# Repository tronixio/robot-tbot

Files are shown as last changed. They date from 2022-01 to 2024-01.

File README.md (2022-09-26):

# ROBOT - TBOT 2 Wheels.

## TBOT Features.

- 2 Wheels.
- Continuous RC Servos Motors.
- Power 2xCells 18650 Lithium Ion Rechargeable Batteries, with embedded charger.
- [PARALLAX Small Robot Chassis.](https://www.parallax.com/product/700-00022)
- [PARALLAX Feedback 360 High Speed Servo.](https://www.parallax.com/product/900-00360)
- [PARALLAX Small Robot Whell and Tire.](https://www.parallax.com/product/28114)
- [PARALLAX 1" Tail Whell Ball.](https://www.parallax.com/product/700-00009)

## TBOT All Schematics.

- [DRAFT - MCU Board PIC-8BIT.](https://github.com/tronixio/robot-tbot/)
- [Charger 2x18650.](https://github.com/tronixio/robot-tbot/blob/main/Kicad/charger/extras/schematic.pdf)
- [DRAFT - IR Wheel.](https://github.com/tronixio/robot-tbot/)
- [Sensor GP2Y.](https://github.com/tronixio/robot-tbot/blob/main/Kicad/gp2y/extras/schematic.pdf)
- [DRAFT - Sensor HC-SR04.](https://github.com/tronixio/robot-tbot/)
- [DRAFT - IR Line Folllow.](https://github.com/tronixio/robot-tbot/)

## TBOT Code.

- [PIC16F1778 - MCU & GPIO Configuration.](https://github.com/tronixio/robot-tbot/blob/main/Code/configuration/)
- [PIC16F1778 - EUSART TX - Display Strings.](https://github.com/tronixio/robot-tbot/blob/main/Code/eusart-tx/)
- [PIC16F1778 - EUSART TX/RX - Echo RX Character.](https://github.com/tronixio/robot-tbot/blob/main/Code/eusart-txrx/)
- [PIC16F1778 - ADC/TIMER0 - Read, Display & Check Battery Value.](https://github.com/tronixio/robot-tbot/blob/main/Code/adc/)
- [PIC16F1778 - PWM 16-Bit - RC Servo Forward & Backward.](https://github.com/tronixio/robot-tbot/blob/main/Code/pwm/)
- [PIC16F1778 - INT0 - Emergency Switch & LED.](https://github.com/tronixio/robot-tbot/blob/main/Code/int0/)
- [PIC16F1778 - IOC - Sharp GP2Y0D21YK.](https://github.com/tronixio/robot-tbot/blob/main/Code/gp2y0d21yk/)

## TBOT Firmware.

- [DRAFT - PIC16F1778 - PIC-AS - Firmware SHARP GP2Y0D21YK.](https://github.com/tronixio/robot-tbot/blob/main/MplabX/PICAS-P16F1778-GP2Y0D21YK.X/)

<!--
* [PIC16F1778 - XC8 - Firmware DEBUG.](https://github.com/tronixio/robot-tbot/tree/main/MplabX/XC8-P16F1778-DEBUG.X/)
* [TBOT Firmware - Sharp GP2Y0D21YK.](https://github.com/tronixio/robot-tbot/tree/main/MplabX/PICAS-P16F1778-GP2Y0D21YK.X)
* [TBOT Firmware - Sharp GP2Y0A21YK.](https://github.com/tronixio/robot-tbot/tree/main/MplabX/PICAS-P16F1778-GP2Y0A21YK.X)
* [TBOT Firmware - HC SR04.](https://github.com/tronixio/robot-tbot/tree/main/MplabX/PICAS-P16F1778-HCSR04.X)
-->

## DRAFT - TBOT MCU PIC 8Bit Top.

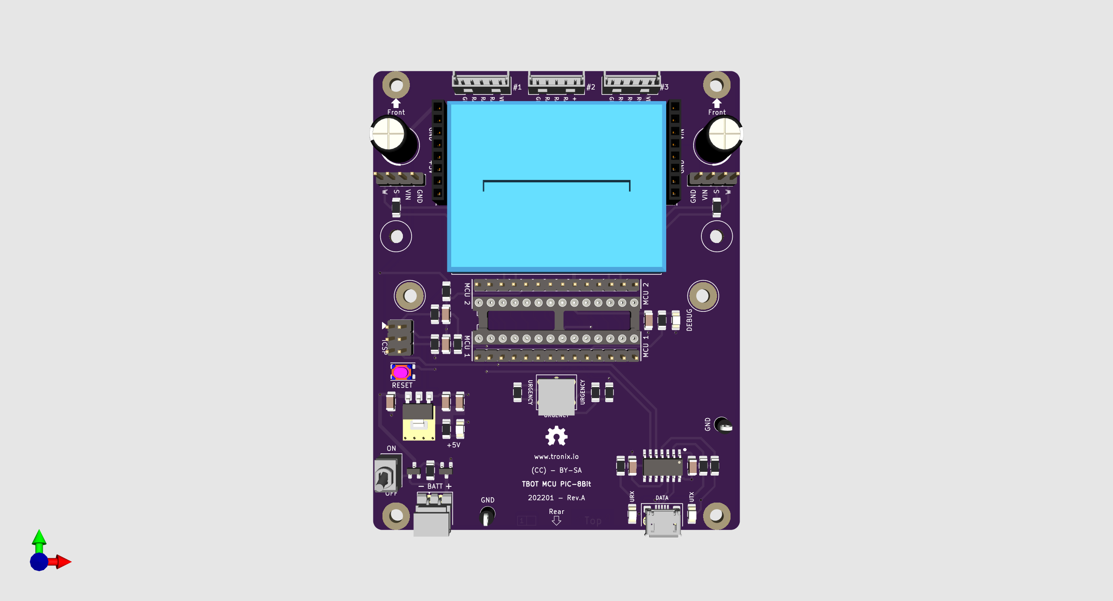
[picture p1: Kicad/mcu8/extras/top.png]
TBOT MCU PIC 8Bit Top.


## DRAFT - TBOT MCU PIC 8Bit Bottom.

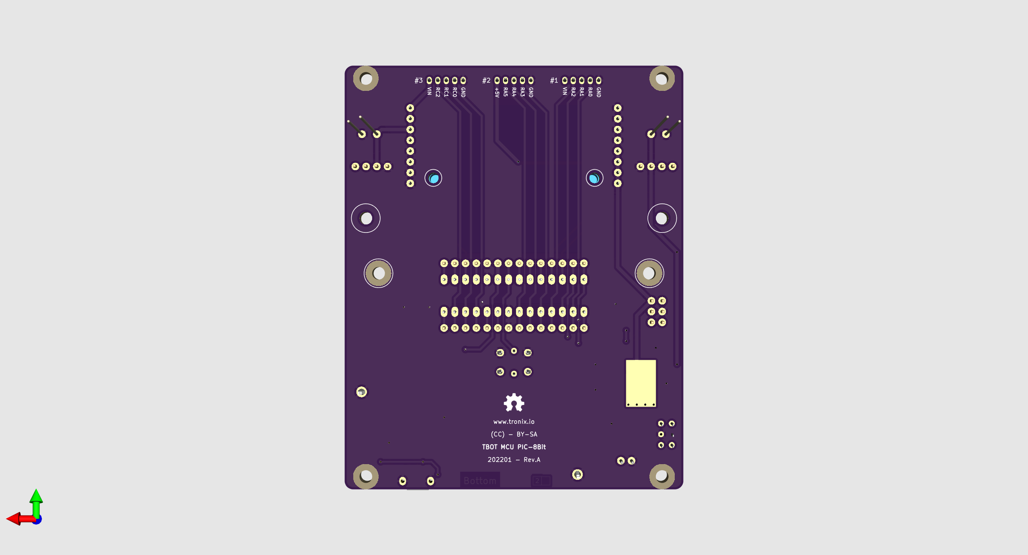
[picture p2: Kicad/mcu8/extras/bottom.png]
TBOT MCU PIC 8Bit Bottom.


## TBOT Charger Top.

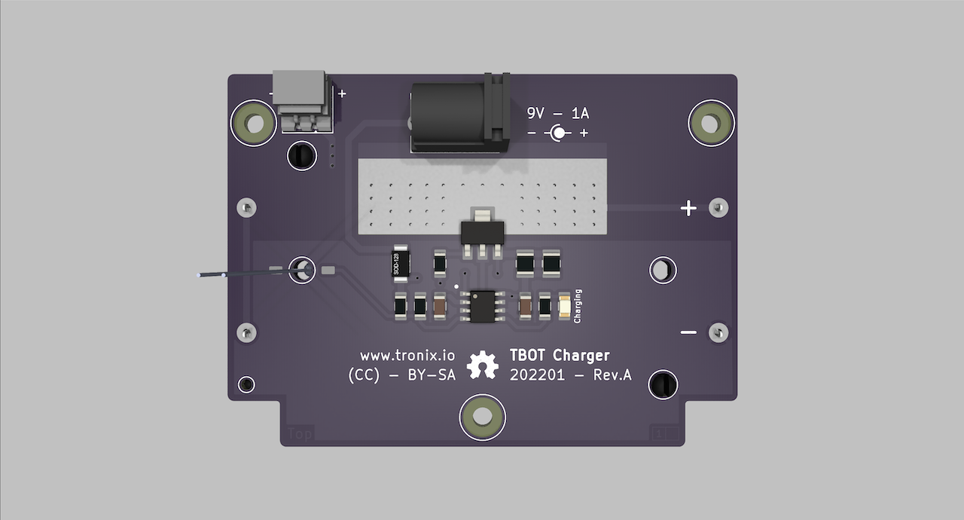
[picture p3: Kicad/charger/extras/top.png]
TBOT Charger Top.


## TBOT Charger Bottom.

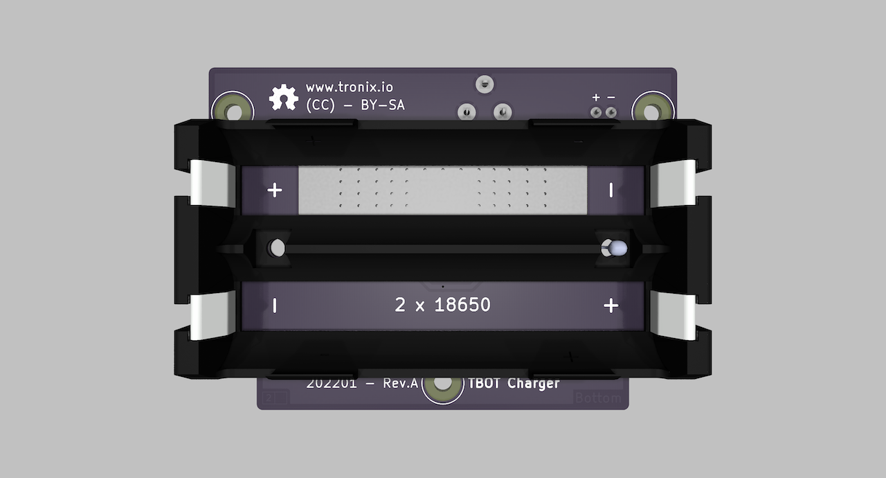
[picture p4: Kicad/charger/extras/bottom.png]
TBOT Charger Bottom.


## DRAFT - TBOT IR Wheel Top.

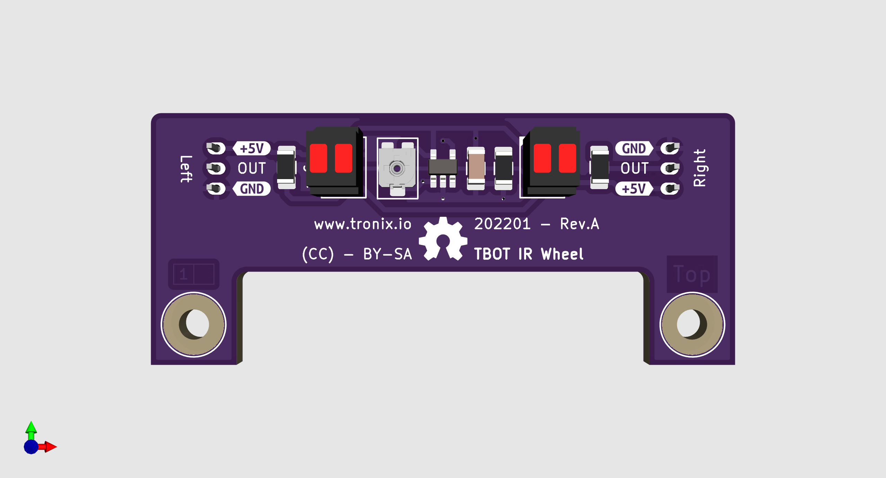
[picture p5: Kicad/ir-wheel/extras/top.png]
TBOT IR Wheel Top.


## DRAFT - TBOT IR Wheel Bottom.

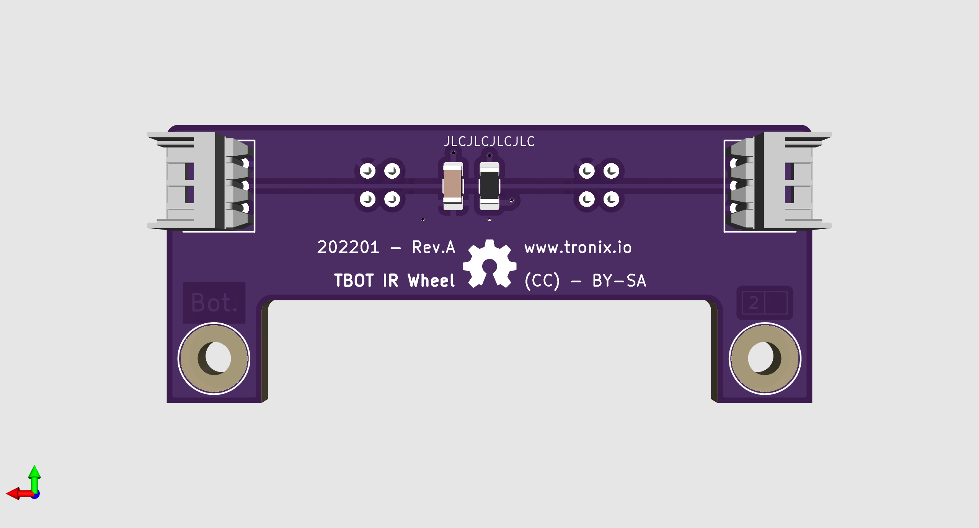
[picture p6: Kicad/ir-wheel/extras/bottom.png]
TBOT IR Wheel Bottom.


## TBOT GP2Y Top.

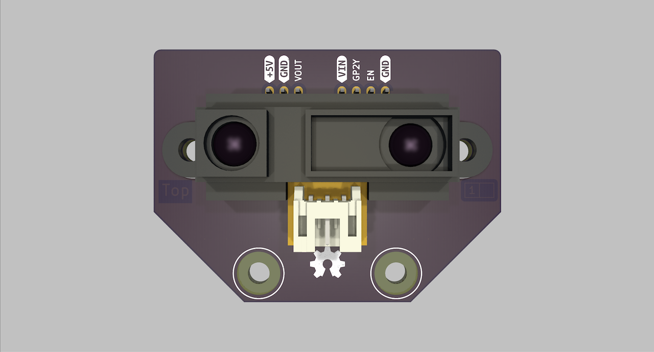
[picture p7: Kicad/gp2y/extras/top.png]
TBOT GP2Y Top.


## TBOT GP2Y Bottom.

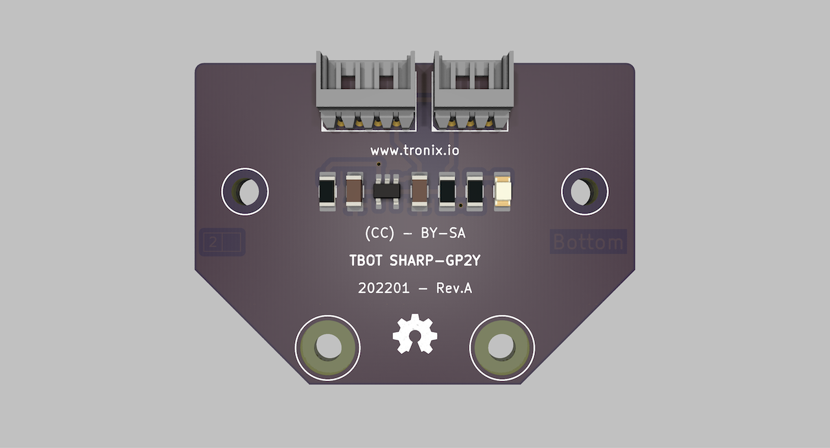
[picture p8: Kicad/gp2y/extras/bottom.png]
TBOT GP2Y Bottom.


## DRAFT - TBOT HC-SR04 Top.

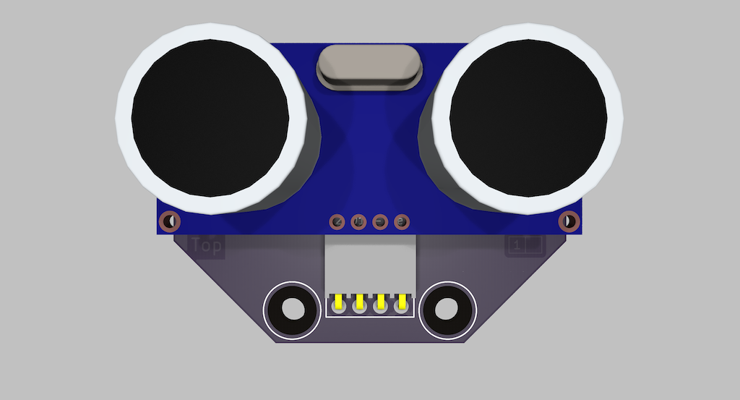
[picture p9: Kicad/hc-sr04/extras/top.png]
TBOT HC-SR04 Top.


## DRAFT - TBOT HC-SR04 Bottom.

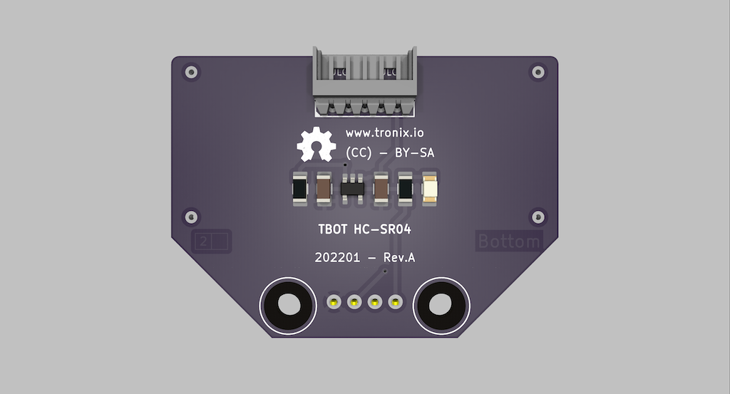
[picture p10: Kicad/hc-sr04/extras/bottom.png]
TBOT HC-SR04 Bottom.


## DRAFT - TBOT IR Line Follow Top.

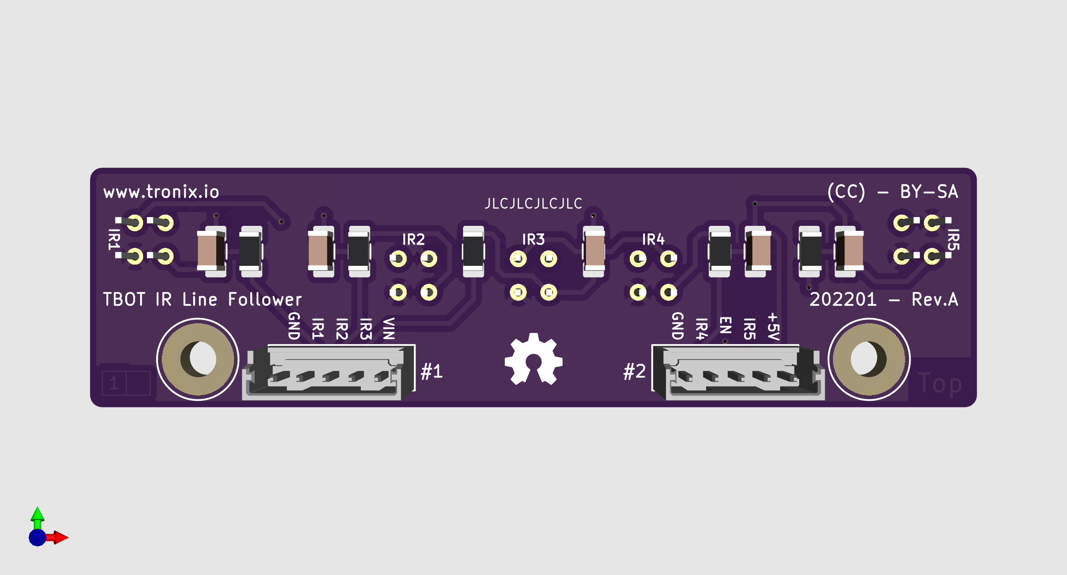
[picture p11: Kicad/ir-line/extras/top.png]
TBOT IR Line Follow Top.


## DRAFT - TBOT IR Line Follow Bottom.

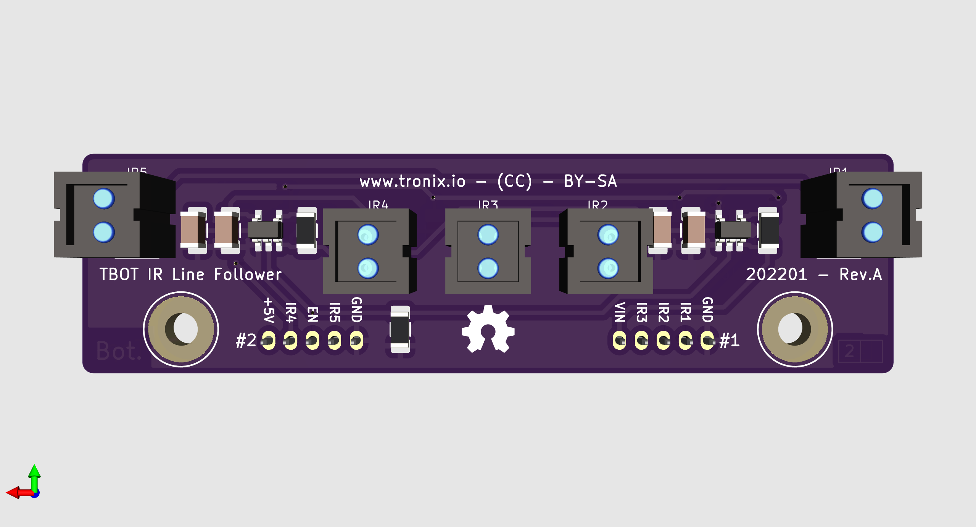
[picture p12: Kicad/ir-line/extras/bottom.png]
TBOT IR Line Follow Bottom.


!!! note

    - DRAFT : Prototype OK, last check schematic, PCB & code can be modify.
    - TODO : Work in progress, prototype was not good, hardware, PCB and code can be rework.

!!! example "DISCLAIMER"

    THIS CODE IS PROVIDED WITHOUT ANY WARRANTY OR GUARANTEES.
    USERS MAY USE THIS CODE FOR DEVELOPMENT AND EXAMPLE PURPOSES ONLY.
    AUTHORS ARE NOT RESPONSIBLE FOR ANY ERRORS, OMISSIONS, OR DAMAGES THAT COULD
    RESULT FROM USING THIS FIRMWARE IN WHOLE OR IN PART.

---

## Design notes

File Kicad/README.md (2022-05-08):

# ROBOT - TBOT 2 Wheels.

- [ROBOT - TBOT 2 Wheels.](https://github.com/tronixio/robot-tbot)

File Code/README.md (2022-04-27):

# ROBOT - TBOT 2 Wheels.

- [TBOT Code.](https://github.com/tronixio/robot-tbot#tbot-code)

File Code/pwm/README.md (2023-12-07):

# PWM - 16-BIT Pulse-Width Modulation Module.

## Code.

- PWM 16-BIT - RC Servo Forward & Backward.

```as
; Configuration Registers.
CONFIG FOSC=INTOSC
CONFIG WDTE=OFF
CONFIG PWRTE=OFF
CONFIG MCLRE=ON
CONFIG CP=OFF
CONFIG BOREN=OFF
CONFIG CLKOUTEN=OFF
CONFIG IESO=OFF
CONFIG FCMEN=OFF
CONFIG WRT=OFF
CONFIG PPS1WAY=ON
CONFIG ZCD=OFF
CONFIG PLLEN=OFF
CONFIG STVREN=ON
CONFIG BORV=LO
CONFIG LPBOR=OFF
CONFIG LVP=ON

#include <xc.inc>
; PIC16F1778 - Compile with PIC-AS(v2.45).
; PIC16F1778 - @8MHz Internal Oscillator.
; -preset_vec=0000h, -pcinit=0005h.
; Instruction ~500ns @8MHz.

; TBOT - PWM.
; RC Servo - Forward 1 second, Stop, Backward 1 second, Stop.

; GPR BANK0.
PSECT cstackBANK0,class=BANK0,space=1,delta=1
u8BANK0:    DS  1

; Common RAM.
PSECT cstackCOMM,class=COMMON,space=1,delta=1
u16DELAY:   DS	2

; MCU Definitions.
; BANKS.
#define	BANK0   0x0
#define	BANK1   0x1
#define	BANK2   0x2
#define	BANK3   0x3
#define	BANK4   0x4
#define	BANK5   0x5
#define	BANK6   0x6
#define	BANK7   0x7
#define	BANK8   0x8
#define	BANK9   0x9
#define	BANK10  0xA
#define	BANK11  0xB
#define	BANK12  0xC
#define	BANK13  0xD
#define	BANK14  0xE
#define	BANK15  0xF
#define	BANK16  0x10
#define	BANK17  0x11
#define	BANK18  0x12
#define	BANK19  0x13
#define	BANK20  0x14
#define	BANK21  0x15
#define	BANK22  0x16
#define	BANK23  0x17
#define	BANK24  0x18
#define	BANK25  0x19
#define	BANK26  0x1A
#define	BANK27  0x1B
#define	BANK28  0x1C
#define	BANK29  0x1D
#define	BANK30  0x1E
#define	BANK31  0x1F
; SFR STATUS Bits.
#define	C	0x0
#define	Z	0x2

; User Definition.
; LED Debug.
#define	LED_DEBUG   0x6
; RC Servo.
; Frequency 50Hz - @8MHz.
#define SERVO_PERIOD_H	78
#define SERVO_PERIOD_L	30
; Duty Cycle.
; H6/L165 - 1.7ms - @8MHz.
; H5/L220 - 1.5ms - @8MHz.
; H5/L20  - 1.3ms - @8MHz.
#define SERVO_STOP_H	5
#define SERVO_STOP_L	220

; Reset Vector.
PSECT reset_vec,class=CODE,space=0,delta=2
resetVector:
    GOTO    main

; Main.
PSECT cinit,class=CODE,space=0,delta=2
main:
    ; MCU Initialization.
    ; Internal Oscillator Settings.
    MOVLB   BANK1
    MOVLW   0b00000000
    MOVWF   OSCTUNE
    MOVLW   0x70
    MOVWF   OSCCON
    BTFSS   HFIOFR
    BRA	    $-1
    ; Ports Settings.
    ; PORT Data Register.
    MOVLB   BANK0
    MOVLW   0b00000000
    MOVWF   PORTA
    MOVLW   0b00000000
    MOVWF   PORTB
    MOVLW   0b00000000
    MOVWF   PORTC
    MOVLW   0b00000000
    MOVWF   PORTE
    ; TRIS Data Direction.
    MOVLB   BANK1
    MOVLW   0b00000000
    MOVWF   TRISA
    MOVLW   0b10011001
    MOVWF   TRISB
    MOVLW   0b01000000
    MOVWF   TRISC
    MOVLW   0b00000000
    MOVWF   TRISE
    ; LATCH Outputs.
    MOVLB   BANK2
    MOVLW   0b00000000
    MOVWF   LATA
    MOVLW   0b00000000
    MOVWF   LATB
    MOVLW   0b00000000
    MOVWF   LATC
    ; ANSEL Analog.
    MOVLB   BANK3
    MOVLW   0b00000000
    MOVWF   ANSELA
    MOVLW   0b00001000
    MOVWF   ANSELB
    MOVLW   0b00000000
    MOVWF   ANSELC
    ; WPU Weak Pull-up.
    MOVLB   BANK4
    MOVLW   0b00000000
    MOVWF   WPUA
    MOVLW   0b00000000
    MOVWF   WPUB
    MOVLW   0b00000000
    MOVWF   WPUC
    MOVLW   0b00000000
    MOVWF   WPUE
    ; ODCON Open-drain.
    MOVLB   BANK5
    MOVLW   0b00000000
    MOVWF   ODCONA
    MOVLW   0b00000000
    MOVWF   ODCONB
    MOVLW   0b00000000
    MOVWF   ODCONC
    ; SRLCON Slew Rate.
    MOVLB   BANK6
    MOVLW   0b11111111
    MOVWF   SLRCONA
    MOVLW   0b11011111
    MOVWF   SLRCONB
    MOVLW   0b11011111
    MOVWF   SLRCONC
    ; INLVL Input Level.
    MOVLB   BANK7
    MOVLW   0b00000000
    MOVWF   INLVLA
    MOVLW   0b00000000
    MOVWF   INLVLB
    MOVLW   0b00000000
    MOVWF   INLVLC
    ; HIDRVB High Drive.
    MOVLB   BANK8
    MOVLW   0b00000000
    MOVWF   HIDRVB
    ; PPS Settings.
    ; PPS Write Enable.
    MOVLB   BANK28
    MOVLW   0x55
    MOVWF   PPSLOCK
    MOVLW   0xAA
    MOVWF   PPSLOCK
    BCF	    PPSLOCK, 0x0
    ; PPS Outputs.
    MOVLB   BANK29
    ; RB5 - PWM11.
    MOVLW   0x1F
    MOVWF   RB5PPS
    ; RC5 - PWM6.
    MOVLW   0x1E
    MOVWF   RC5PPS
    ; PPS Write Disable.
    MOVLB   BANK28
    MOVLW   0x55
    MOVWF   PPSLOCK
    MOVLW   0xAA
    MOVWF   PPSLOCK
    BSF	    PPSLOCK, 0x0

    ; PWM6 Settings.
    MOVLB   BANK27
    CLRF    PWM6PHL
    CLRF    PWM6PHH
    MOVLW   SERVO_STOP_L
    MOVWF   PWM6DCL
    MOVLW   SERVO_STOP_H
    MOVWF   PWM6DCH
    MOVLW   SERVO_PERIOD_L
    MOVWF   PWM6PRL
    MOVLW   SERVO_PERIOD_H
    MOVWF   PWM6PRH
    CLRF    PWM6OFL
    CLRF    PWM6OFH
    CLRF    PWM6TMRL
    CLRF    PWM6TMRH
    MOVLW   0x0C
    MOVWF   PWM6CON
    MOVLW   0x00
    MOVWF   PWM6INTE
    MOVLW   0x00
    MOVWF   PWM6INTF
    MOVLW   0x20
    MOVWF   PWM6CLKCON
    MOVLW   0x00
    MOVWF   PWM6LDCON
    MOVLW   0x00
    MOVWF   PWM6OFCON
    ; PWM6 Load & Enable.
    BSF	    PWM6LD
    BSF	    PWM6EN

    ; PWM11 Settings.
    MOVLB   BANK27
    CLRF    PWM11PHL
    CLRF    PWM11PHH
    MOVLW   SERVO_STOP_L
    MOVWF   PWM11DCL
    MOVLW   SERVO_STOP_H
    MOVWF   PWM11DCH
    MOVLW   SERVO_PERIOD_L
    MOVWF   PWM11PRL
    MOVLW   SERVO_PERIOD_H
    MOVWF   PWM11PRH
    CLRF    PWM11OFL
    CLRF    PWM11OFH
    CLRF    PWM11TMRL
    CLRF    PWM11TMRH
    MOVLW   0x0C
    MOVWF   PWM11CON
    MOVLW   0x00
    MOVWF   PWM11INTE
    MOVLW   0x00
    MOVWF   PWM11INTF
    MOVLW   0x20
    MOVWF   PWM11CLKCON
    MOVLW   0x00
    MOVWF   PWM11LDCON
    MOVLW   0x00
    MOVWF   PWM11OFCON
    ; PWM11 Load & Enable.
    BSF	    PWM11LD
    BSF	    PWM11EN

loop:
    ; RC Servos Forward.
    MOVLB   BANK27
    MOVLW   20
    MOVWF   PWM6DCL
    MOVLW   5
    MOVWF   PWM6DCH
    MOVLW   165
    MOVWF   PWM11DCL
    MOVLW   6
    MOVWF   PWM11DCH
    MOVLW   0x6
    MOVWF   PWMLD
    MOVLW   10
    CALL    _u16Delay

    ; RC Servos Stop.
    MOVLB   BANK27
    MOVLW   SERVO_STOP_L
    MOVWF   PWM6DCL
    MOVLW   SERVO_STOP_H
    MOVWF   PWM6DCH
    MOVLW   SERVO_STOP_L
    MOVWF   PWM11DCL
    MOVLW   SERVO_STOP_H
    MOVWF   PWM11DCH
    MOVLW   0x6
    MOVWF   PWMLD
    MOVLW   10
    CALL    _u16Delay

    ; RC Servos Backward.
    MOVLB   BANK27
    MOVLW   165
    MOVWF   PWM6DCL
    MOVLW   6
    MOVWF   PWM6DCH
    MOVLW   20
    MOVWF   PWM11DCL
    MOVLW   5
    MOVWF   PWM11DCH
    MOVLW   0x6
    MOVWF   PWMLD
    MOVLW   10
    CALL    _u16Delay

    ; RC Servos Stop.
    MOVLB   BANK27
    MOVLW   SERVO_STOP_L
    MOVWF   PWM6DCL
    MOVLW   SERVO_STOP_H
    MOVWF   PWM6DCH
    MOVLW   SERVO_STOP_L
    MOVWF   PWM11DCL
    MOVLW   SERVO_STOP_H
    MOVWF   PWM11DCH
    MOVLW   0x6
    MOVWF   PWMLD
    MOVLW   10
    CALL    _u16Delay

    BRA	    $

; Functions.
_u16Delay:
    MOVWF   u16DELAY
    MOVLW   255
    MOVWF   u16DELAY + 1
    MOVLW   255
    DECFSZ  WREG, F
    BRA	    $-1
    DECFSZ  u16DELAY + 1, F
    BRA	    $-3
    DECFSZ  u16DELAY, F
    BRA	    $-5
    RETURN

    END resetVector
```

## Oscilloscope.

### Stop.

- MCU.RC5.PWM.6  -> Oscilloscope Probe A
- MCU.RB5.PWM.11 -> Oscilloscope Probe B

<p align="center">
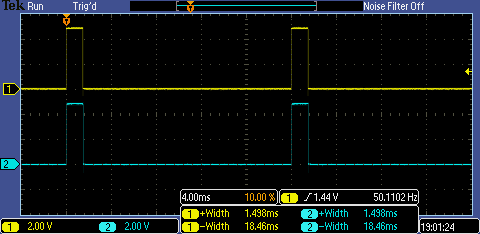
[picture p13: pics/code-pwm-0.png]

</p>

### Forward.

- MCU.RC5.PWM.6  -> Oscilloscope Probe A
- MCU.RB5.PWM.11 -> Oscilloscope Probe B

<p align="center">
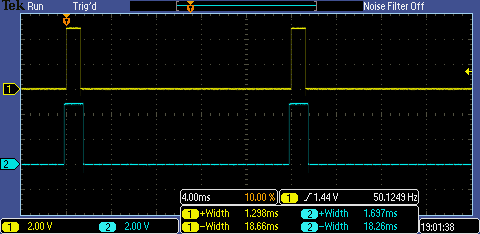
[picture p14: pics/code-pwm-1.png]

</p>

### Backward.

- MCU.RC5.PWM.6  -> Oscilloscope Probe A
- MCU.RB5.PWM.11 -> Oscilloscope Probe B

<p align="center">
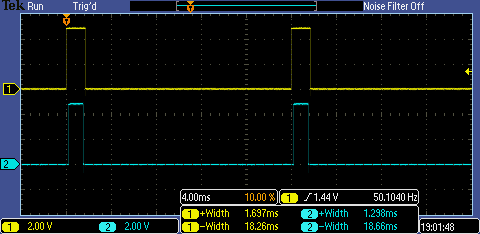
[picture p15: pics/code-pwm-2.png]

</p>

## MPLABX Linker Configuration.

- PIC-AS Linker > Custom linker options: `-preset_vec=0000h, -pcinit=0005h`

## Notes.

- TODO : Work in progress, prototype was not good, hardware, PCB and code can be rework.
- DRAFT : Prototype OK, last check schematic, PCB & code can be modify.

## DISCLAIMER.

THIS CODE IS PROVIDED WITHOUT ANY WARRANTY OR GUARANTEES.
USERS MAY USE THIS CODE FOR DEVELOPMENT AND EXAMPLE PURPOSES ONLY.
AUTHORS ARE NOT RESPONSIBLE FOR ANY ERRORS, OMISSIONS, OR DAMAGES THAT COULD
RESULT FROM USING THIS FIRMWARE IN WHOLE OR IN PART.

---

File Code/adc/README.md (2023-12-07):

# ADC - 10-Bit Analog-to-Digital Converter.

## Code.

- ADC/TIMER0 - Read, Display & Check Battery Value.

```as
; Configuration Registers.
CONFIG FOSC=INTOSC
CONFIG WDTE=OFF
CONFIG PWRTE=OFF
CONFIG MCLRE=ON
CONFIG CP=OFF
CONFIG BOREN=OFF
CONFIG CLKOUTEN=OFF
CONFIG IESO=OFF
CONFIG FCMEN=OFF
CONFIG WRT=OFF
CONFIG PPS1WAY=ON
CONFIG ZCD=OFF
CONFIG PLLEN=OFF
CONFIG STVREN=ON
CONFIG BORV=LO
CONFIG LPBOR=OFF
CONFIG LVP=ON

#include <xc.inc>
; PIC16F1778 - Compile with PIC-AS(v2.45).
; PIC16F1778 - @8MHz Internal Oscillator.
; -preset_vec=0000h, -pstringtext=3FB0h.
; Instruction ~500ns @8MHz.

; TBOT - ADC/TIMER0.

; ADC - Read Battery Voltage.
; TIMER0 - ADC Auto-convertion Trigger Source.
; EUSART TX - Display Battery value.

; Battery Voltage: 8V4 -> 0xF7.
; Battery Voltage: 6V2 -> 0xB7.

; GPR BANK0.
PSECT cstackBANK0,class=BANK0,space=1,delta=1
u32Ascii:   DS  4

; Common RAM.
PSECT cstackCOMM,class=COMMON,space=1,delta=1
u16DELAY:   DS	2

; MCU Definitions.
; BANKS.
#define	BANK0   0x0
#define	BANK1   0x1
#define	BANK2   0x2
#define	BANK3   0x3
#define	BANK4   0x4
#define	BANK5   0x5
#define	BANK6   0x6
#define	BANK7   0x7
#define	BANK8   0x8
#define	BANK9   0x9
#define	BANK10  0xA
#define	BANK11  0xB
#define	BANK12  0xC
#define	BANK13  0xD
#define	BANK14  0xE
#define	BANK15  0xF
#define	BANK16  0x10
#define	BANK17  0x11
#define	BANK18  0x12
#define	BANK19  0x13
#define	BANK20  0x14
#define	BANK21  0x15
#define	BANK22  0x16
#define	BANK23  0x17
#define	BANK24  0x18
#define	BANK25  0x19
#define	BANK26  0x1A
#define	BANK27  0x1B
#define	BANK28  0x1C
#define	BANK29  0x1D
#define	BANK30  0x1E
#define	BANK31  0x1F
; SFR STATUS Bits.
#define	C	0x0
#define	Z	0x2

; User Definition.
; LED Debug.
#define	LED_DEBUG	0x6
; Battery Definitions.
#define	BATTERY_LOW	0xB7

; Reset Vector.
PSECT reset_vec,class=CODE,space=0,delta=2
resetVector:
    GOTO    main

; Main.
PSECT cinit,class=CODE,space=0,delta=2
main:
    ; MCU Initialization.
    ; Internal Oscillator Settings.
    MOVLB   BANK1
    MOVLW   0b00000000
    MOVWF   OSCTUNE
    MOVLW   0x70
    MOVWF   OSCCON
    BTFSS   HFIOFR
    BRA	    $-1
    ; Ports Settings.
    ; PORT Data Register.
    MOVLB   BANK0
    MOVLW   0b00000000
    MOVWF   PORTA
    MOVLW   0b00000000
    MOVWF   PORTB
    MOVLW   0b00000000
    MOVWF   PORTC
    MOVLW   0b00000000
    MOVWF   PORTE
    ; TRIS Data Direction.
    MOVLB   BANK1
    MOVLW   0b00000000
    MOVWF   TRISA
    MOVLW   0b10001000
    MOVWF   TRISB
    MOVLW   0b00000000
    MOVWF   TRISC
    MOVLW   0b00000000
    MOVWF   TRISE
    ; LATCH Outputs.
    MOVLB   BANK2
    MOVLW   0b00000000
    MOVWF   LATA
    MOVLW   0b00000000
    MOVWF   LATB
    MOVLW   0b00000000
    MOVWF   LATC
    ; ANSEL Analog.
    MOVLB   BANK3
    MOVLW   0b00000000
    MOVWF   ANSELA
    MOVLW   0b00001000
    MOVWF   ANSELB
    MOVLW   0b00000000
    MOVWF   ANSELC
    ; WPU Weak Pull-up.
    MOVLB   BANK4
    MOVLW   0b00000000
    MOVWF   WPUA
    MOVLW   0b00000000
    MOVWF   WPUB
    MOVLW   0b00000000
    MOVWF   WPUC
    MOVLW   0b00000000
    MOVWF   WPUE
    ; ODCON Open-drain.
    MOVLB   BANK5
    MOVLW   0b00000000
    MOVWF   ODCONA
    MOVLW   0b00000000
    MOVWF   ODCONB
    MOVLW   0b00000000
    MOVWF   ODCONC
    ; SRLCON Slew Rate.
    MOVLB   BANK6
    MOVLW   0b11111111
    MOVWF   SLRCONA
    MOVLW   0b11111111
    MOVWF   SLRCONB
    MOVLW   0b11111111
    MOVWF   SLRCONC
    ; INLVL Input Level.
    MOVLB   BANK7
    MOVLW   0b00000000
    MOVWF   INLVLA
    MOVLW   0b00000000
    MOVWF   INLVLB
    MOVLW   0b00000000
    MOVWF   INLVLC
    ; HIDRVB High Drive.
    MOVLB   BANK8
    MOVLW   0b00000000
    MOVWF   HIDRVB
    ; PPS Settings.
    ; PPS Write Enable.
    MOVLB   BANK28
    MOVLW   0x55
    MOVWF   PPSLOCK
    MOVLW   0xAA
    MOVWF   PPSLOCK
    BCF	    PPSLOCK, 0x0
    ; PPS Outputs.
    MOVLB   BANK29
    ; RB6 - EUSART.UTX.
    MOVLW   0x24
    MOVWF   RB6PPS
    ; PPS Write Disable.
    MOVLB   BANK28
    MOVLW   0x55
    MOVWF   PPSLOCK
    MOVLW   0xAA
    MOVWF   PPSLOCK
    BSF	    PPSLOCK, 0x0

    ; ADC Settings.
    ; TIMER0 Overflow Trigger.
    ; Left Justified, FOSC/16.
    MOVLB   BANK9
    CLRF    ADRESL
    CLRF    ADRESH
    MOVLW   0x24
    MOVWF   ADCON0
    MOVLW   0x50
    MOVWF   ADCON1
    MOVLW   0x02
    MOVWF   ADCON2
    ; ADC Enable.
    BSF	    ADON

    ; EUSART Settings.
    ; 9600,8,N,1.
    MOVLB   BANK3
    CLRF    RC1REG
    CLRF    TX1REG
    MOVLW   12
    MOVWF   SP1BRGL
    CLRF    SP1BRGH
    MOVLW   0x10
    MOVWF   RC1STA
    MOVLW   0x20
    MOVWF   TX1STA
    MOVLW   0x00
    MOVWF   BAUD1CON
    ; EUSART Enable.
    BSF	    SPEN

    ; OPTION REG Settings.
    ; WPU Enabled.
    ; TIMER0 ~15Hz.
    MOVLB   BANK1
    MOVLW   0b01010111
    MOVWF   OPTION_REG

    ; EUSART Display Strings.
    CALL    _writeStringTRONIX
    CALL    _writeStringURL
    CALL    _writeStringTBOT
    CALL    _writeStringREADY

loop:
    ; Check Battery Voltage Low.
    MOVLW   BATTERY_LOW
    MOVLB   BANK9
    SUBWF   ADRESH, W
    BTFSC   STATUS, C
    BRA	    $+6
    CALL    _writeStringREADY
    CALL    _writeStringBATTERYLOW
    MOVLW   10
    CALL    _u16Delay
    BRA	    loop

    ; Display Battery Value.
    CALL    _writeStringREADY
    MOVLW   '0'
    CALL    _eusartTX
    MOVLW   'x'
    CALL    _eusartTX
    MOVLB   BANK9
    MOVF    ADRESH, W
    CALL    _hex2ascii
    CALL    _writeStringASCII
    MOVLW   10
    CALL    _u16Delay

    BRA	    loop

; Functions.
_u16Delay:
    MOVWF   u16DELAY
    MOVLW   255
    MOVWF   u16DELAY + 1
    MOVLW   255
    DECFSZ  WREG, F
    BRA	    $-1
    DECFSZ  u16DELAY + 1, F
    BRA	    $-3
    DECFSZ  u16DELAY, F
    BRA	    $-5
    RETURN

_eusartTX:
    MOVLB   BANK3
    MOVWF   TX1REG
    MOVLB   BANK0
    BTFSS   TXIF
    BRA	    $-1
    RETURN

_eusartTXString:
    MOVIW   FSR0++
    ANDLW   0xFF
    BTFSC   STATUS, Z
    RETURN
    CALL    _eusartTX
    BRA	    $-5

_hex2ascii:
    MOVLB   BANK0
    MOVWF   u32Ascii
    ANDLW   0x0F
    CALL    $+9
    MOVWF   u32Ascii + 2
    SWAPF   u32Ascii, F
    MOVF    u32Ascii, W
    ANDLW   0x0F
    CALL    $+4
    MOVWF   u32Ascii + 1
    CLRF    u32Ascii + 3
    RETURN
    ; Decimal or Alpha ?
    SUBLW   0x09
    BTFSS   STATUS, C
    BRA	    $+5
    ; Decimal (0...9) add 0x30.
    MOVF    u32Ascii, W
    ANDLW   0x0F
    ADDLW   0x30
    RETURN
    ; Alpha (A...F) add 0x37.
    MOVF    u32Ascii, W
    ANDLW   0x0F
    ADDLW   'A' - 0x0A
    RETURN

_writeStringASCII:
    MOVLB   BANK0
    MOVLW   u32Ascii + 1
    MOVWF   FSR0L
    CLRF    FSR0H
    CALL    _eusartTXString
    RETURN

_writeStringBATTERYLOW:
    MOVLW   LOW stringBATTERYLOW
    MOVWF   FSR0L
    MOVLW   HIGH stringBATTERYLOW + 0x80
    MOVWF   FSR0H
    CALL    _eusartTXString
    RETURN

_writeStringREADY:
    MOVLW   LOW stringREADY
    MOVWF   FSR0L
    MOVLW   HIGH stringREADY + 0x80
    MOVWF   FSR0H
    CALL    _eusartTXString
    RETURN

_writeStringTBOT:
    MOVLW   LOW stringTBOT
    MOVWF   FSR0L
    MOVLW   HIGH stringTBOT + 0x80
    MOVWF   FSR0H
    CALL    _eusartTXString
    RETURN

_writeStringTRONIX:
    MOVLW   LOW stringTRONIX
    MOVWF   FSR0L
    MOVLW   HIGH stringTRONIX + 0x80
    MOVWF   FSR0H
    CALL    _eusartTXString
    RETURN

_writeStringURL:
    MOVLW   LOW stringURL
    MOVWF   FSR0L
    MOVLW   HIGH stringURL + 0x80
    MOVWF   FSR0H
    CALL    _eusartTXString
    RETURN

; FPM Strings.
PSECT stringtext,class=STRCODE,space=0,delta=2

stringBATTERYLOW:
    DB  'B','a','t','t','e','r','y', ' ', 'L', 'o', 'w', '!', 0x0

stringREADY:
    DB  0xD, 0xA, 'R','e','a','d','y','>',' ', 0x0

stringTBOT:
    DB  0xD, 0xA, 'T','B','O','T', 0xD, 0xA, 0x0

stringTRONIX:
    DB  0xD, 0xA, 0xD, 0xA, 'T','r','o','n','i','x',' ','I','/','O','.', 0x0

stringURL:
    DB  0xD, 0xA, 'w','w','w','.','t','r','o','n','i','x','.','c','o','m', 0x0

    END	resetVector
```

## Terminal.

- EUSART TX - Display Strings.
  - Mac OS: `screen /dev/cu.usbmodemXXXXXX`
  
<p align="center">
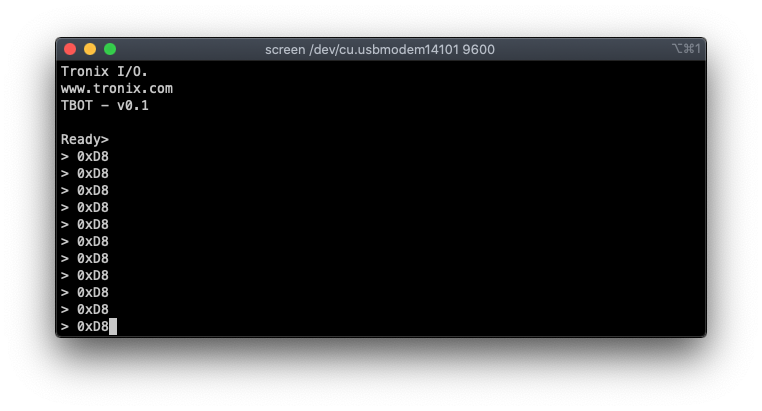
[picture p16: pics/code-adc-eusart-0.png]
MCU.RB6.EUSART.TX

</p>

## MPLABX Linker Configuration.

- PIC-AS Linker > Custom linker options : `-preset_vec=0000h, -pstringtext=3FC0h`

## Notes.

- TODO : Work in progress, prototype was not good, hardware, PCB and code can be rework.
- DRAFT : Prototype OK, last check schematic, PCB & code can be modify.

## DISCLAIMER.

THIS CODE IS PROVIDED WITHOUT ANY WARRANTY OR GUARANTEES.
USERS MAY USE THIS CODE FOR DEVELOPMENT AND EXAMPLE PURPOSES ONLY.
AUTHORS ARE NOT RESPONSIBLE FOR ANY ERRORS, OMISSIONS, OR DAMAGES THAT COULD
RESULT FROM USING THIS FIRMWARE IN WHOLE OR IN PART.

---

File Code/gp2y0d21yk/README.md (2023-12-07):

# IOC - Interrupt-On-Change.

## Code.

- IOC - Sharp GP2Y0D21YK.

```as
; Configuration Registers.
CONFIG FOSC=INTOSC
CONFIG WDTE=OFF
CONFIG PWRTE=OFF
CONFIG MCLRE=ON
CONFIG CP=OFF
CONFIG BOREN=OFF
CONFIG CLKOUTEN=OFF
CONFIG IESO=OFF
CONFIG FCMEN=OFF
CONFIG WRT=OFF
CONFIG PPS1WAY=ON
CONFIG ZCD=OFF
CONFIG PLLEN=OFF
CONFIG STVREN=ON
CONFIG BORV=LO
CONFIG LPBOR=OFF
CONFIG LVP=ON

#include <xc.inc>
; PIC16F1778 - Compile with PIC-AS(v2.45).
; PIC16F1778 - @8MHz Internal Oscillator.
; -preset_vec=0000h, -pintentry=0004h, -pcinit=0005h.
; Instruction ~500ns @8MHz.

; TBOT - IOC - Interrupt On Change.

; Sensor Sharp GP2Y0D21YK - Rising & Falling Edge Detection.

; GPR BANK0.
PSECT cstackBANK0,class=BANK0,space=1,delta=1
u8BANK0:    DS  1

; Common RAM.
PSECT cstackCOMM,class=COMMON,space=1,delta=1
u8DELAY:    DS	1

; MCU Definitions.
; BANKS.
#define	BANK0   0x0
#define	BANK1   0x1
#define	BANK2   0x2
#define	BANK3   0x3
#define	BANK4   0x4
#define	BANK5   0x5
#define	BANK6   0x6
#define	BANK7   0x7
#define	BANK8   0x8
#define	BANK9   0x9
#define	BANK10  0xA
#define	BANK11  0xB
#define	BANK12  0xC
#define	BANK13  0xD
#define	BANK14  0xE
#define	BANK15  0xF
#define	BANK16  0x10
#define	BANK17  0x11
#define	BANK18  0x12
#define	BANK19  0x13
#define	BANK20  0x14
#define	BANK21  0x15
#define	BANK22  0x16
#define	BANK23  0x17
#define	BANK24  0x18
#define	BANK25  0x19
#define	BANK26  0x1A
#define	BANK27  0x1B
#define	BANK28  0x1C
#define	BANK29  0x1D
#define	BANK30  0x1E
#define	BANK31  0x1F
; SFR STATUS Bits.
#define	C	0x0
#define	Z	0x2

; User Definition.
; LED Debug.
#define	LED_DEBUG       0x6
; Sharp GP2Y0D21YK.
#define GP2Y0D21_60MS   160
#define GP2Y0D21_ENABLE 0x0
#define GP2Y0D21_OUT    0x2

; Reset Vector.
PSECT reset_vec,class=CODE,space=0,delta=2
resetVector:
    GOTO    main

; ISR Vector.
PSECT intentry,class=CODE,space=0,delta=2
interruptVector:
    GOTO    isr

; Main.
PSECT cinit,class=CODE,space=0,delta=2
main:
    ; MCU Initialization.
    ; Internal Oscillator Settings.
    MOVLB   BANK1
    MOVLW   0b00000000
    MOVWF   OSCTUNE
    MOVLW   0x70
    MOVWF   OSCCON
    BTFSS   HFIOFR
    BRA	    $-1
    ; Ports Settings.
    ; PORT Data Register.
    MOVLB   BANK0
    MOVLW   0b00000000
    MOVWF   PORTA
    MOVLW   0b00000000
    MOVWF   PORTB
    MOVLW   0b00000000
    MOVWF   PORTC
    MOVLW   0b00000000
    MOVWF   PORTE
    ; TRIS Data Direction.
    MOVLB   BANK1
    MOVLW   0b00000000
    MOVWF   TRISA
    MOVLW   0b00000000
    MOVWF   TRISB
    MOVLW   0b00000100
    MOVWF   TRISC
    MOVLW   0b00000000
    MOVWF   TRISE
    ; LATCH Outputs.
    MOVLB   BANK2
    MOVLW   0b00000000
    MOVWF   LATA
    MOVLW   0b00000000
    MOVWF   LATB
    MOVLW   0b00000000
    MOVWF   LATC
    ; ANSEL Analog.
    MOVLB   BANK3
    MOVLW   0b00000000
    MOVWF   ANSELA
    MOVLW   0b00000000
    MOVWF   ANSELB
    MOVLW   0b00000000
    MOVWF   ANSELC
    ; WPU Weak Pull-up.
    MOVLB   BANK4
    MOVLW   0b00000000
    MOVWF   WPUA
    MOVLW   0b00000000
    MOVWF   WPUB
    MOVLW   0b00000100
    MOVWF   WPUC
    MOVLW   0b00000000
    MOVWF   WPUE
    ; ODCON Open-drain.
    MOVLB   BANK5
    MOVLW   0b00000000
    MOVWF   ODCONA
    MOVLW   0b00000000
    MOVWF   ODCONB
    MOVLW   0b00000000
    MOVWF   ODCONC
    ; SRLCON Slew Rate.
    MOVLB   BANK6
    MOVLW   0b11111111
    MOVWF   SLRCONA
    MOVLW   0b11111111
    MOVWF   SLRCONB
    MOVLW   0b11111111
    MOVWF   SLRCONC
    ; INLVL Input Level.
    MOVLB   BANK7
    MOVLW   0b00000000
    MOVWF   INLVLA
    MOVLW   0b00000000
    MOVWF   INLVLB
    MOVLW   0b00000000
    MOVWF   INLVLC
    ; HIDRVB High Drive.
    MOVLB   BANK8
    MOVLW   0b00000000
    MOVWF   HIDRVB

    ; OPTION REG Settings.
    ; WPU Enabled.
    MOVLB   BANK1
    MOVLW   0b01111111
    MOVWF   OPTION_REG

    ; GP2Y0D21 Enable.
    MOVLB   BANK2
    BSF	    LATC, GP2Y0D21_ENABLE
    ; Wait ~60ms.
    MOVLW   GP2Y0D21_60MS
    CALL    _u8Delay
    ; IOC Settings.
    MOVLB   BANK7
    BSF	    IOCCP, GP2Y0D21_OUT
    BSF	    IOCCN, GP2Y0D21_OUT
    CLRF    IOCCF

    ; INTERRUPTS Settings.
    BSF	    IOCIE
    BCF	    IOCIF
    ; INTERRUPTS Enabled.
    BSF	    GIE

loop:
    BRA	    $

;  Interrupt Service Routine.
isr:
    ; Interrupt On Change ?
    BTFSS   IOCIF
    RETFIE
    MOVLB   BANK7
    BTFSS   IOCCF, GP2Y0D21_OUT
    RETFIE
    MOVLB   BANK0
    BTFSC   PORTC, GP2Y0D21_OUT
    BRA	    $+4
    MOVLB   BANK2
    BCF	    LATA, LED_DEBUG
    BRA	    $+3
    MOVLB   BANK2
    BSF	    LATA, LED_DEBUG
    MOVLB   BANK7
    BCF	    IOCCF, GP2Y0D21_OUT
    BCF	    IOCIF
    RETFIE

; Functions.
_u8Delay:
    MOVWF   u8DELAY
    MOVLW   255
    DECFSZ  WREG, F
    BRA	    $-1
    DECFSZ  u8DELAY, F
    BRA	    $-3
    RETURN

    END resetVector
```

## MPLABX Linker Configuration.

- PIC-AS Linker > Custom linker options: `-preset_vec=0000h, -pintentry=0004h, -pcinit=0005h`

## Notes.

- TODO : Work in progress, prototype was not good, hardware, PCB and code can be rework.
- DRAFT : Prototype OK, last check schematic, PCB & code can be modify.

## DISCLAIMER.

THIS CODE IS PROVIDED WITHOUT ANY WARRANTY OR GUARANTEES.
USERS MAY USE THIS CODE FOR DEVELOPMENT AND EXAMPLE PURPOSES ONLY.
AUTHORS ARE NOT RESPONSIBLE FOR ANY ERRORS, OMISSIONS, OR DAMAGES THAT COULD
RESULT FROM USING THIS FIRMWARE IN WHOLE OR IN PART.

---

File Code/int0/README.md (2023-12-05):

# Interrupts - INT0.

## Code.

- INT0 - Stop Switch & LED.

```as
; Configuration Registers.
CONFIG FOSC=INTOSC
CONFIG WDTE=OFF
CONFIG PWRTE=OFF
CONFIG MCLRE=ON
CONFIG CP=OFF
CONFIG BOREN=OFF
CONFIG CLKOUTEN=OFF
CONFIG IESO=OFF
CONFIG FCMEN=OFF
CONFIG WRT=OFF
CONFIG PPS1WAY=ON
CONFIG ZCD=OFF
CONFIG PLLEN=OFF
CONFIG STVREN=ON
CONFIG BORV=LO
CONFIG LPBOR=OFF
CONFIG LVP=ON

#include <xc.inc>
; PIC16F1778 - Compile with PIC-AS(v2.45).
; PIC16F1778 - @8MHz Internal Oscillator.
; -preset_vec=0000h, -pintentry=0004h, -pcinit=0005h.
; Instruction ~500ns @8MHz.

; TBOT - INT0 - Interrupt.

; Emergency Switch & LED - Rising Edge Detection.

; GPR BANK0.
PSECT cstackBANK0,class=BANK0,space=1,delta=1
u8BANK0:    DS  1
    
; Common RAM.
PSECT cstackCOMM,class=COMMON,space=1,delta=1
u8DELAY:    DS	1

; MCU Definitions.
; BANKS.
#define	BANK0   0x0
#define	BANK1   0x1
#define	BANK2   0x2
#define	BANK3   0x3
#define	BANK4   0x4
#define	BANK5   0x5
#define	BANK6   0x6
#define	BANK7   0x7
#define	BANK8   0x8
#define	BANK9   0x9
#define	BANK10  0xA
#define	BANK11  0xB
#define	BANK12  0xC
#define	BANK13  0xD
#define	BANK14  0xE
#define	BANK15  0xF
#define	BANK16  0x10
#define	BANK17  0x11
#define	BANK18  0x12
#define	BANK19  0x13
#define	BANK20  0x14
#define	BANK21  0x15
#define	BANK22  0x16
#define	BANK23  0x17
#define	BANK24  0x18
#define	BANK25  0x19
#define	BANK26  0x1A
#define	BANK27  0x1B
#define	BANK28  0x1C
#define	BANK29  0x1D
#define	BANK30  0x1E
#define	BANK31  0x1F
; SFR STATUS Bits.
#define	C	0x0
#define	Z	0x2

; User Definitions.
; Emergency.
#define STOP	    0x0
; LED Debug.
#define	LED_DEBUG   0x6

; Reset Vector.
PSECT reset_vec,class=CODE,space=0,delta=2
resetVector:
    GOTO    main

; ISR Vector.
PSECT intentry,class=CODE,space=0,delta=2
interruptVector:
    GOTO    isr

; Main.
PSECT cinit,class=CODE,space=0,delta=2
main:
    ; MCU Initialization.
    ; Internal Oscillator Settings.
    MOVLB   BANK1
    MOVLW   0b00000000
    MOVWF   OSCTUNE
    MOVLW   0x70
    MOVWF   OSCCON
    BTFSS   HFIOFR
    BRA	    $-1
    ; Ports Settings.
    ; PORT Data Register.
    MOVLB   BANK0
    MOVLW   0b00000000
    MOVWF   PORTA
    MOVLW   0b00000000
    MOVWF   PORTB
    MOVLW   0b00000000
    MOVWF   PORTC
    MOVLW   0b00000000
    MOVWF   PORTE
    ; TRIS Data Direction.
    MOVLB   BANK1
    MOVLW   0b00000000
    MOVWF   TRISA
    MOVLW   0b00000001
    MOVWF   TRISB
    MOVLW   0b00000000
    MOVWF   TRISC
    MOVLW   0b00001000
    MOVWF   TRISE
    ; LATCH Outputs.
    MOVLB   BANK2
    MOVLW   0b00000000
    MOVWF   LATA
    MOVLW   0b00000001
    MOVWF   LATB
    MOVLW   0b00000000
    MOVWF   LATC
    ; ANSEL Analog.
    MOVLB   BANK3
    MOVLW   0b00000000
    MOVWF   ANSELA
    MOVLW   0b00000000
    MOVWF   ANSELB
    MOVLW   0b00000000
    MOVWF   ANSELC
    ; WPU Weak Pull-up.
    MOVLB   BANK4
    MOVLW   0b00000000
    MOVWF   WPUA
    MOVLW   0b00000000
    MOVWF   WPUB
    MOVLW   0b00000000
    MOVWF   WPUC
    MOVLW   0b00000000
    MOVWF   WPUE
    ; ODCON Open-drain.
    MOVLB   BANK5
    MOVLW   0b00000000
    MOVWF   ODCONA
    MOVLW   0b00000000
    MOVWF   ODCONB
    MOVLW   0b00000000
    MOVWF   ODCONC
    ; SRLCON Slew Rate.
    MOVLB   BANK6
    MOVLW   0b11111111
    MOVWF   SLRCONA
    MOVLW   0b11111111
    MOVWF   SLRCONB
    MOVLW   0b11111111
    MOVWF   SLRCONC
    ; INLVL Input Level.
    MOVLB   BANK7
    MOVLW   0b00000000
    MOVWF   INLVLA
    MOVLW   0b00000000
    MOVWF   INLVLB
    MOVLW   0b00000000
    MOVWF   INLVLC
    ; HIDRVB High Drive.
    MOVLB   BANK8
    MOVLW   0b00000000
    MOVWF   HIDRVB

    ; OPTION REG Settings.
    ; WPU Enabled.
    ; TIMER0 ~15Hz @8MHz.
    MOVLB   BANK1
    MOVLW   0b01010111
    MOVWF   OPTION_REG

    ; INTERRUPTS Settings.
    BSF	    INTE
    BCF	    INTF
    ; INTERRUPTS Enabled.
    BSF	    GIE

loop:
    BRA	    loop

; Interrupt Service Routine.
isr:
    ; Interrupt STOP ?
    BTFSC   INTF
    GOTO    _stop
    RETFIE

; delay = 1 ~98ms.
; delay = 255 ~25s.
_u8Delay:
    MOVWF   u8DELAY
    MOVLW   255
    DECFSZ  WREG, F
    BRA	    $-1
    DECFSZ  u8DELAY, F
    BRA	    $-3
    RETURN

_stop:
    BCF	    GIE
    MOVLB   BANK2
    BCF	    LATB, STOP
    MOVLB   BANK1
    BCF	    TRISB, STOP ; LED ON.
    MOVLW   255
    CALL    _u8Delay
    MOVLB   BANK1
    BSF	    TRISB, STOP ; LED OFF.
    MOVLW   255
    CALL    _u8Delay
    BRA	    $-8

    END resetVector
```

## MPLABX Linker Configuration.

- PIC-AS Linker > Custom linker options: `-preset_vec=0000h, -pintentry=0004h, -pcinit=0005h`

## Notes.

- TODO : Work in progress, prototype was not good, hardware, PCB and code can be rework.
- DRAFT : Prototype OK, last check schematic, PCB & code can be modify.

## DISCLAIMER.

THIS CODE IS PROVIDED WITHOUT ANY WARRANTY OR GUARANTEES.
USERS MAY USE THIS CODE FOR DEVELOPMENT AND EXAMPLE PURPOSES ONLY.
AUTHORS ARE NOT RESPONSIBLE FOR ANY ERRORS, OMISSIONS, OR DAMAGES THAT COULD
RESULT FROM USING THIS FIRMWARE IN WHOLE OR IN PART.

---

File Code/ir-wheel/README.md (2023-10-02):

# DRAFT - IR WHEEL.

## Code.

-.

```as
; Configuration Registers.
CONFIG FOSC=INTOSC
CONFIG WDTE=OFF
CONFIG PWRTE=OFF
CONFIG MCLRE=ON
CONFIG CP=OFF
CONFIG BOREN=OFF
CONFIG CLKOUTEN=OFF
CONFIG IESO=OFF
CONFIG FCMEN=OFF
CONFIG WRT=OFF
CONFIG PPS1WAY=ON
CONFIG ZCD=OFF
CONFIG PLLEN=OFF
CONFIG STVREN=ON
CONFIG BORV=LO
CONFIG LPBOR=OFF
CONFIG LVP=ON

#include <xc.inc>
; PIC16F1778 - Compile with PIC-AS(v2.36).
; PIC16F1778 - @8MHz Internal Oscillator.
; -preset_vec=0000h, -pintentry=0004h, -pcinit=0005h.
; Instruction ~500ns @8MHz.

; TBOT - v0.1.
; Sensor SHARP GP2Y0D21YK.
; PICAS-P16F1778-GP2Y0D21YKzz
; TODO: Better Delay Fonction
; TODO: Optimize Variables
; TODO: Faire le timming des boucles
; TODO: Utiliser qu un seul DAC pour les 2 comparateurs

; En focntion de la tension de la batterie
; choisir la bonne valeur pour que la vitesse
; soit constante en fonction de la tension de
; la battterie

; Pinout.
; MCU.RA6  -> LED.DEBUG / CLKOUTEN.OSCILLOSCOPE.PROBE.
; MCU.RB0 <-> INT0.EMERGENCY.LED.SWITCH.
; MCU.RB3 <-  AN9.BATTERY.SENSE.
; MCU.RB4 <-  CCP7.IR.WHEEL.LEFT.
; MCU.RB5  -> PWM11.RC.SERVO.LEFT.
; MCU.RB6  -> EUSART.TX.
; MCU.RB7 <-  EUSART.RX.
; MCU.RC0  -> GP2Y0D21YK.FRONT.ENABLE.
; MCU.RC2 <-  GP2Y0D21YK.FRONT.OUT.
; MCU.RC5  -> PWM6.RC.SERVO.RIGHT.
; MCU.RC6 <-  CCP2.IR.WHELL.RIGHT.

; GPR BANK0.
PSECT cstackBANK0,class=BANK0,space=1,delta=1
u8Delay:    DS  1
u16Delay:   DS  2
u8Filter:   DS  1
u8Speed:    DS  1
u8Rotation: DS  1

; Common RAM.
PSECT cstackCOMM,class=COMMON,space=1,delta=1
TBOT:	    DS  1

; MCU Definitions.
; BANKS.
#define	BANK0   0x0
#define	BANK1   0x1
#define	BANK2   0x2
#define	BANK3   0x3
#define	BANK4   0x4
#define	BANK5   0x5
#define	BANK6   0x6
#define	BANK7   0x7
#define	BANK8   0x8
#define	BANK9   0x9
#define	BANK10  0xA
#define	BANK11  0xB
#define	BANK12  0xC
#define	BANK13  0xD
#define	BANK14  0xE
#define	BANK15  0xF
#define	BANK16  0x10
#define	BANK17  0x11
#define	BANK18  0x12
#define	BANK19  0x13
#define	BANK20  0x14
#define	BANK21  0x15
#define	BANK22  0x16
#define	BANK23  0x17
#define	BANK24  0x18
#define	BANK25  0x19
#define	BANK26  0x1A
#define	BANK27  0x1B
#define	BANK28  0x1C
#define	BANK29  0x1D
#define	BANK30  0x1E
#define	BANK31  0x1F
; SFR STATUS Bits.
#define	C	0x0
#define	Z	0x2

; User Definitions.
; Battery.
#define BATTERY_FILTER		50
#define	BATTERY_LOW		0xB7
; Emergency.
#define EMERGENCY		0x0
; LED Debug.
#define	LED_DEBUG		0x6
; RC Servo.
#define	SERVO_SPEED		202
; Frequency 50Hz - @8MHz.
#define SERVO_PERIOD_HIGH	78
#define SERVO_PERIOD_LOW	30
; Duty Cycle.
; H6/L165 - 1.7ms - @8MHz.
; H5/L220 - 1.5ms - @8MHz.
; H5/L20  - 1.3ms - @8MHz.
#define SERVO_STOP_HIGH		5
#define SERVO_STOP_LOW		220
;
#define SERVO_MAX_LEFT_LOW	165
#define SERVO_MAX_RIGHT_LOW	26
;
#define	SERVO_LEFT_LOAD		0x4
#define	SERVO_RIGHT_LOAD	0x2
#define	SERVO_BOTH_LOAD		0x6
; Sharp GP2Y0D21YK.
#define	GP2Y0D21_60MS		160
#define GP2Y0D21_FRONT_ENABLE	0x0
#define GP2Y0D21_FRONT_OUT	0x2
; TBOT Flags.
#define TBOT_RCSERVO		0x0

; Reset Vector.
PSECT reset_vec,class=CODE,space=0,delta=2
resetVector:
    GOTO    main

; ISR Vector.
PSECT intentry,class=CODE,space=0,delta=2
interruptVector:
    GOTO    isr

; Main.
PSECT cinit,class=CODE,space=0,delta=2
main:
    ; MCU Initialization.
    ; Internal Oscillator Settings.
    MOVLB   BANK1
    MOVLW   0b00000110
    MOVWF   OSCTUNE
    MOVLW   0x70
    MOVWF   OSCCON
    BTFSS   HFIOFR
    BRA	    $-1
    ; Ports Settings.
    ; PORT Data Register.
    MOVLB   BANK0
    MOVLW   0b00000000
    MOVWF   PORTA
    MOVLW   0b00000000
    MOVWF   PORTB
    MOVLW   0b00000000
    MOVWF   PORTC
    MOVLW   0b00000000
    MOVWF   PORTE
    ; TRIS Data Direction.
    MOVLB   BANK1
    MOVLW   0b00000000
    MOVWF   TRISA
    MOVLW   0b10011001
    MOVWF   TRISB
    MOVLW   0b01000100
    MOVWF   TRISC
    MOVLW   0b00001000
    MOVWF   TRISE
    ; LATCH Outputs.
    MOVLB   BANK2
    MOVLW   0b00000000
    MOVWF   LATA
    MOVLW   0b00000001
    MOVWF   LATB
    MOVLW   0b00000000
    MOVWF   LATC
    ; ANSEL Analog.
    MOVLB   BANK3
    MOVLW   0b00000000
    MOVWF   ANSELA
    MOVLW   0b00001000
    MOVWF   ANSELB
    MOVLW   0b00000000
    MOVWF   ANSELC
    ; WPU Weak Pull-up.
    MOVLB   BANK4
    MOVLW   0b00000000
    MOVWF   WPUA
    MOVLW   0b00000000
    MOVWF   WPUB
    MOVLW   0b00000100
    MOVWF   WPUC
    MOVLW   0b00000000
    MOVWF   WPUE
    ; ODCON Open-drain.
    MOVLB   BANK5
    MOVLW   0b00000000
    MOVWF   ODCONA
    MOVLW   0b00000000
    MOVWF   ODCONB
    MOVLW   0b00000000
    MOVWF   ODCONC
    ; SRLCON Slew Rate.
    MOVLB   BANK6
    MOVLW   0b11111111
    MOVWF   SLRCONA
    MOVLW   0b11011111
    MOVWF   SLRCONB
    MOVLW   0b11011111
    MOVWF   SLRCONC
    ; INLVL Input Level.
    MOVLB   BANK7
    MOVLW   0b00000000
    MOVWF   INLVLA
    MOVLW   0b00000000
    MOVWF   INLVLB
    MOVLW   0b00000000
    MOVWF   INLVLC
    ; HIDRVB High Drive.
    MOVLB   BANK8
    MOVLW   0b00000000
    MOVWF   HIDRVB
    ; PPS Settings.
    ; PPS Write Enable.
    MOVLB   BANK28
    MOVLW   0x55
    MOVWF   PPSLOCK
    MOVLW   0xAA
    MOVWF   PPSLOCK
    BCF	    PPSLOCK, 0x0
    ; PPS Inputs.
    ; PPS Outputs.
    MOVLB   BANK29
    ; RB5 - PWM11.
    MOVLW   0x1F
    MOVWF   RB5PPS
    ; RC5 - PWM6.
    MOVLW   0x1E
    MOVWF   RC5PPS
    ; PPS Write Disable.
    MOVLB   BANK28
    MOVLW   0x55
    MOVWF   PPSLOCK
    MOVLW   0xAA
    MOVWF   PPSLOCK
    BSF	    PPSLOCK, 0x0

    ; ADC Settings.
    ; TIMER0 Overflow Trigger.
    ; Left Justified, FOSC/16.
    MOVLB   BANK9
    CLRF    ADRESL
    CLRF    ADRESH
    MOVLW   0x24
    MOVWF   ADCON0
    MOVLW   0x50
    MOVWF   ADCON1
    MOVLW   0x02
    MOVWF   ADCON2
    ; ADC Enable.
    BSF	    ADON

    ; PWM6 Settings.
    MOVLB   BANK27
    CLRF    PWM6PHL
    CLRF    PWM6PHH
    MOVLW   SERVO_STOP_LOW
    MOVWF   PWM6DCL
    MOVLW   SERVO_STOP_HIGH
    MOVWF   PWM6DCH
    MOVLW   SERVO_PERIOD_LOW
    MOVWF   PWM6PRL
    MOVLW   SERVO_PERIOD_HIGH
    MOVWF   PWM6PRH
    CLRF    PWM6OFL
    CLRF    PWM6OFH
    CLRF    PWM6TMRL
    CLRF    PWM6TMRH
    MOVLW   0x0C
    MOVWF   PWM6CON
    MOVLW   0x00
    MOVWF   PWM6INTE
    MOVLW   0x00
    MOVWF   PWM6INTF
    MOVLW   0x20
    MOVWF   PWM6CLKCON
    MOVLW   0x00
    MOVWF   PWM6LDCON
    MOVLW   0x00
    MOVWF   PWM6OFCON
    ; PWM6 Load & Enable.
    BSF	    PWM6LD
    BSF	    PWM6EN

    ; PWM11 Settings.
    MOVLB   BANK27
    CLRF    PWM11PHL
    CLRF    PWM11PHH
    MOVLW   SERVO_STOP_LOW
    MOVWF   PWM11DCL
    MOVLW   SERVO_STOP_HIGH
    MOVWF   PWM11DCH
    MOVLW   SERVO_PERIOD_LOW
    MOVWF   PWM11PRL
    MOVLW   SERVO_PERIOD_HIGH
    MOVWF   PWM11PRH
    CLRF    PWM11OFL
    CLRF    PWM11OFH
    CLRF    PWM11TMRL
    CLRF    PWM11TMRH
    MOVLW   0x0C
    MOVWF   PWM11CON
    MOVLW   0x00
    MOVWF   PWM11INTE
    MOVLW   0x00
    MOVWF   PWM11INTF
    MOVLW   0x20
    MOVWF   PWM11CLKCON
    MOVLW   0x00
    MOVWF   PWM11LDCON
    MOVLW   0x00
    MOVWF   PWM11OFCON
    ; PWM11 Load & Enable.
    BSF	    PWM11LD
    BSF	    PWM11EN

    ; OPTION REG Settings.
    ; WPU Enabled.
    ; TIMER0 ~15Hz @8MHz.
    MOVLB   BANK1
    MOVLW   0b01010111
    MOVWF   OPTION_REG

    ; BATTERY Settings.
    MOVLW   BATTERY_FILTER
    MOVWF   u8Filter

    ; GP2Y0D21 Enable.
    MOVLB   BANK2
    BSF	    LATC, GP2Y0D21_FRONT_ENABLE
    ; Wait ~60ms.
    MOVLW   GP2Y0D21_60MS
    CALL    _u8Delay
    ; GP2Y0D21 Obstacle ?
    BTFSC   PORTC, GP2Y0D21_FRONT_OUT
    BRA	    $-1

    ; INTERRUPTS Settings.
    BSF	    INTE
    BCF	    INTF
    ; INTERRUPTS Enabled.
    BSF	    GIE

    ;
    movlw   10 ; todo define
    movlb   BANK0
    movwf   u8Rotation

    ; TBOT Flags Clear.
    CLRF    TBOT

    ; Forward Right 185 5, Left 250 5.

    bra	    loop
    ; Forward 20Hz Right 160 5, Left  20 6.
    ; Forward 90Hz Right  25 5, Left 160 6.
    MOVLB   BANK27
    MOVLW   185
    MOVWF   PWM6DCL
    MOVLW   250
    MOVWF   PWM11DCL
    MOVLW   5
    MOVWF   PWM6DCH
    MOVLW   5
    MOVWF   PWM11DCH
    MOVLW   SERVO_BOTH_LOAD
    MOVWF   PWMLD
    bra $

loop:
    ; GP2Y0D21 Obstacle ?
    MOVLB   BANK0
    BTFSC   PORTC, GP2Y0D21_FRONT_OUT
    BRA	    rcServoSTOP
    ; TIMER0 For Battery Read & Filtering.
    BTFSC   TMR0IF
    BRA	    batteryRead
    ; TBOT RC Servo are Running ?
    BTFSS   TBOT, TBOT_RCSERVO
    BRA	    rcServoFWD
    BRA	    loop

; Battery Read & Filtering.
batteryRead:
    MOVLW   BATTERY_LOW
    MOVLB   BANK9
    SUBWF   ADRESH, W
    BTFSC   STATUS, C
    BRA	    $+5
    MOVLB   BANK0
    DECFSZ  u8Filter, F
    BRA	    $+5
    BRA	    _emergency
    MOVLB   BANK0
    MOVLW   BATTERY_FILTER
    MOVWF   u8Filter
    BCF     TMR0IF
    BRA     loop

; RC Servo Forward Ramp.
; TODO add Sensor Detection ?

; delay = 8 - 620ms
; delay = 6 - 466ms
; delay = 4 - 311ms
; delay = 2 - 157ms
rcServoFWD:
    movlb   0x2
    bsf	    LATA, 0x6

    MOVLB   BANK0
    MOVLW   SERVO_SPEED
    MOVWF   u8Speed
    MOVLB   BANK27
;    MOVLW   SERVO_STOP_LOW
    MOVLW   185
    MOVWF   PWM6DCL
    MOVLW   250
    MOVWF   PWM11DCL
    MOVLW   SERVO_STOP_HIGH
    MOVWF   PWM6DCH
    MOVWF   PWM11DCH
    MOVLW   SERVO_BOTH_LOAD
    MOVWF   PWMLD
    MOVLB   BANK0
    DECFSZ  u8Speed, F
    BRA	    $+2
    BRA	    $+19
    MOVLW   SERVO_MAX_RIGHT_LOW
    MOVLB   BANK27
    XORWF   PWM6DCL, W
    BTFSS   STATUS, Z
    DECF    PWM6DCL, F
    MOVLW   SERVO_MAX_LEFT_LOW
    XORWF   PWM11DCL, W
    BTFSS   STATUS, Z
    INCF    PWM11DCL, F
    MOVLW   SERVO_BOTH_LOAD
    MOVWF   PWMLD
    MOVLW   8 ; todo delay
    call    _u8Delay
    MOVLB   BANK27
    INCFSZ  PWM11DCL, W
    BRA	    $-19
    INCF    PWM11DCH, F
    BRA	    $-21
    BSF	    TBOT, TBOT_RCSERVO

    movlb   0x2
    bcf	    LATA, 0x6

    BRA	    loop

; RC Servo Stop.
rcServoSTOP:
    MOVLB   BANK0
    MOVLW   SERVO_SPEED
    MOVWF   u8Speed
    MOVLB   BANK0
    DECFSZ  u8Speed, F
    BRA	    $+2
    BRA	    $+22
    MOVLB   BANK27
    MOVLW   SERVO_STOP_LOW
    XORWF   PWM6DCL, W
    BTFSS   STATUS, Z
    INCF    PWM6DCL, F
    MOVLW   SERVO_STOP_LOW
    XORWF   PWM11DCL, W
    BTFSS   STATUS, Z
    DECF    PWM11DCL, F
    MOVLW   SERVO_BOTH_LOAD
    MOVWF   PWMLD
    MOVLW   3
    CALL    _u8Delay ; todo delay
    MOVLB   BANK27
    CLRW
    XORWF   PWM11DCL, W
    BTFSS   STATUS, Z
    BRA	    $-21
    DECF    PWM11DCL, F
    DECF    PWM11DCH, F
    BRA	    $-24
    MOVLW   255
    CALL    _u8Delay
    ; RC Servos Backward.
    MOVLB   BANK27
    MOVLW   35
    MOVWF   PWM6DCL
    MOVLW   6
    MOVWF   PWM6DCH
    MOVLW   150
    MOVWF   PWM11DCL
    MOVLW   5
    MOVWF   PWM11DCH
    MOVLW   SERVO_BOTH_LOAD
    MOVWF   PWMLD
    ; GP2Y0D21 Obstacle ?
    MOVLB   BANK0
    BTFSC   PORTC, GP2Y0D21_FRONT_OUT
    BRA	    $-1
    ; Rotation Left or Right.
    MOVLW   6 ; todo define
    MOVLB   BANK0
    SUBWF   u8Rotation, W
    BTFSC   STATUS, C
    BRA	    $+11
    ; RC Servo Stop Right, Rotation with Left RC Servo.
    MOVLB   BANK27
    MOVLW   SERVO_STOP_LOW
    MOVWF   PWM6DCL
    MOVLW   SERVO_STOP_HIGH
    MOVWF   PWM6DCH
    MOVLW   SERVO_RIGHT_LOAD
    MOVWF   PWMLD
    movlb   BANK0
    DECF    u8Rotation, F
    BRA	    $+10
    ; RC Servo Stop Left, Rotation with Right RC Servo.
    MOVLB   BANK27
    MOVLW   SERVO_STOP_LOW
    MOVWF   PWM11DCL
    MOVLW   SERVO_STOP_HIGH
    MOVWF   PWM11DCH
    MOVLW   SERVO_LEFT_LOAD
    MOVWF   PWMLD
    MOVLB   BANK0
    DECF    u8Rotation, F
    MOVLB   BANK0
    CLRW
    SUBWF   u8Rotation, W
    BTFSS   STATUS, Z
    BRA	    $+3
    MOVLW   10
    MOVWF   u8Rotation
    MOVLW   5
    CALL    _u16Delay
    ; GP2Y0D21 Obstacle ?
    MOVLB   BANK0
    BTFSC   PORTC, GP2Y0D21_FRONT_OUT
    BRA	    $-1
    ; RC Servo Stop.
    MOVLB   BANK27
    MOVLW   SERVO_STOP_LOW
    MOVWF   PWM11DCL
    MOVLW   SERVO_STOP_HIGH
    MOVWF   PWM11DCH
    MOVLW   SERVO_LEFT_LOAD
    MOVWF   PWMLD
    BCF	    TBOT, TBOT_RCSERVO

    BRA	    loop

; Interrupt Service Routine.
isr:
    ; Interrupt EMERGENCY ?
    BTFSC   INTF
    GOTO    _emergency
    RETFIE

; Functions.
; delay = 1 ~390us.
; delay = 255 ~98ms.
_u8Delay:
    MOVLB   BANK0
    MOVWF   u8Delay
    MOVLW   255
    DECFSZ  WREG, F
    BRA	    $-1
    DECFSZ  u8Delay, F
    BRA	    $-3
    RETURN

; delay = 1 ~98ms.
; delay = 255 ~25s.
_u16Delay:
    MOVLB   BANK0
    MOVWF   u16Delay
    movlw   255
    movwf   u16Delay + 1
    MOVLW   255
    DECFSZ  WREG, F
    BRA	    $-1
    DECFSZ  u16Delay + 1, F
    BRA	    $-3
    decfsz  u16Delay, F
    bra	    $-5
    RETURN

_emergency:
    BCF	    GIE
    MOVLB   BANK27
    CLRF    PWMEN
    MOVLB   BANK9
    BCF	    ADON
    MOVLB   BANK2
    BCF	    LATB, EMERGENCY
    MOVLB   BANK1
    BCF	    TRISB, EMERGENCY ; LED ON.
    MOVLW   255
    CALL    _u8Delay
    MOVLB   BANK1
    BSF	    TRISB, EMERGENCY ; LED OFF.
    MOVLW   255
    CALL    _u8Delay
    BRA	    $-8

    END	    resetVector

```

## MPLABX Linker Configuration.

- PIC-AS Linker > Custom linker options:
  - For Configuration & PWM: `-preset_vec=0000h, -pintentry=0004h, -pcinit=0005h`

<p align="center">
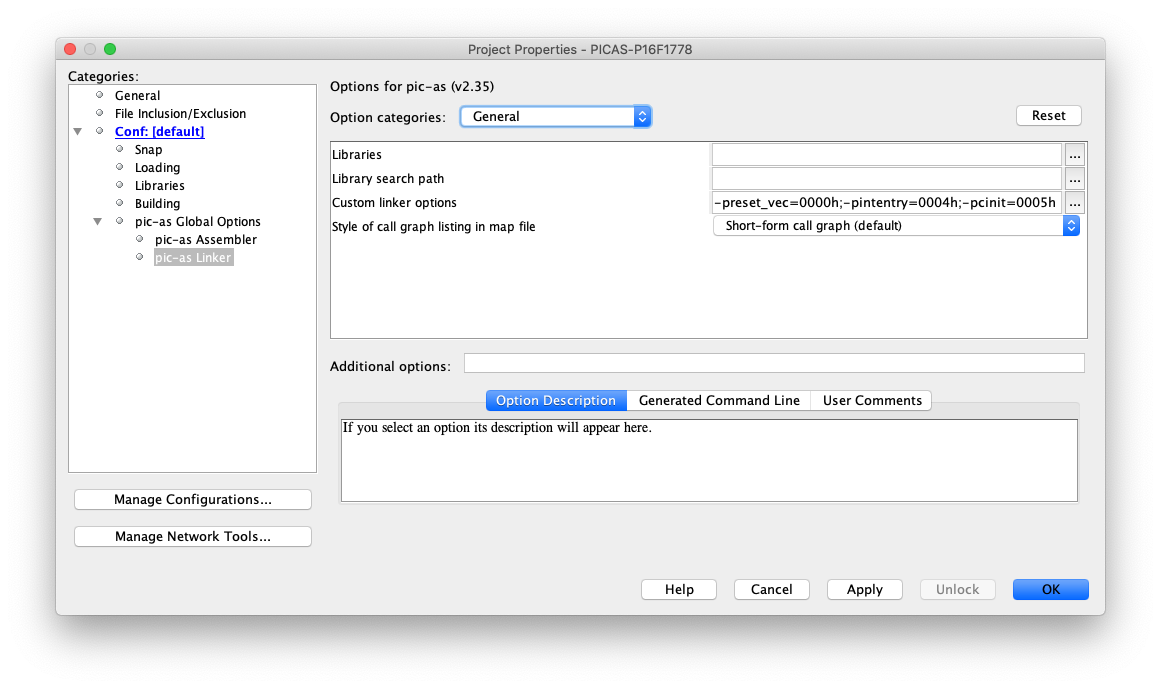
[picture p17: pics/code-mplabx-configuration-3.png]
MPLABX Linker Configuration

</p>

## Notes.

- TODO : Work in progress, prototype was not good, hardware, PCB and code can be rework.
- DRAFT : Prototype OK, last check schematic, PCB & code can be modify.

## DISCLAIMER.

THIS CODE IS PROVIDED WITHOUT ANY WARRANTY OR GUARANTEES.
USERS MAY USE THIS CODE FOR DEVELOPMENT AND EXAMPLE PURPOSES ONLY.
AUTHORS ARE NOT RESPONSIBLE FOR ANY ERRORS, OMISSIONS, OR DAMAGES THAT COULD
RESULT FROM USING THIS FIRMWARE IN WHOLE OR IN PART.

---

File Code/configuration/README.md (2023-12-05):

# MCU & GPIO Configuration.

## Code.

- MCU & GPIO Configuration.

```as
; Configuration Registers.
CONFIG FOSC=INTOSC
CONFIG WDTE=OFF
CONFIG PWRTE=OFF
CONFIG MCLRE=ON
CONFIG CP=OFF
CONFIG BOREN=OFF
CONFIG CLKOUTEN=ON
CONFIG IESO=OFF
CONFIG FCMEN=OFF
CONFIG WRT=OFF
CONFIG PPS1WAY=ON
CONFIG ZCD=OFF
CONFIG PLLEN=OFF
CONFIG STVREN=ON
CONFIG BORV=LO
CONFIG LPBOR=OFF
CONFIG LVP=ON

#include <xc.inc>
; PIC16F1778 - Compile with PIC-AS(v2.45).
; PIC16F1778 - @8MHz Internal Oscillator.
; -preset_vec=0000h.
; Instruction ~500ns @8MHz.

; TBOT - MCU & GPIO Configuration.

; Pinout.
; MCU.RA6 -> OSCILLOSCOPE.PROBE.A

; MCU Definitions.
; BANKS.
#define	BANK0   0x0
#define	BANK1   0x1
#define	BANK2   0x2
#define	BANK3   0x3
#define	BANK4   0x4
#define	BANK5   0x5
#define	BANK6   0x6
#define	BANK7   0x7
#define	BANK8   0x8
#define	BANK9   0x9
#define	BANK10  0xA
#define	BANK11  0xB
#define	BANK12  0xC
#define	BANK13  0xD
#define	BANK14  0xE
#define	BANK15  0xF
#define	BANK16  0x10
#define	BANK17  0x11
#define	BANK18  0x12
#define	BANK19  0x13
#define	BANK20  0x14
#define	BANK21  0x15
#define	BANK22  0x16
#define	BANK23  0x17
#define	BANK24  0x18
#define	BANK25  0x19
#define	BANK26  0x1A
#define	BANK27  0x1B
#define	BANK28  0x1C
#define	BANK29  0x1D
#define	BANK30  0x1E
#define	BANK31  0x1F
; SFR STATUS Bits.
#define	C	0x0
#define	Z	0x2

; Reset Vector.
PSECT reset_vec,class=CODE,space=0,delta=2
resetVector:
    GOTO    main

; Main.
PSECT cinit,class=CODE,space=0,delta=2
main:
    ; MCU Initialization.
    ; Internal Oscillator Settings.
    MOVLB   BANK1
    MOVLW   0b00000000
    MOVWF   OSCTUNE
    MOVLW   0x70
    MOVWF   OSCCON
    BTFSS   HFIOFR
    BRA	    $-1
    ; Ports Settings.
    ; PORT Data Register.
    MOVLB   BANK0
    MOVLW   0b00000000
    MOVWF   PORTA
    MOVLW   0b00000000
    MOVWF   PORTB
    MOVLW   0b00000000
    MOVWF   PORTC
    MOVLW   0b00000000
    MOVWF   PORTE
    ; TRIS Data Direction.
    MOVLB   BANK1
    MOVLW   0b00000000
    MOVWF   TRISA
    MOVLW   0b00000000
    MOVWF   TRISB
    MOVLW   0b00000000
    MOVWF   TRISC
    MOVLW   0b00000000
    MOVWF   TRISE
    ; LATCH Outputs.
    MOVLB   BANK2
    MOVLW   0b00000000
    MOVWF   LATA
    MOVLW   0b00000000
    MOVWF   LATB
    MOVLW   0b00000000
    MOVWF   LATC
    ; ANSEL Analog.
    MOVLB   BANK3
    MOVLW   0b00000000
    MOVWF   ANSELA
    MOVLW   0b00000000
    MOVWF   ANSELB
    MOVLW   0b00000000
    MOVWF   ANSELC
    ; WPU Weak Pull-up.
    MOVLB   BANK4
    MOVLW   0b00000000
    MOVWF   WPUA
    MOVLW   0b00000000
    MOVWF   WPUB
    MOVLW   0b00000000
    MOVWF   WPUC
    MOVLW   0b00000000
    MOVWF   WPUE
    ; ODCON Open-drain.
    MOVLB   BANK5
    MOVLW   0b00000000
    MOVWF   ODCONA
    MOVLW   0b00000000
    MOVWF   ODCONB
    MOVLW   0b00000000
    MOVWF   ODCONC
    ; SRLCON Slew Rate.
    MOVLB   BANK6
    MOVLW   0b11111111
    MOVWF   SLRCONA
    MOVLW   0b11111111
    MOVWF   SLRCONB
    MOVLW   0b11111111
    MOVWF   SLRCONC
    ; INLVL Input Level.
    MOVLB   BANK7
    MOVLW   0b00000000
    MOVWF   INLVLA
    MOVLW   0b00000000
    MOVWF   INLVLB
    MOVLW   0b00000000
    MOVWF   INLVLC
    ; HIDRVB High Drive.
    MOVLB   BANK8
    MOVLW   0b00000000
    MOVWF   HIDRVB

loop:
    BRA	    $

    END resetVector
```

## Oscilloscope.

- MCU.RA6 -> Oscilloscope Probe A

<p align="center">
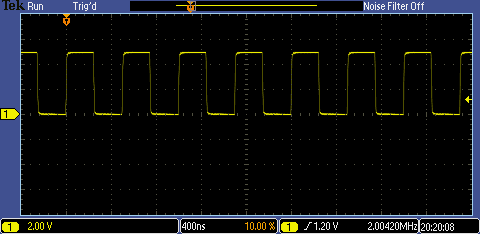
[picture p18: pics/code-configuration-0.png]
MCU.RA6

</p>

## MPLABX Linker Configuration.

- PIC-AS Linker > Custom linker options: `-preset_vec=0000h`

## Notes.

- TODO : Work in progress, prototype was not good, hardware, PCB and code can be rework.
- DRAFT : Prototype OK, last check schematic, PCB & code can be modify.

## DISCLAIMER.

THIS CODE IS PROVIDED WITHOUT ANY WARRANTY OR GUARANTEES.
USERS MAY USE THIS CODE FOR DEVELOPMENT AND EXAMPLE PURPOSES ONLY.
AUTHORS ARE NOT RESPONSIBLE FOR ANY ERRORS, OMISSIONS, OR DAMAGES THAT COULD
RESULT FROM USING THIS FIRMWARE IN WHOLE OR IN PART.

---

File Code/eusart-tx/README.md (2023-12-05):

# EUSART - Enhanced Universal Synchronous Asynchronous Receiver Transmitter.

## Code.

- EUSART TX - Display Strings.

```as
; Configuration Registers.
CONFIG FOSC=INTOSC
CONFIG WDTE=OFF
CONFIG PWRTE=OFF
CONFIG MCLRE=ON
CONFIG CP=OFF
CONFIG BOREN=OFF
CONFIG CLKOUTEN=OFF
CONFIG IESO=OFF
CONFIG FCMEN=OFF
CONFIG WRT=OFF
CONFIG PPS1WAY=ON
CONFIG ZCD=OFF
CONFIG PLLEN=OFF
CONFIG STVREN=ON
CONFIG BORV=LO
CONFIG LPBOR=OFF
CONFIG LVP=ON

#include <xc.inc>
; PIC16F1778 - Compile with PIC-AS(v2.45).
; PIC16F1778 - @8MHz Internal Oscillator.
; -preset_vec=0000h, -pstringtext=3FC0h.
; Instruction ~500ns @8MHz.

; TBOT - EUSART TX - Display Strings.

; MCU Definitions.
; BANKS.
#define	BANK0   0x0
#define	BANK1   0x1
#define	BANK2   0x2
#define	BANK3   0x3
#define	BANK4   0x4
#define	BANK5   0x5
#define	BANK6   0x6
#define	BANK7   0x7
#define	BANK8   0x8
#define	BANK9   0x9
#define	BANK10  0xA
#define	BANK11  0xB
#define	BANK12  0xC
#define	BANK13  0xD
#define	BANK14  0xE
#define	BANK15  0xF
#define	BANK16  0x10
#define	BANK17  0x11
#define	BANK18  0x12
#define	BANK19  0x13
#define	BANK20  0x14
#define	BANK21  0x15
#define	BANK22  0x16
#define	BANK23  0x17
#define	BANK24  0x18
#define	BANK25  0x19
#define	BANK26  0x1A
#define	BANK27  0x1B
#define	BANK28  0x1C
#define	BANK29  0x1D
#define	BANK30  0x1E
#define	BANK31  0x1F
; SFR STATUS Bits.
#define	C	0x0
#define	Z	0x2

; User Definition.
; LED Debug.
#define	LED_DEBUG   0x6

; Reset Vector.
PSECT reset_vec,class=CODE,space=0,delta=2
resetVector:
    GOTO    main

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

    ; EUSART Settings.
    ; 9600,8,N,1.
    MOVLB   BANK3
    CLRF    RC1REG
    CLRF    TX1REG
    MOVLW   12
    MOVWF   SP1BRGL
    MOVLW   0
    MOVWF   SP1BRGH
    MOVLW   0x10
    MOVWF   RC1STA
    MOVLW   0x20
    MOVWF   TX1STA
    MOVLW   0x00
    MOVWF   BAUD1CON
    ; EUSART Enable.
    BSF	    SPEN

    ; EUSART Display Strings.
    CALL    _writeStringTRONIX
    CALL    _writeStringURL
    CALL    _writeStringTBOT
    CALL    _writeStringREADY

loop:
    BRA	    $

; Functions.
_eusartTX:
    MOVLB   BANK3
    BTFSS   TRMT
    BRA	    $-1
    MOVWF   TX1REG
    RETURN

_eusartTXString:
    MOVIW   FSR0++
    ANDLW   0xFF
    BTFSC   STATUS, Z
    RETURN
    CALL    _eusartTX
    BRA	    $-5

_writeStringREADY:
    MOVLW   LOW stringREADY
    MOVWF   FSR0L
    MOVLW   HIGH stringREADY + 0x80
    MOVWF   FSR0H
    CALL    _eusartTXString
    RETURN

_writeStringTBOT:
    MOVLW   LOW stringTBOT
    MOVWF   FSR0L
    MOVLW   HIGH stringTBOT + 0x80
    MOVWF   FSR0H
    CALL    _eusartTXString
    RETURN

_writeStringTRONIX:
    MOVLW   LOW stringTRONIX
    MOVWF   FSR0L
    MOVLW   HIGH stringTRONIX + 0x80
    MOVWF   FSR0H
    CALL    _eusartTXString
    RETURN

_writeStringURL:
    MOVLW   LOW stringURL
    MOVWF   FSR0L
    MOVLW   HIGH stringURL + 0x80
    MOVWF   FSR0H
    CALL    _eusartTXString
    RETURN

; FPM Strings.
PSECT stringtext,class=STRCODE,space=0,delta=2

stringREADY:
    DB  0xD, 0xA, 'R','e','a','d','y','>',' ', 0x0

stringTBOT:
    DB  0xD, 0xA, 'T','B','O','T', 0xD, 0xA, 0x0

stringTRONIX:
    DB  0xD, 0xA, 0xD, 0xA, 'T','r','o','n','i','x',' ','I','/','O','.', 0x0

stringURL:
    DB  0xD, 0xA, 'w','w','w','.','t','r','o','n','i','x','.','c','o','m', 0x0

    END	resetVector
```

## Oscilloscope.

- MCU.RB6.EUSART.TX -> Oscilloscope Probe A

<p align="center">
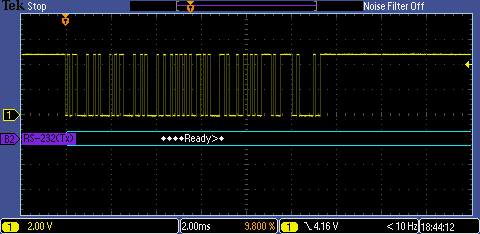
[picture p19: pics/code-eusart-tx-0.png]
MCU.RB6.EUSART.TX

</p>

## Terminal.

- EUSART TX - Display Strings.
  - Mac OS: `screen /dev/cu.usbmodemXXXXXX`

<p align="center">
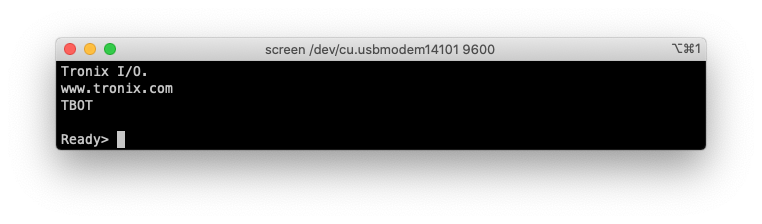
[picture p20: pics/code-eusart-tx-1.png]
EUSART TX

</p>

## MPLABX Linker Configuration.

- PIC-AS Linker > Custom linker options: `-preset_vec=0000h, -pstringtext=3FC0h`

## Notes.

- TODO : Work in progress, prototype was not good, hardware, PCB and code can be rework.
- DRAFT : Prototype OK, last check schematic, PCB & code can be modify.

## DISCLAIMER.

THIS CODE IS PROVIDED WITHOUT ANY WARRANTY OR GUARANTEES.
USERS MAY USE THIS CODE FOR DEVELOPMENT AND EXAMPLE PURPOSES ONLY.
AUTHORS ARE NOT RESPONSIBLE FOR ANY ERRORS, OMISSIONS, OR DAMAGES THAT COULD
RESULT FROM USING THIS FIRMWARE IN WHOLE OR IN PART.

---

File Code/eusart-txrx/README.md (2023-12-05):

# EUSART - Enhanced Universal Synchronous Asynchronous Receiver Transmitter.

## Code.

- EUSART TX/RX - Echo RX Character.

```as
; Configuration Registers.
CONFIG FOSC=INTOSC
CONFIG WDTE=OFF
CONFIG PWRTE=OFF
CONFIG MCLRE=ON
CONFIG CP=OFF
CONFIG BOREN=OFF
CONFIG CLKOUTEN=OFF
CONFIG IESO=OFF
CONFIG FCMEN=OFF
CONFIG WRT=OFF
CONFIG PPS1WAY=ON
CONFIG ZCD=OFF
CONFIG PLLEN=OFF
CONFIG STVREN=ON
CONFIG BORV=LO
CONFIG LPBOR=OFF
CONFIG LVP=ON

#include <xc.inc>
; PIC16F1778 - Compile with PIC-AS(v2.45).
; PIC16F1778 - @8MHz Internal Oscillator.
; -preset_vec=0000h, -pstringtext=3FC0h.
; Instruction ~500ns @8MHz.

; TBOT - EUSART TX/RX - Echo RX Character.

; GPR BANK0.
PSECT cstackBANK0,class=BANK0,space=1,delta=1
u8EusartRX:   DS  1

; MCU Definitions.
; BANKS.
#define	BANK0   0x0
#define	BANK1   0x1
#define	BANK2   0x2
#define	BANK3   0x3
#define	BANK4   0x4
#define	BANK5   0x5
#define	BANK6   0x6
#define	BANK7   0x7
#define	BANK8   0x8
#define	BANK9   0x9
#define	BANK10  0xA
#define	BANK11  0xB
#define	BANK12  0xC
#define	BANK13  0xD
#define	BANK14  0xE
#define	BANK15  0xF
#define	BANK16  0x10
#define	BANK17  0x11
#define	BANK18  0x12
#define	BANK19  0x13
#define	BANK20  0x14
#define	BANK21  0x15
#define	BANK22  0x16
#define	BANK23  0x17
#define	BANK24  0x18
#define	BANK25  0x19
#define	BANK26  0x1A
#define	BANK27  0x1B
#define	BANK28  0x1C
#define	BANK29  0x1D
#define	BANK30  0x1E
#define	BANK31  0x1F
; SFR STATUS Bits.
#define	C	0x0
#define	Z	0x2

; User Definition.
; LED Debug.
#define	LED_DEBUG   0x6
; ASCII Characters.
#define	ASCII_CR    0xD

; Reset Vector.
PSECT reset_vec,class=CODE,space=0,delta=2
resetVector:
    GOTO    main

; Main.
PSECT cinit,class=CODE,space=0,delta=2
main:
    ; MCU Initialization.
    ; Internal Oscillator Settings.
    MOVLB   BANK1
    MOVLW   0b00000000
    MOVWF   OSCTUNE
    MOVLW   0x70
    MOVWF   OSCCON
    BTFSS   HFIOFR
    BRA	    $-1
    ; Ports Settings.
    ; PORT Data Register.
    MOVLB   BANK0
    MOVLW   0b00000000
    MOVWF   PORTA
    MOVLW   0b00000000
    MOVWF   PORTB
    MOVLW   0b00000000
    MOVWF   PORTC
    MOVLW   0b00000000
    MOVWF   PORTE
    ; TRIS Data Direction.
    MOVLB   BANK1
    MOVLW   0b00000000
    MOVWF   TRISA
    MOVLW   0b10000000
    MOVWF   TRISB
    MOVLW   0b00000000
    MOVWF   TRISC
    MOVLW   0b00000000
    MOVWF   TRISE
    ; LATCH Outputs.
    MOVLB   BANK2
    MOVLW   0b00000000
    MOVWF   LATA
    MOVLW   0b00000000
    MOVWF   LATB
    MOVLW   0b00000000
    MOVWF   LATC
    ; ANSEL Analog.
    MOVLB   BANK3
    MOVLW   0b00000000
    MOVWF   ANSELA
    MOVLW   0b00000000
    MOVWF   ANSELB
    MOVLW   0b00000000
    MOVWF   ANSELC
    ; WPU Weak Pull-up.
    MOVLB   BANK4
    MOVLW   0b00000000
    MOVWF   WPUA
    MOVLW   0b00000000
    MOVWF   WPUB
    MOVLW   0b00000000
    MOVWF   WPUC
    MOVLW   0b00000000
    MOVWF   WPUE
    ; ODCON Open-drain.
    MOVLB   BANK5
    MOVLW   0b00000000
    MOVWF   ODCONA
    MOVLW   0b00000000
    MOVWF   ODCONB
    MOVLW   0b00000000
    MOVWF   ODCONC
    ; SRLCON Slew Rate.
    MOVLB   BANK6
    MOVLW   0b11111111
    MOVWF   SLRCONA
    MOVLW   0b11111111
    MOVWF   SLRCONB
    MOVLW   0b11111111
    MOVWF   SLRCONC
    ; INLVL Input Level.
    MOVLB   BANK7
    MOVLW   0b00000000
    MOVWF   INLVLA
    MOVLW   0b00000000
    MOVWF   INLVLB
    MOVLW   0b00000000
    MOVWF   INLVLC
    ; HIDRVB High Drive.
    MOVLB   BANK8
    MOVLW   0b00000000
    MOVWF   HIDRVB
    ; PPS Settings.
    ; PPS Write Enable.
    MOVLB   BANK28
    MOVLW   0x55
    MOVWF   PPSLOCK
    MOVLW   0xAA
    MOVWF   PPSLOCK
    BCF	    PPSLOCK, 0x0
    ; PPS Inputs.
    ; RB7 - EUSART.URX.
    MOVLW   0x0F
    MOVWF   RXPPS
    ; PPS Outputs.
    MOVLB   BANK29
    ; RB6 - EUSART.UTX.
    MOVLW   0x24
    MOVWF   RB6PPS
    ; PPS Write Disable.
    MOVLB   BANK28
    MOVLW   0x55
    MOVWF   PPSLOCK
    MOVLW   0xAA
    MOVWF   PPSLOCK
    BSF	    PPSLOCK, 0x0

    ; EUSART Settings.
    ; 9600,8,N,1.
    MOVLB   BANK3
    CLRF    RC1REG
    CLRF    TX1REG
    MOVLW   12
    MOVWF   SP1BRGL
    CLRF    SP1BRGH
    MOVLW   0x10
    MOVWF   RC1STA
    MOVLW   0x20
    MOVWF   TX1STA
    MOVLW   0x00
    MOVWF   BAUD1CON
    ; EUSART Enable.
    BSF	    SPEN

    ; EUSART Display Strings.
    CALL    _writeStringTRONIX
    CALL    _writeStringURL
    CALL    _writeStringTBOT
    CALL    _writeStringREADY

loop:
    ; EUSART Echo Character.
    CALL    _eusartRX
    CALL    _eusartTX

    ; Carriage Return ?
    MOVLB   BANK0
    MOVLW   ASCII_CR
    XORWF   u8EusartRX, W
    BTFSS   STATUS, Z
    BRA	    loop

    ; EUSART String READY.
    CALL    _writeStringREADY

    BRA	    loop

; Functions.
_eusartRX:
    MOVLB   BANK0
    BTFSS   RCIF
    BRA	    $-1
    MOVLB   BANK3
    BTFSS   OERR
    BRA	    $+3
    BCF	    CREN
    BSF	    CREN
    MOVF    RC1REG, W
    MOVLB   BANK0
    MOVWF   u8EusartRX
    RETURN

_eusartTX:
    MOVLB   BANK3
    BTFSS   TRMT
    BRA	    $-1
    MOVWF   TX1REG
    RETURN

_eusartTXString:
    MOVIW   FSR0++
    ANDLW   0xFF
    BTFSC   STATUS, Z
    RETURN
    CALL    _eusartTX
    BRA	    $-5

_writeStringREADY:
    MOVLW   LOW stringREADY
    MOVWF   FSR0L
    MOVLW   HIGH stringREADY + 0x80
    MOVWF   FSR0H
    CALL    _eusartTXString
    RETURN

_writeStringTBOT:
    MOVLW   LOW stringTBOT
    MOVWF   FSR0L
    MOVLW   HIGH stringTBOT + 0x80
    MOVWF   FSR0H
    CALL    _eusartTXString
    RETURN

_writeStringTRONIX:
    MOVLW   LOW stringTRONIX
    MOVWF   FSR0L
    MOVLW   HIGH stringTRONIX + 0x80
    MOVWF   FSR0H
    CALL    _eusartTXString
    RETURN

_writeStringURL:
    MOVLW   LOW stringURL
    MOVWF   FSR0L
    MOVLW   HIGH stringURL + 0x80
    MOVWF   FSR0H
    CALL    _eusartTXString
    RETURN

; FPM Strings.
PSECT stringtext,class=STRCODE,space=0,delta=2

stringREADY:
    DB  0xD, 0xA, 'R','e','a','d','y','>',' ', 0x0

stringTBOT:
    DB  0xD, 0xA, 'T','B','O','T', 0xD, 0xA, 0x0

stringTRONIX:
    DB  0xD, 0xA, 0xD, 0xA, 'T','r','o','n','i','x',' ','I','/','O','.', 0x0

stringURL:
    DB  0xD, 0xA, 'w','w','w','.','t','r','o','n','i','x','.','c','o','m', 0x0

    END resetVector
```

## Oscilloscope.

- MCU.RB7.EUSART.RX -> Oscilloscope Probe A
- MCU.RB6.EUSART.TX -> Oscilloscope Probe B

<p align="center">
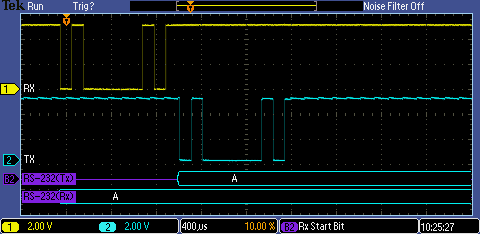
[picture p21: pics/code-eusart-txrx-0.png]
MCU.RB6.EUSART.TX

</p>

## Terminal.

- EUSART TX/RX - Echo RX Character.
  - Mac OS: `screen /dev/cu.usbmodemXXXXXX`

<p align="center">
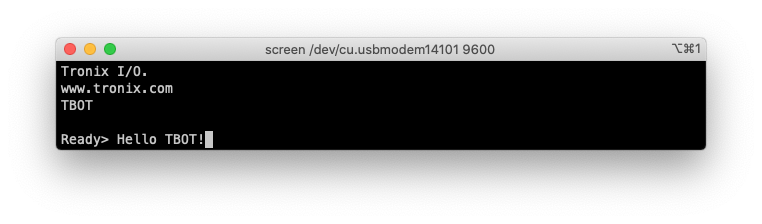
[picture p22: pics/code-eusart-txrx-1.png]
EUSART TX/RX

</p>

## MPLABX Linker Configuration.

- PIC-AS Linker > Custom linker options: `-preset_vec=0000h, -pstringtext=3FC0h`

## Notes.

- TODO : Work in progress, prototype was not good, hardware, PCB and code can be rework.
- DRAFT : Prototype OK, last check schematic, PCB & code can be modify.

## DISCLAIMER.

THIS CODE IS PROVIDED WITHOUT ANY WARRANTY OR GUARANTEES.
USERS MAY USE THIS CODE FOR DEVELOPMENT AND EXAMPLE PURPOSES ONLY.
AUTHORS ARE NOT RESPONSIBLE FOR ANY ERRORS, OMISSIONS, OR DAMAGES THAT COULD
RESULT FROM USING THIS FIRMWARE IN WHOLE OR IN PART.

---

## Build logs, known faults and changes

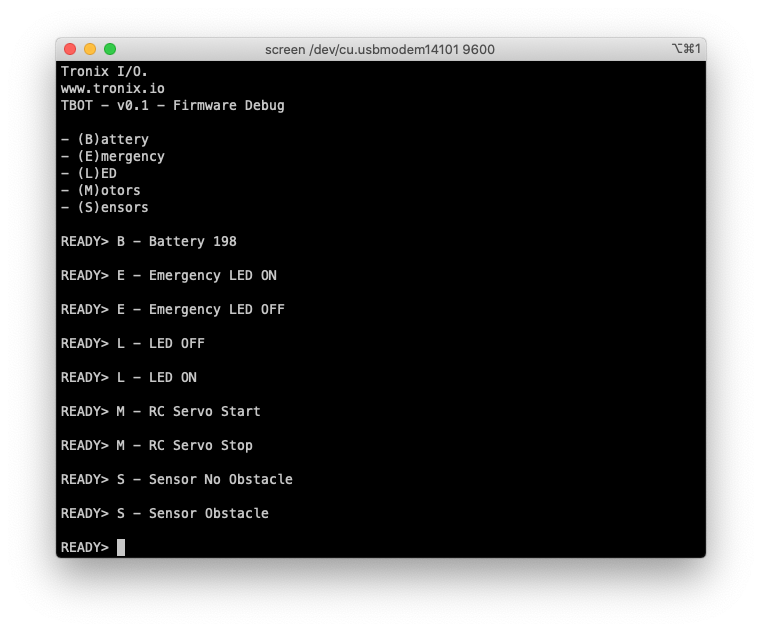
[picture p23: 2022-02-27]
pics/mplabx-debug-eusart.png

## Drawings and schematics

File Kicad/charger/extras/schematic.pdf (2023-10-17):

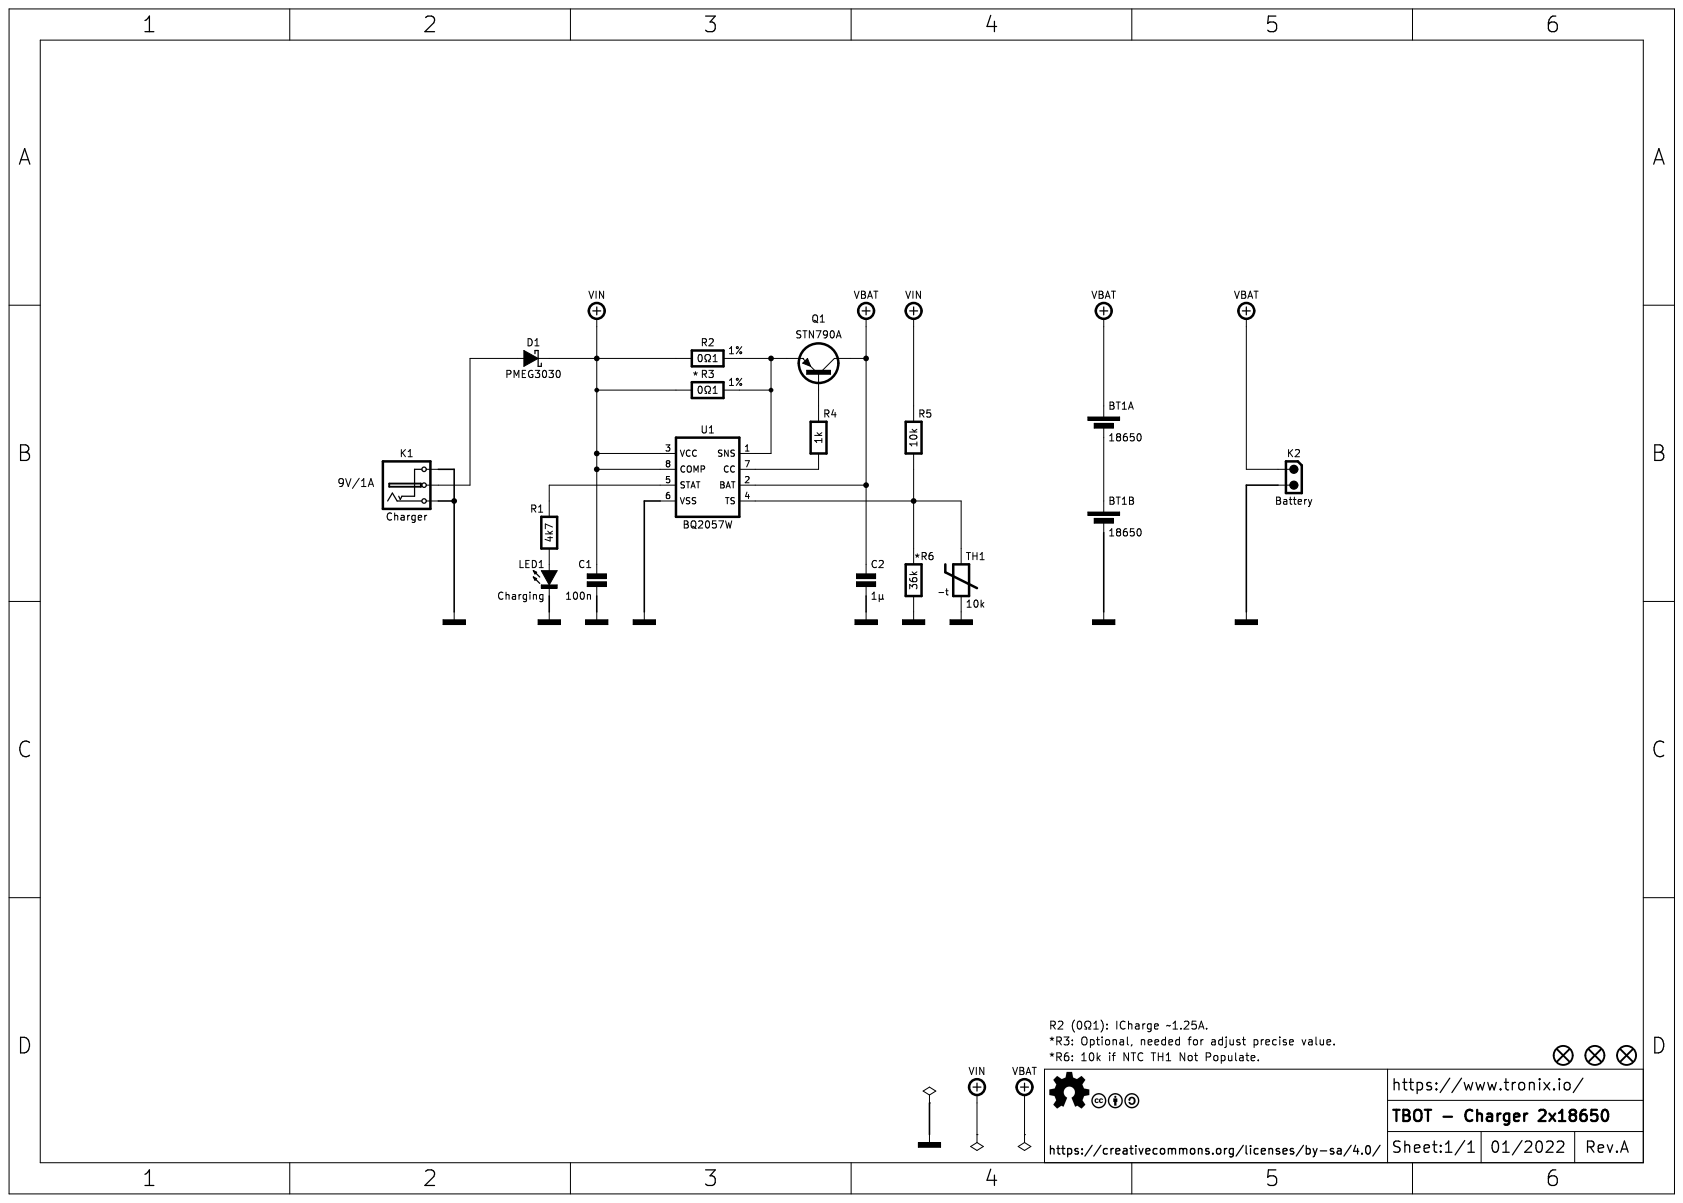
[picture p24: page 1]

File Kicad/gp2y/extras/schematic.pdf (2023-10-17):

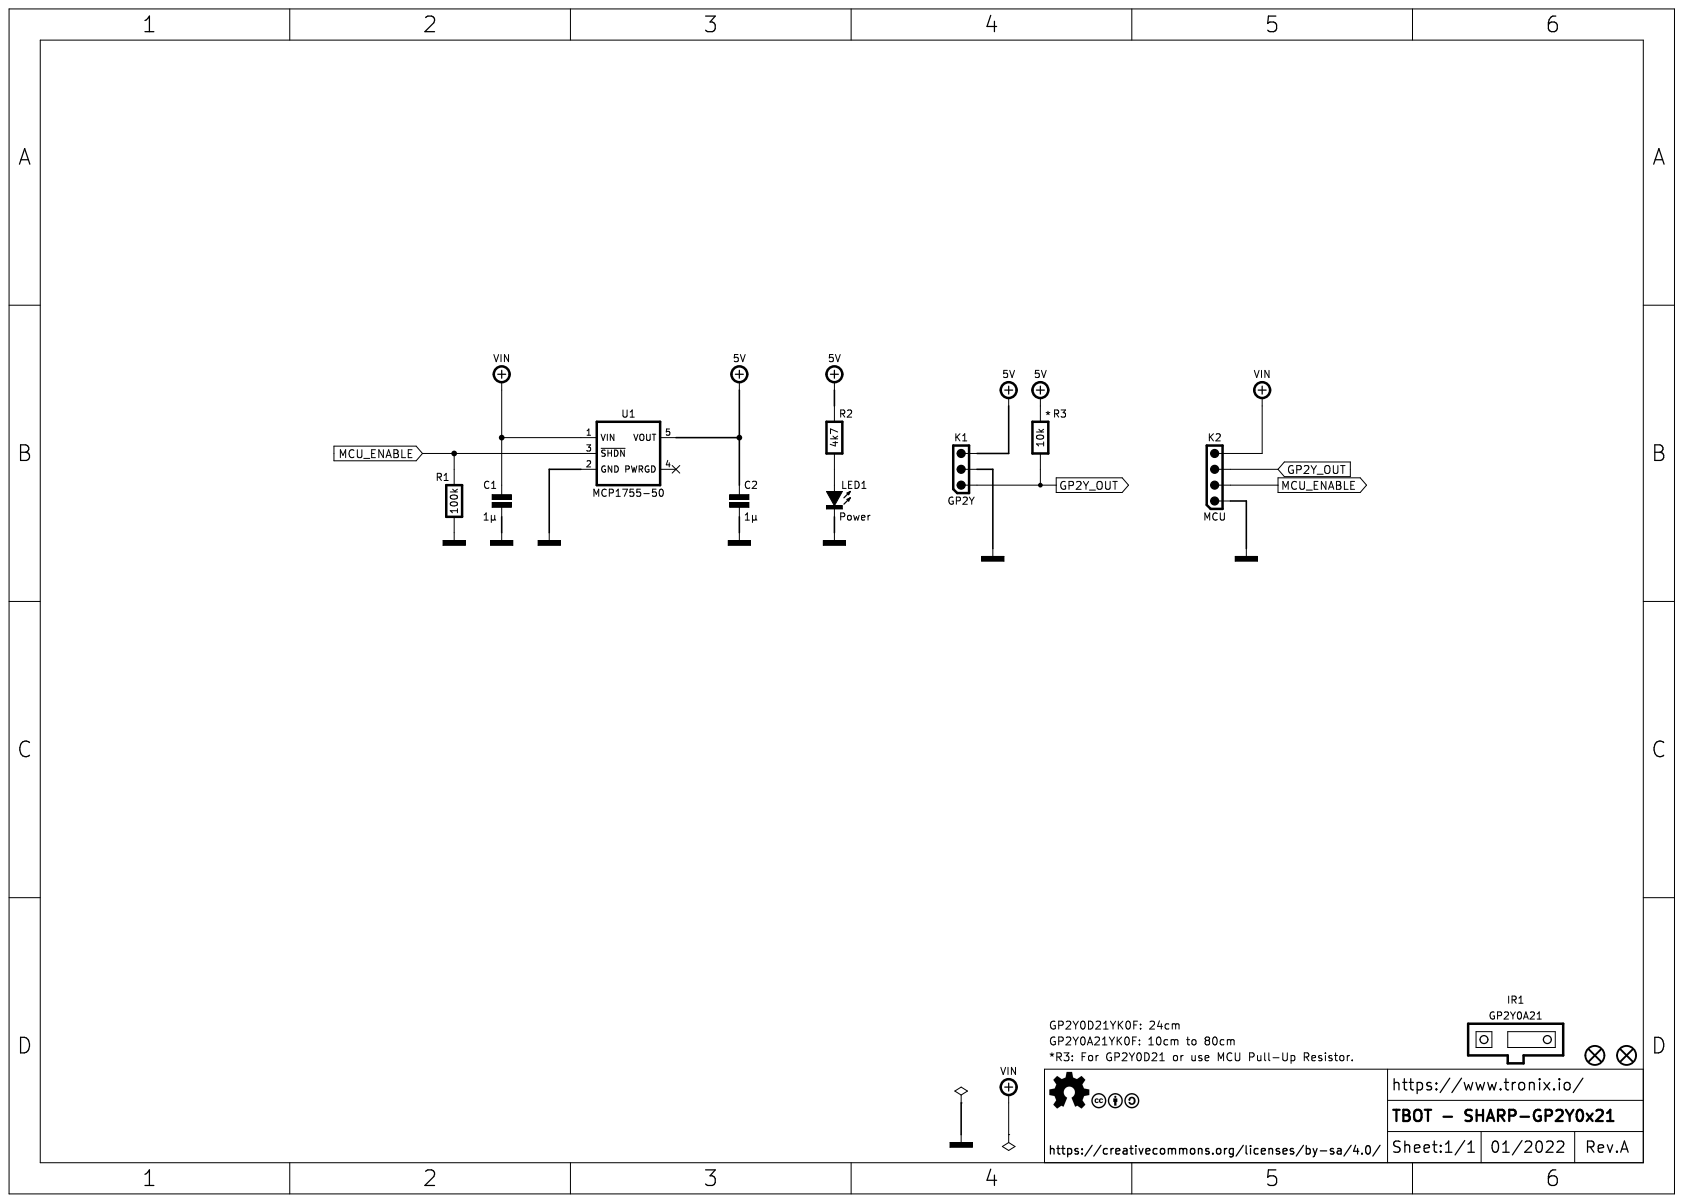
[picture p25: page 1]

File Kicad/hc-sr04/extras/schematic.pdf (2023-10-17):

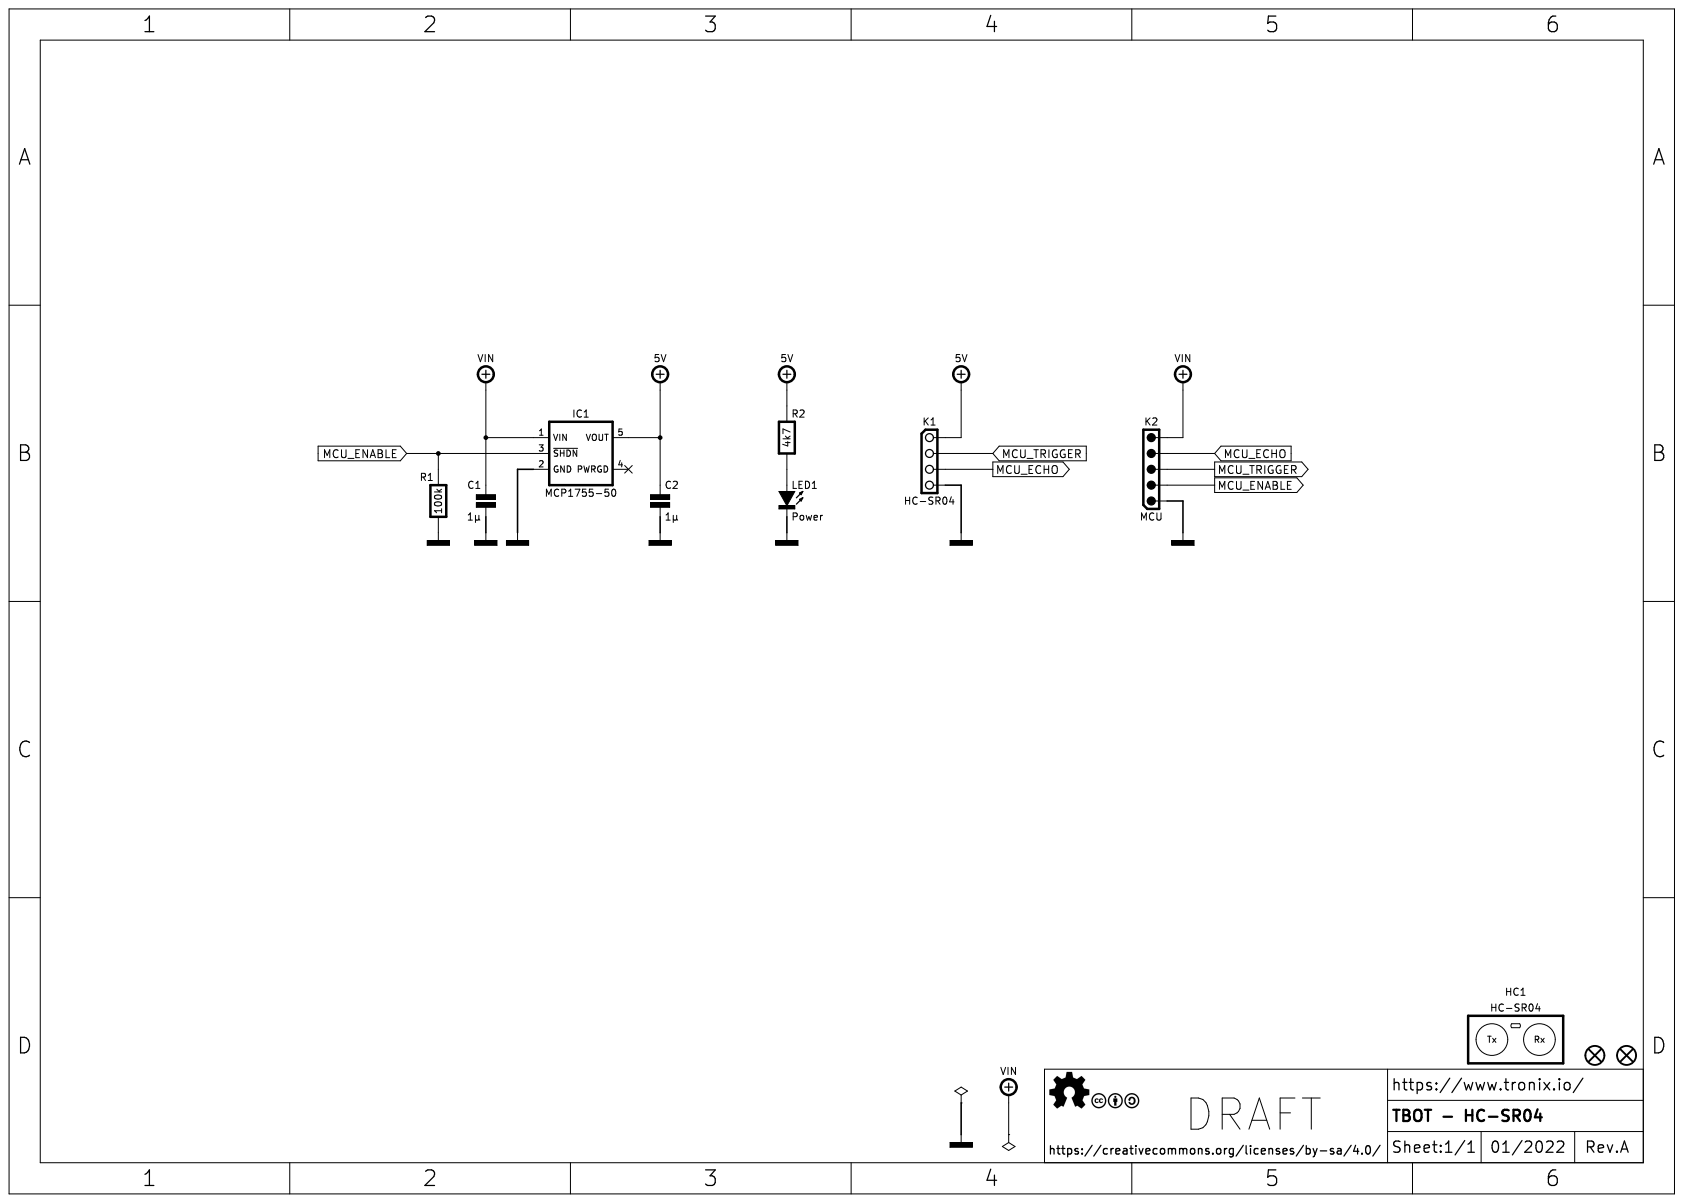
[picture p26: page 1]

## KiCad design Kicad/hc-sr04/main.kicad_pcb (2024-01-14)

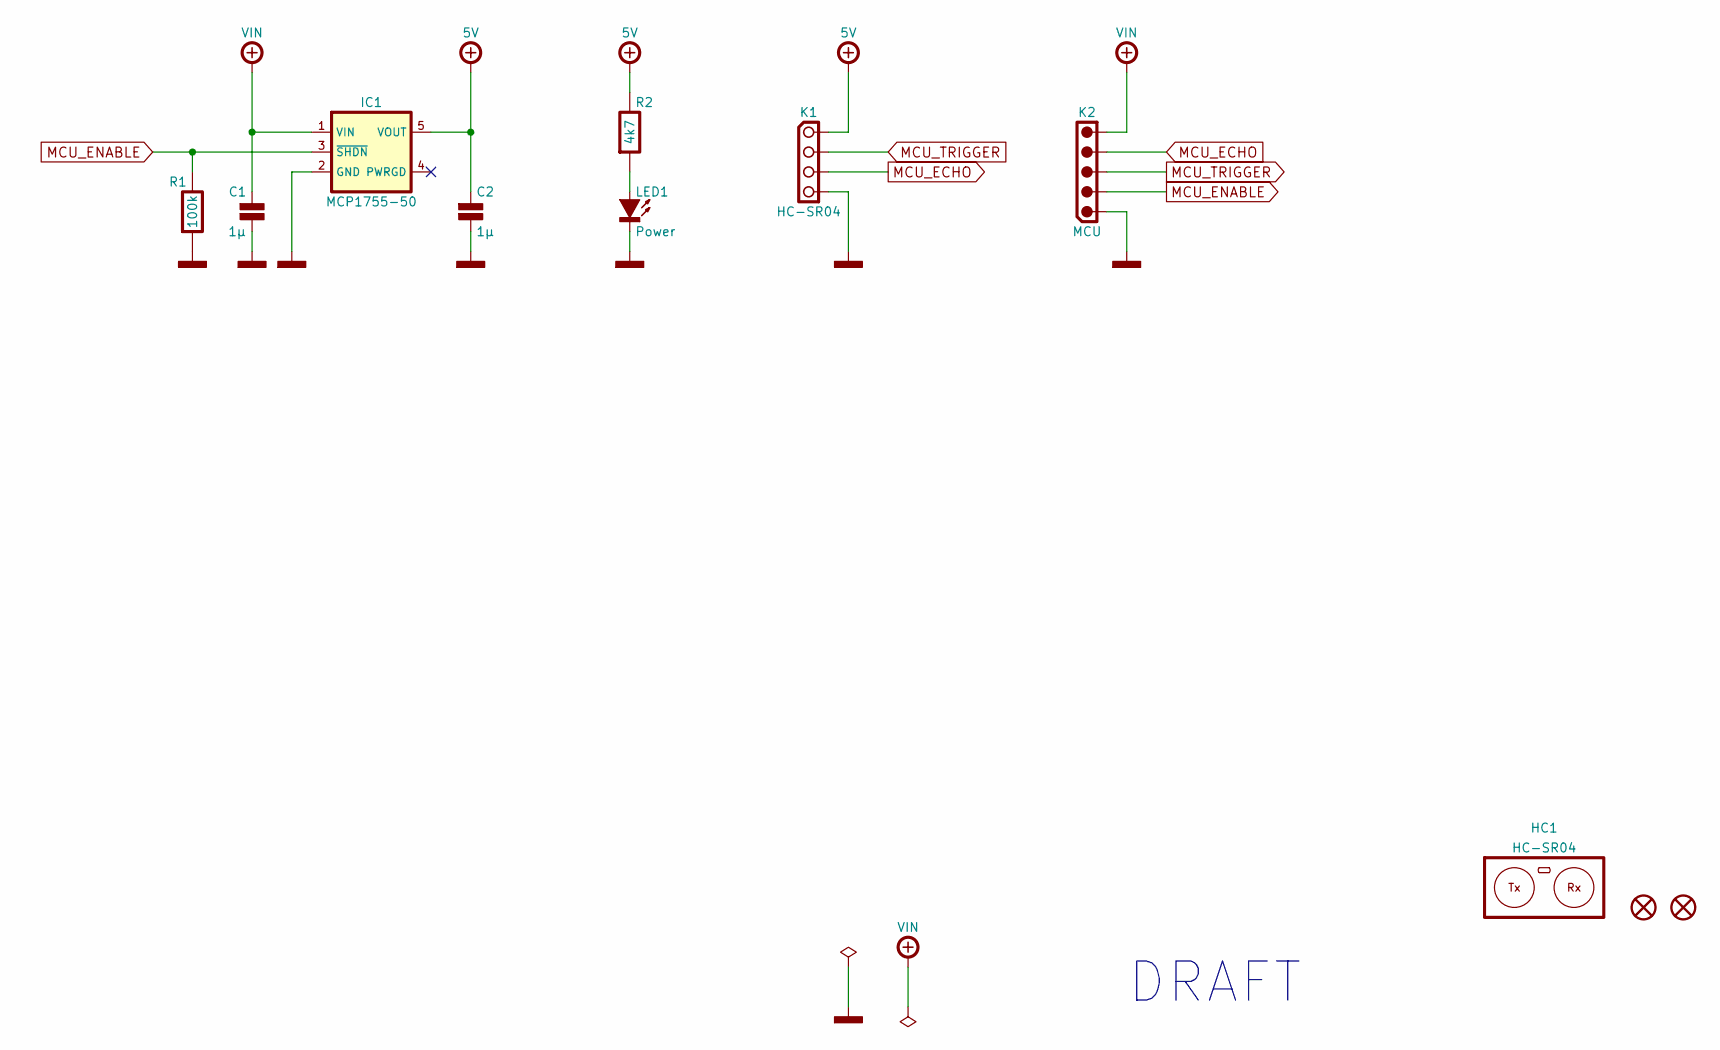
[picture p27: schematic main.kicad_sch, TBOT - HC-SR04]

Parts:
C1, C2: 1µ; CAPACITOR-SMD-1206; Voltage 16V; Tolerance 10%; Mouser 80-C1206C105K4R
H1, H2: MOUNTING-HOLE-3MM-MASK
HC1: HC-SR04
IC1: MCP1755-50; SOT-23-5; Mouser 579-MCP1755T-5002EOT
K1: HC-SR04; SAMTEC-SSW-104-02-T-S-RA; Mouser 200-SSW10402TSRA
K2: MCU; MOLEX-532540570; Mouser 538-53254-0570
LED1: Power; LED-SMD-1206; Mouser 604-APTR3216-VFX
R1: 100k; RESISTOR-SMD-1206; Tolerance 5%; Mouser 660-RK73B2BTTDD104J
R2: 4k7; RESISTOR-SMD-1206; Tolerance 5%; Mouser 660-RK73B2BTTDD472J

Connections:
+5V: C2.1, IC1.5 (VOUT), K1.1, R2.1
+VIN: C1.1, IC1.1 (VIN), K2.5
GND: C1.2, C2.2, IC1.2 (GND), K1.4, K2.1, LED1.1 (C), R1.2
MCU_ECHO: K1.3, K2.4
MCU_ENABLE: IC1.3 (~SHDN), K2.2, R1.1
MCU_TRIGGER: K1.2, K2.3
unnamed: LED1.2 (A), R2.2

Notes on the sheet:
DRAFT

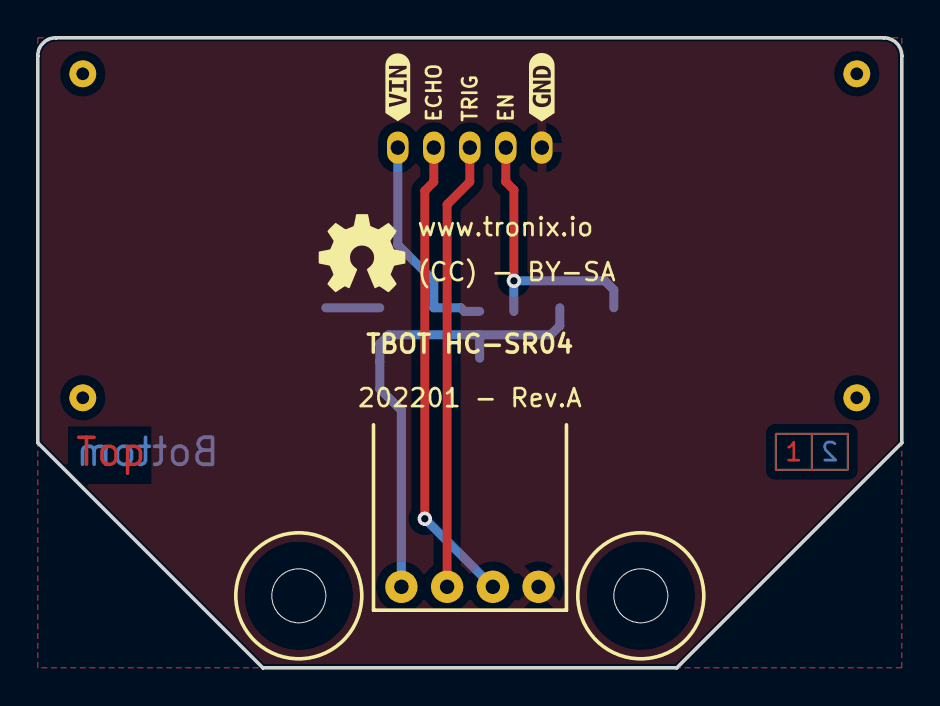
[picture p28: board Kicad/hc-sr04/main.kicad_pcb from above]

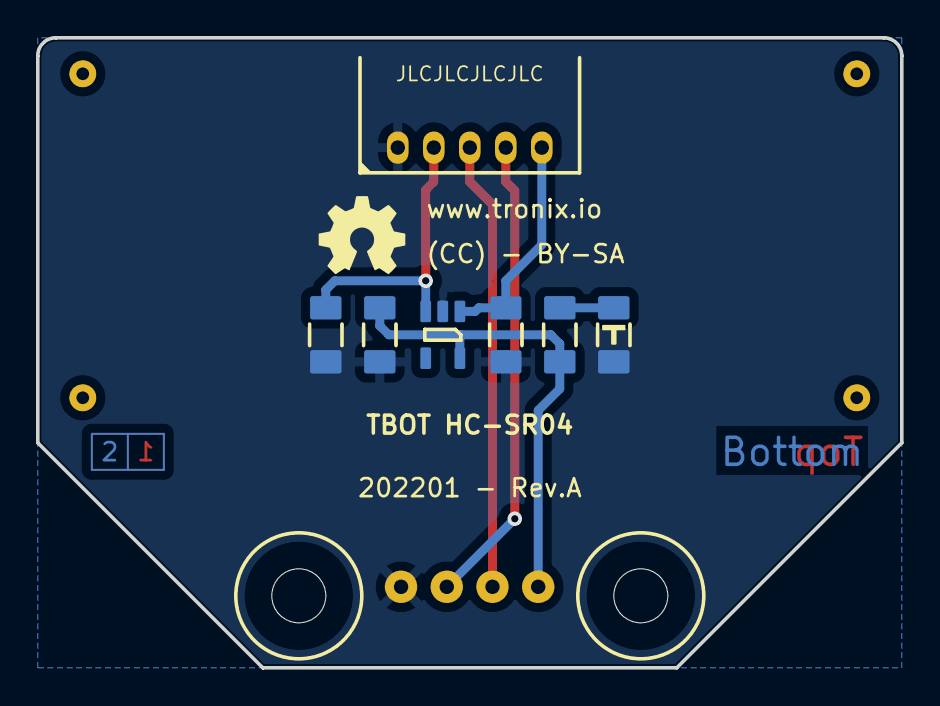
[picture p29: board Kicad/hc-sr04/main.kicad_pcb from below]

Board: 2 copper layers, 48.0 x 35.0 mm, 15 parts (10 on the bottom side), 7 nets.

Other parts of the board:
GB: LOGO; OSHW-5MM
GT: LOGO; OSHW-5MM
kibuzzard-6288C61E: G***; kibuzzard-6288C61E
kibuzzard-6288C626: G***; kibuzzard-6288C626

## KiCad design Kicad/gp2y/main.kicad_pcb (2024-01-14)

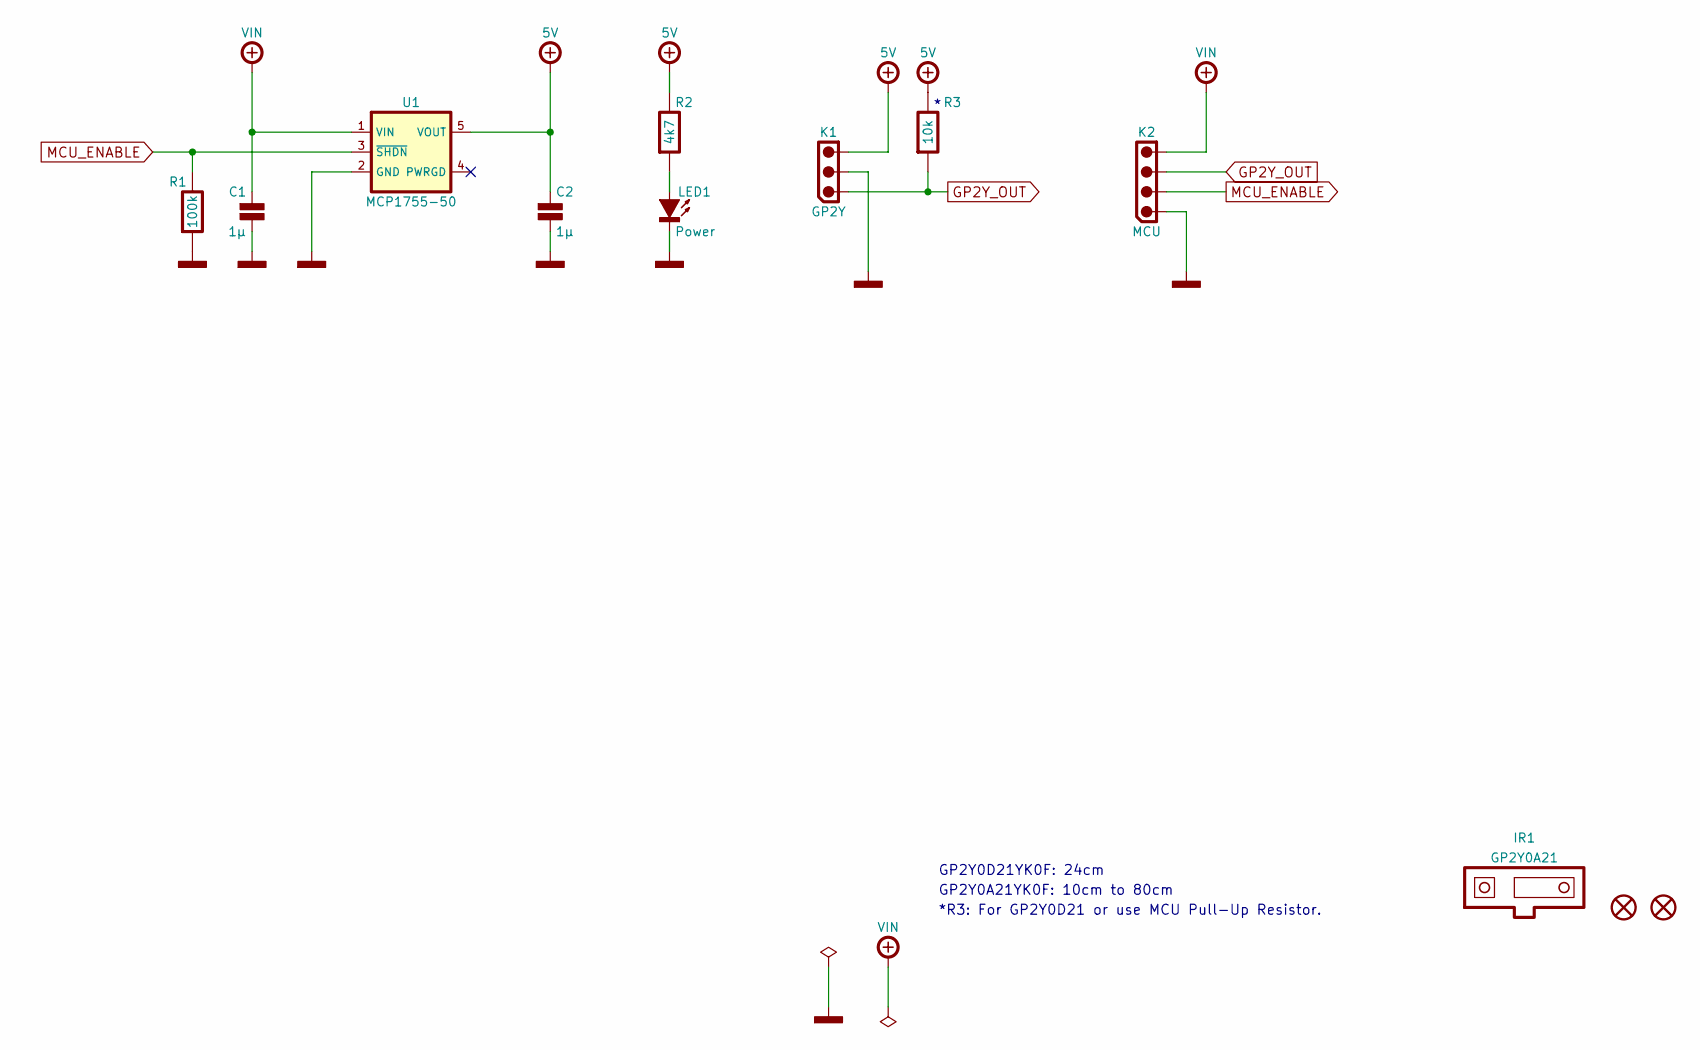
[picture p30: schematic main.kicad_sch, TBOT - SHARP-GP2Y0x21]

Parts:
C1, C2: 1µ; CAPACITOR-SMD-1206; Voltage 16V; Tolerance 10%; Mouser 80-C1206C105K4R
H1, H2: MOUNTING-HOLE-3MM-MASK
IR1: GP2Y0A21; SHARP-GP2Y0A; Mouser 852-GP2Y0A21YK0F
K1: GP2Y; MOLEX-532540370; Mouser 538-53254-0370
K2: MCU; MOLEX-532540470; Mouser 538-53254-0470
LED1: Power; LED-SMD-1206; Mouser 604-APTR3216-VFX
R1: 100k; RESISTOR-SMD-1206; Tolerance 5%; Mouser 660-RK73B2BTTDD104J
R2: 4k7; RESISTOR-SMD-1206; Tolerance 5%; Mouser 660-RK73B2BTTDD472J
R3: 10k; RESISTOR-SMD-1206; Tolerance 5%; Mouser 660-RK73B2BTTDD103J
U1: MCP1755-50; SOT-23-5; Mouser 579-MCP1755T-5002EOT

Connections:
+5V: C2.1, K1.3, R2.1, R3.1, U1.5 (VOUT)
+VIN: C1.1, K2.4, U1.1 (VIN)
GND: C1.2, C2.2, K1.2, K2.1, LED1.1 (C), R1.2, U1.2 (GND)
GP2Y_OUT: K1.1, K2.3, R3.2
MCU_ENABLE: K2.2, R1.1, U1.3 (~SHDN)
unnamed: LED1.2 (A), R2.2

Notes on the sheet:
GP2Y0D21YK0F: 24cm
GP2Y0A21YK0F: 10cm to 80cm
*R3: For GP2Y0D21 or use MCU Pull-Up Resistor.

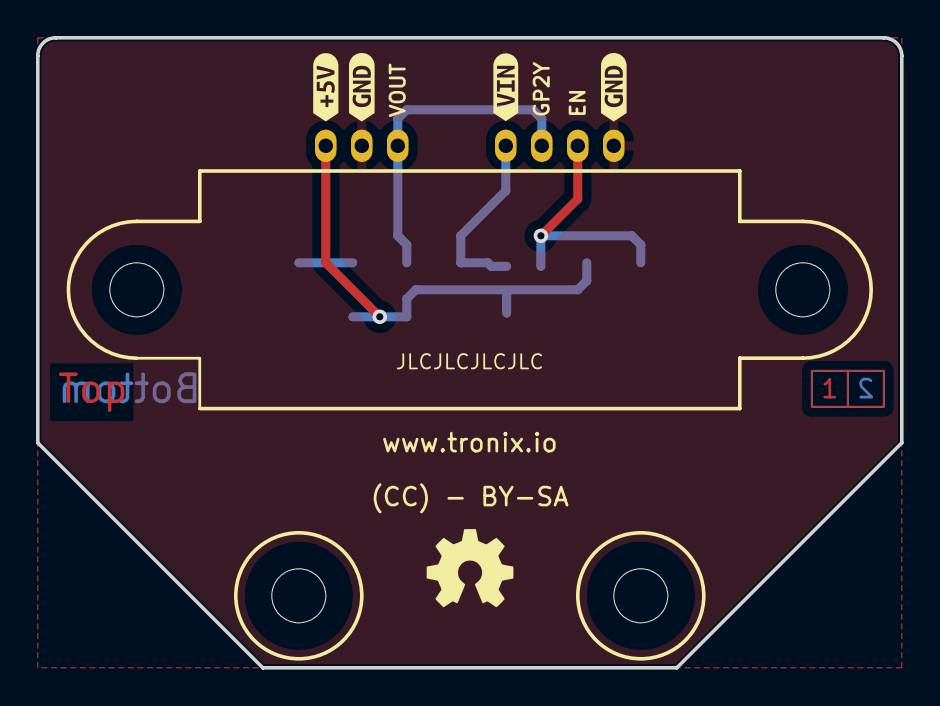
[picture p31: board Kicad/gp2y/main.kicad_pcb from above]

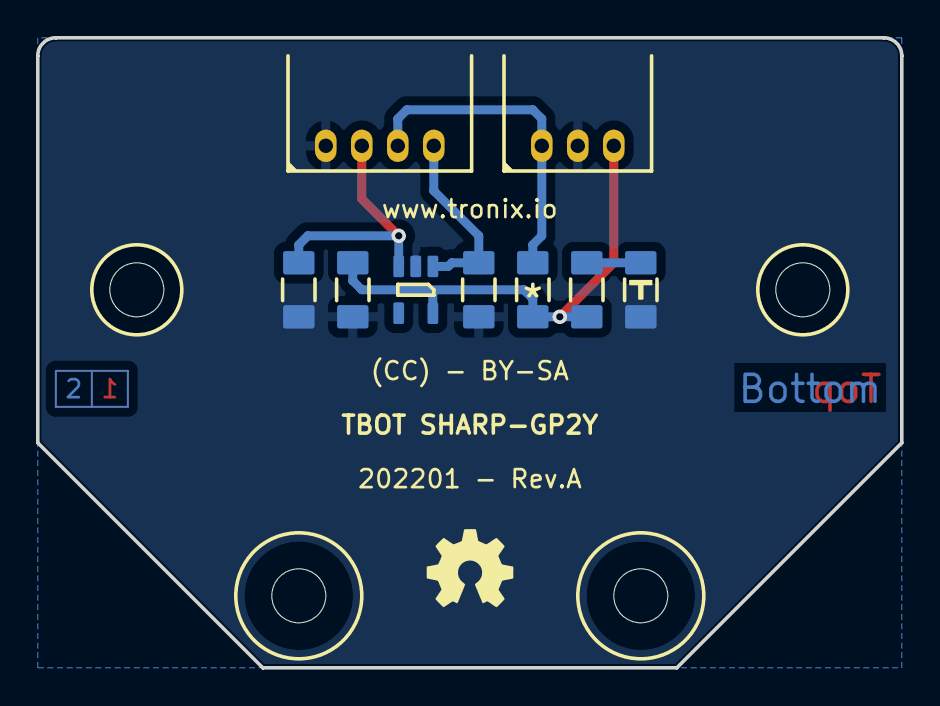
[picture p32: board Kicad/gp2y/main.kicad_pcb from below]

Board: 2 copper layers, 48.0 x 35.0 mm, 18 parts (12 on the bottom side), 6 nets.

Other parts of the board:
GB: LOGO; OSHW-5MM
GT: LOGO; OSHW-5MM
kibuzzard-6288C56E: G***; kibuzzard-6288C56E
kibuzzard-6288C554: G***; kibuzzard-6288C554
kibuzzard-6288C562: G***; kibuzzard-6288C562
kibuzzard-6288C567: G***; kibuzzard-6288C567

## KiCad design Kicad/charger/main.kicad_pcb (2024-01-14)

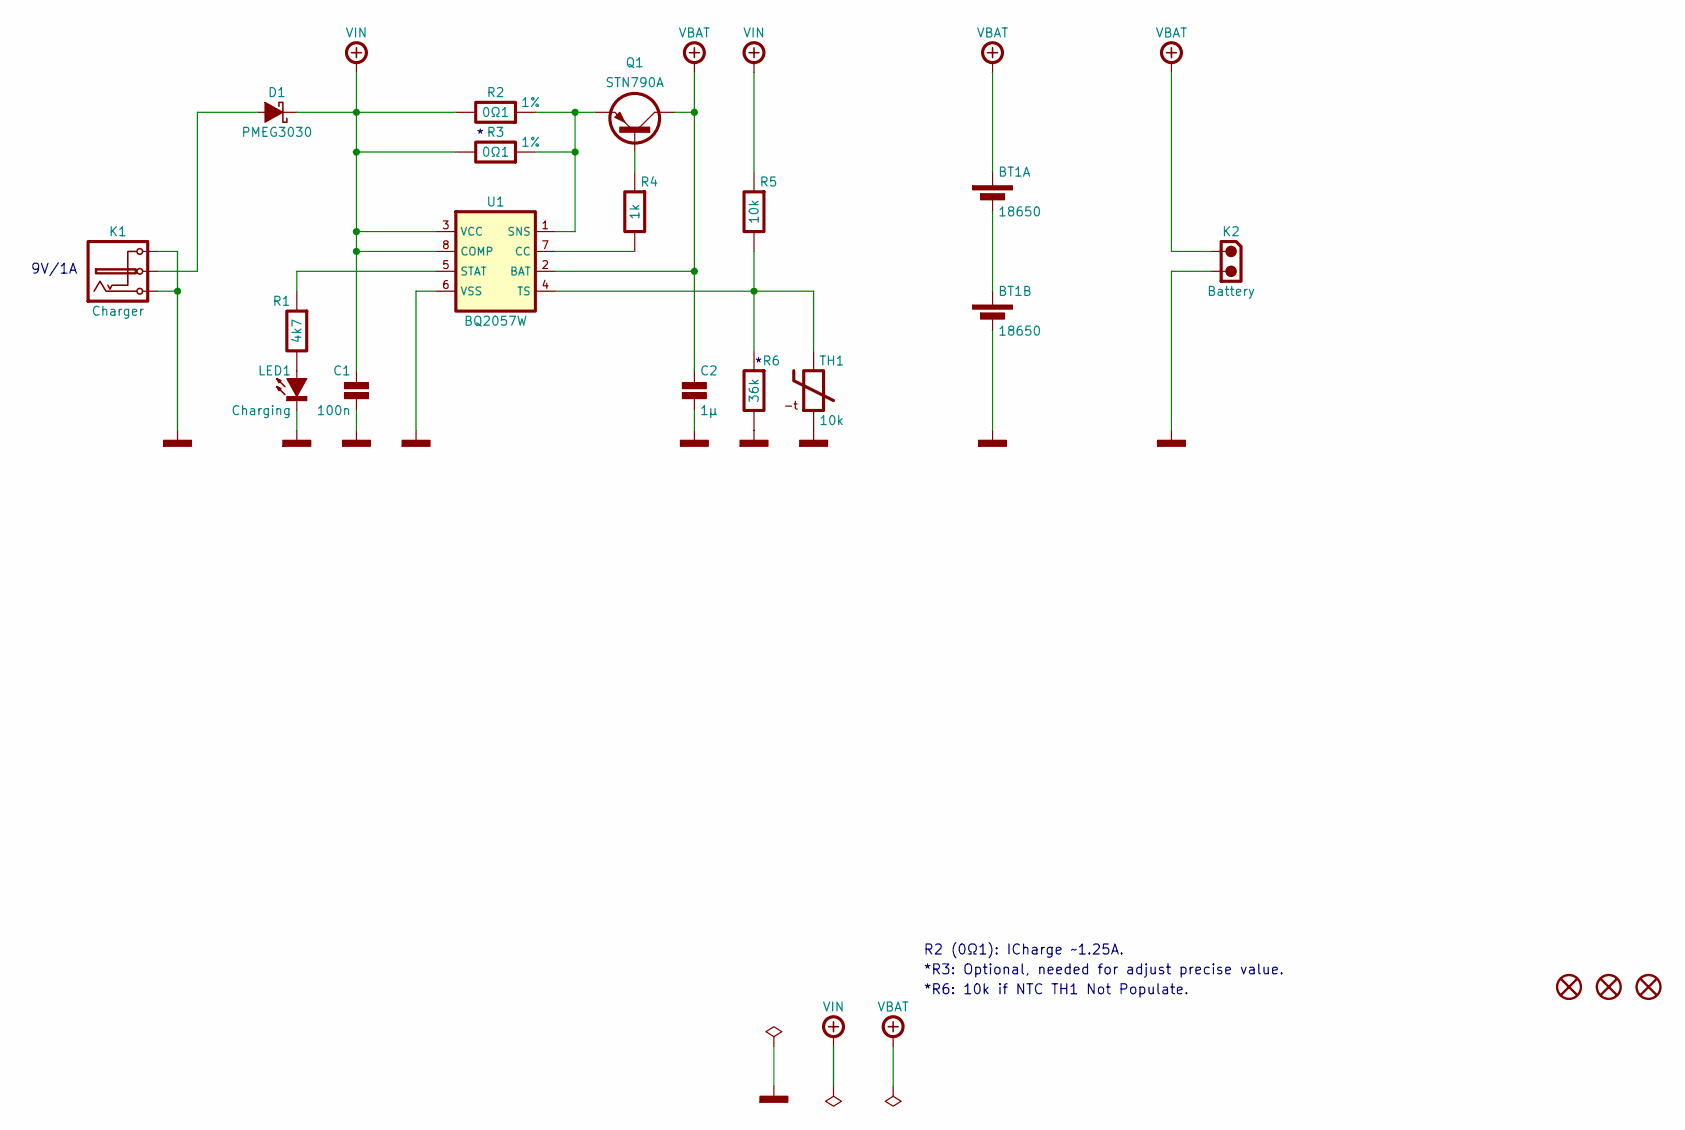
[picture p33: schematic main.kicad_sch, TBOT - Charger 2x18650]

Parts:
BT1: 18650; KEYSTONE-1049; Mouser 534-1049
C1: 100n; CAPACITOR-SMD-1206; Voltage 50V; Tolerance 5%; Mouser 80-C1206C104J5R
C2: 1µ; CAPACITOR-SMD-1206; Voltage 16V; Tolerance 10%; Mouser 80-C1206C105K4R
D1: PMEG3030; SOD-128; Mouser 771-PMEG3030EP115
H1, H2, H3: MOUNTING-HOLE-3MM-MASK
K1: Charger; CUI-PJ-102AH; Mouser 490-PJ-102AH
K2: Battery; MOLEX-22057025; Mouser 538-22-05-7025
LED1: Charging; LED-SMD-1206; Mouser 604-APTR3216-VFX
Q1: STN790A; SOT-223-3; Mouser 511-STN790A
R1: 4k7; RESISTOR-SMD-1206; Tolerance 5%; Mouser 660-RK73B2BTTDD472J
R2, R3: 0Ω1; RESISTOR-SMD-1210; Tolerance 1%; Mouser 660-SR732ETTER100F
R4: 1k; RESISTOR-SMD-1206; Tolerance 5%; Mouser 660-RK73B2BTTDD102J
R5: 10k; RESISTOR-SMD-1206; Tolerance 5%; Mouser 660-RK73B2BTTDD103J
R6: 36k; RESISTOR-SMD-1206; Tolerance 5%; Mouser 660-RK73B2BTTDD363J
TH1: 10k; THERMISTOR-SMD; Mouser 594-NTCLE213E3103FL
U1: BQ2057W; SOIC-08; Mouser 595-BQ2057WSN

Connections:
+VBAT: BT1.2 (+), C2.1, K2.1, Q1.2 (C), U1.2 (BAT)
+VIN: C1.1, D1.1 (C), R2.1, R3.1, R5.2, U1.3 (VCC), U1.8 (COMP)
GND: BT1.3 (-), C1.2, C2.2, K1.2, K1.3, K2.2, LED1.1 (C), R6.1, TH1.2, U1.6 (VSS)
unnamed: BT1.1 (-), BT1.4 (+)
unnamed: D1.2 (A), K1.1
unnamed: LED1.2 (A), R1.1
unnamed: Q1.1 (B), R4.2
unnamed: Q1.3 (E), R2.2, R3.2, U1.1 (SNS)
unnamed: R4.1, U1.7 (CC)
unnamed: R1.2, U1.5 (STAT)
unnamed: R5.1, R6.2, TH1.1, U1.4 (TS)

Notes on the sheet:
R2 (0Ω1): ICharge ~1.25A.
*R3: Optional, needed for adjust precise value.
*R6: 10k if NTC TH1 Not Populate.
9V/1A

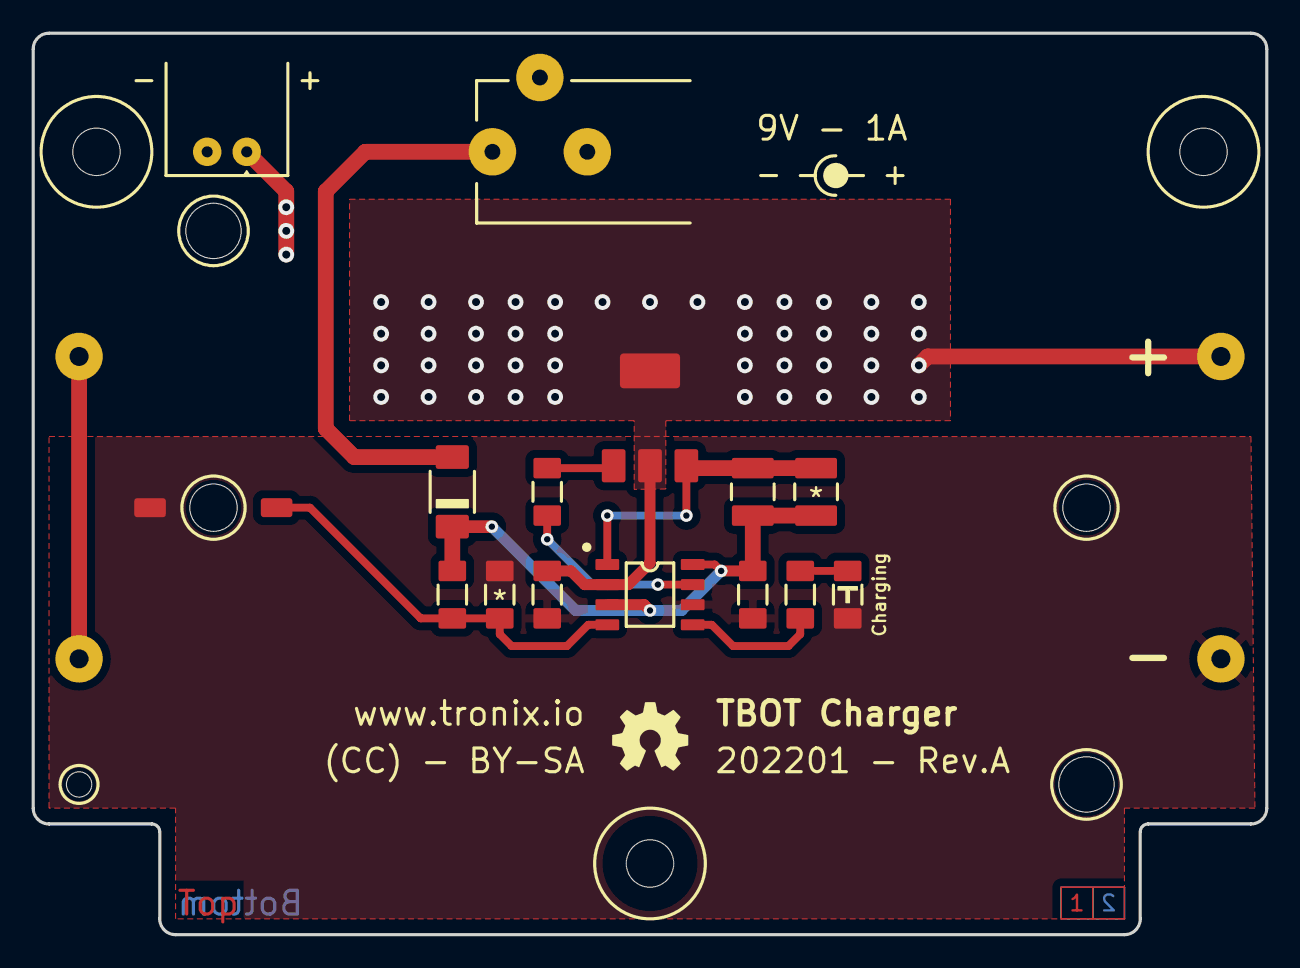
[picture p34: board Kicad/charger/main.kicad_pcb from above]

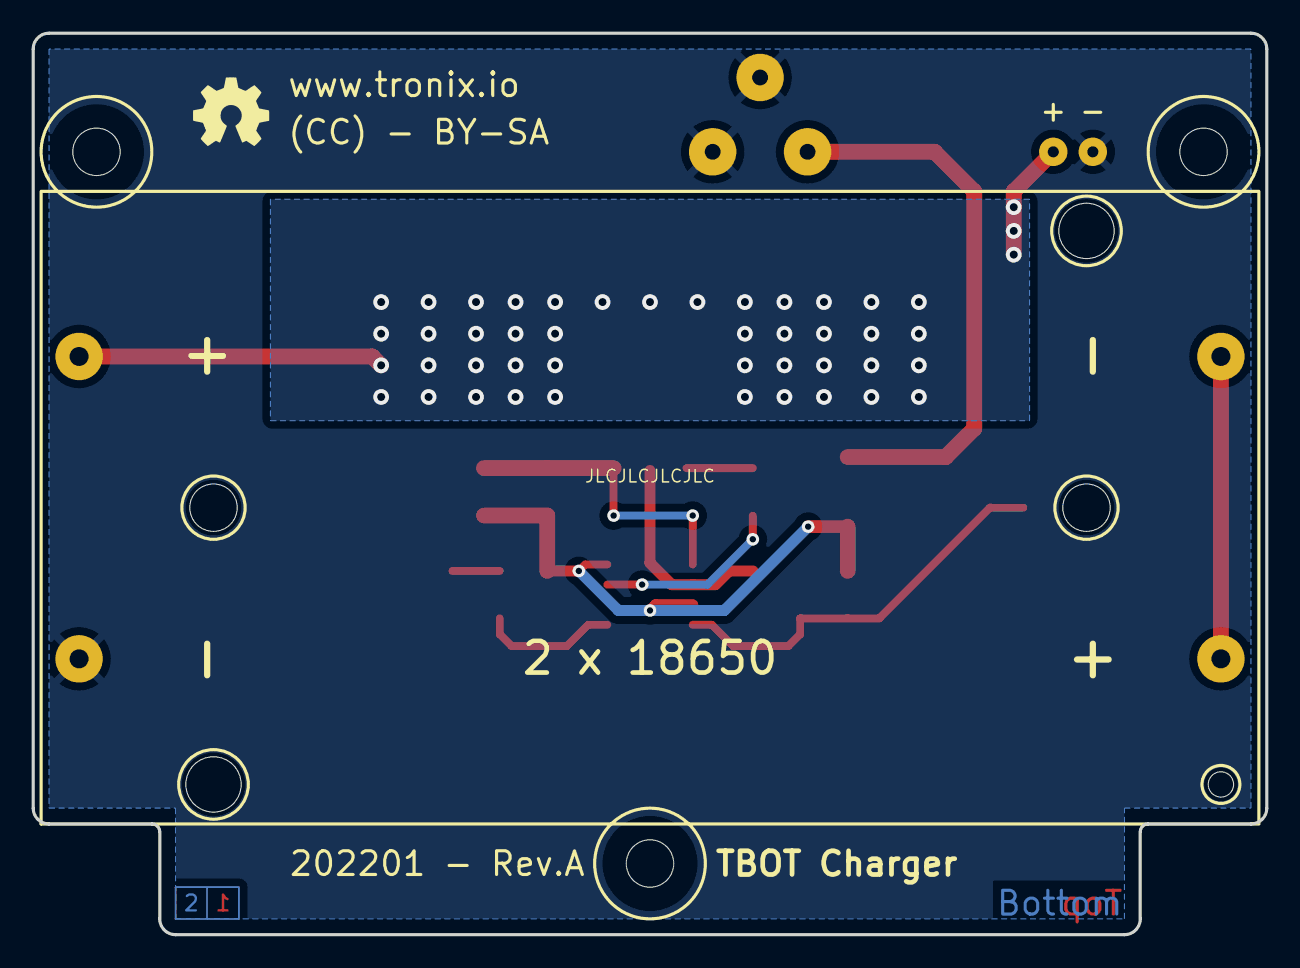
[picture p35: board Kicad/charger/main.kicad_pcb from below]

Board: 2 copper layers, 78.0 x 57.0 mm, 21 parts (5 on the bottom side), 11 nets.

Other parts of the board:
GB: LOGO; OSHW-5MM
GT: LOGO; OSHW-5MM

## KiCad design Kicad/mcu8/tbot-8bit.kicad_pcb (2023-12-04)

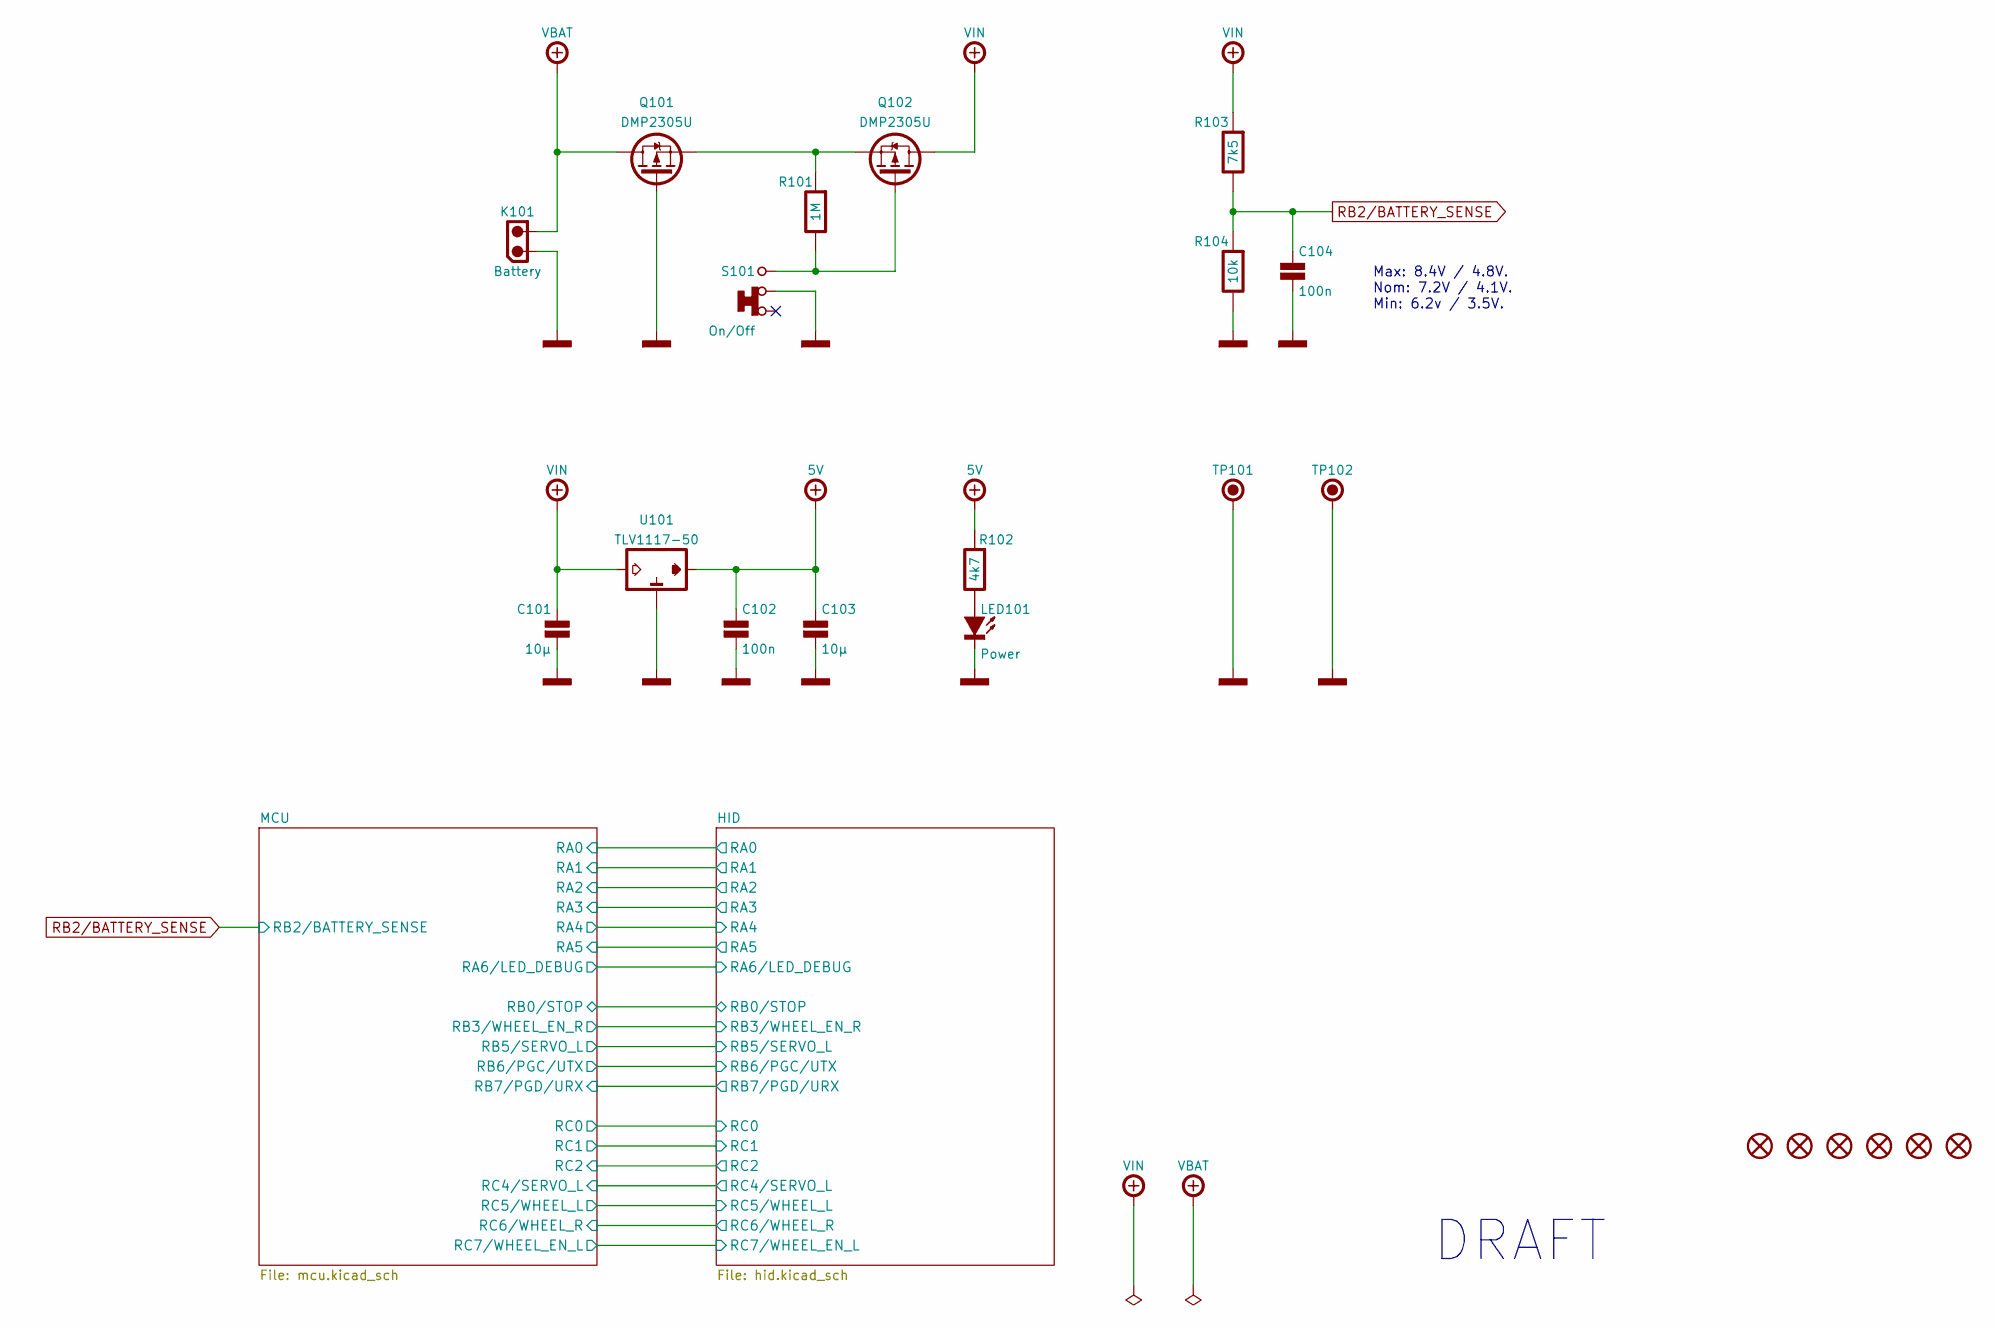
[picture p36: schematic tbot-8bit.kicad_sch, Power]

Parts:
C101, C103: 10µ; CAPACITOR-SMD-1206; Voltage 25V; Tolerance 5%; Mouser 80-C1206C106J3R
C102, C104: 100n; CAPACITOR-SMD-1206; Voltage 50V; Tolerance 5%; Mouser 80-C1206C104J5R
H101, H102, H103, H104, H105, H106: MOUNTING-HOLE-3MM-MASK
K101: Battery; MOLEX-22057025; Mouser 538-22-05-7025
LED101: Power; LED-SMD-1206; Mouser 604-APTR3216-VFX
Q101, Q102: DMP2305U; SOT-23-3; Mouser 621-DMP2305U-7
R101: 1M; RESISTOR-SMD-1206; Tolerance 5%; Mouser 660-RK73B2BTTDD105J
R102: 4k7; RESISTOR-SMD-1206; Tolerance 5%; Mouser 660-RK73B2BTTDD472J
R103: 7k5; RESISTOR-SMD-1206; Tolerance 5%; Mouser 660-RK73B2BTTD752J
R104: 10k; RESISTOR-SMD-1206; Tolerance 5%; Mouser 660-RK73B2BTTDD103J
S101: On/Off; E-SWITCH-200USPXT1A1M2RE; Mouser 612-200USP1T1A1M2RE
TP101: GND; KEYSTONE-5006; Mouser 534-5006
TP102: GND; KEYSTONE-2000-3; Mouser 534-2000-3
U101: TLV1117-50; SOT-223-3; Mouser 595-TLV1117-50CDC

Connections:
+5V: C102.1, C103.1, R102.2, U101.2 (VO); also elsewhere on the board
+VBAT: K101.2, Q101.3 (D)
+VIN: C101.1, Q102.3 (D), R103.2, U101.3 (VI); also elsewhere on the board
GND: C101.2, C102.2, C103.2, C104.2, K101.1, LED101.1 (C), Q101.1 (G), R104.1, S101.2, TP101.1, TP102.1, U101.1 (GND); also elsewhere on the board
unnamed: LED101.2 (A), R102.1
unnamed: Q101.2 (S), Q102.2 (S), R101.2
unnamed: Q102.1 (G), R101.1, S101.3
RB2/BATTERY_SENSE: C104.1, R103.1, R104.2

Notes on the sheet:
Max: 8.4V / 4.8V. Nom: 7.2V / 4.1V. Min: 6.2v / 3.5V.
DRAFT

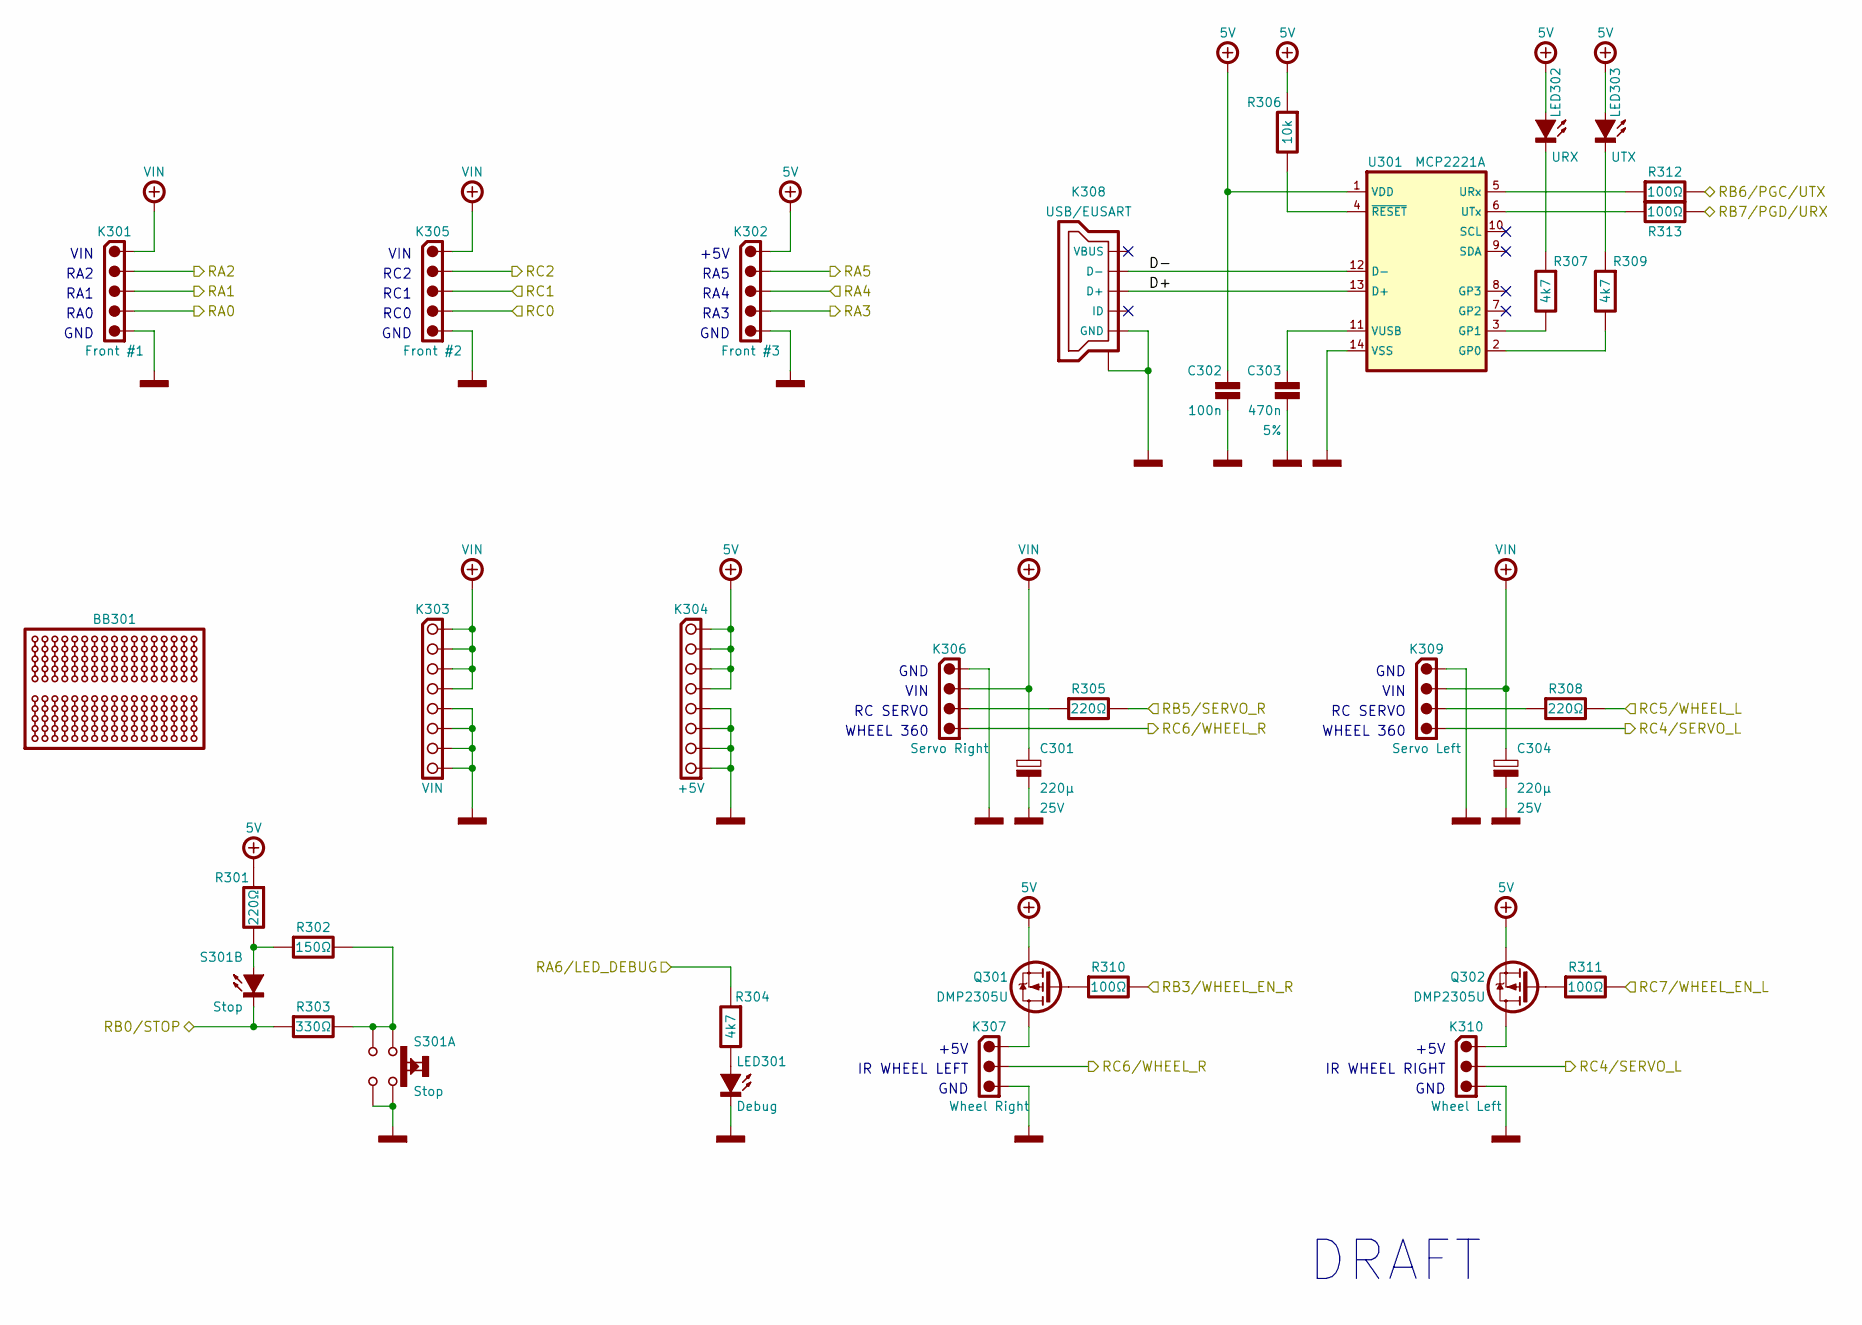
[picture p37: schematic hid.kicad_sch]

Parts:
BB301: BREADBOARD-170; Mouser 854-BB170
C301, C304: 220µ; CAPACITOR-ELECTROLYTIC-RADIAL-080-115-035; Voltage 25V; Tolerance 20%; Mouser 647-UVZ1E221MPD
C302: 100n; CAPACITOR-SMD-1206; Voltage 50V; Tolerance 5%; Mouser 80-C1206C104J5R
C303: 470n; CAPACITOR-SMD-1206; Voltage 50V; Tolerance 5%; Mouser 791-1206B474J500CT
K301: Front #1; MOLEX-532530570; Mouser 538-53253-0570
K302: Front #3; MOLEX-532530570; Mouser 538-53253-0570
K303: VIN; HARWIN-M20-782084x; Mouser 855-M20-782084
K304: +5V; HARWIN-M20-782084x; Mouser 855-M20-782084
K305: Front #2; MOLEX-532530570; Mouser 538-53253-0570
K306: Servo Right; HARWIN-M20-999044x; Mouser 855-M20-999044
K307: Wheel Right; MOLEX-532530370; Mouser 538-53253-0370
K308: USB/EUSART; USB-TYPE-B-MICRO-TH; Mouser 649-10118193-0001LF
K309: Servo Left; HARWIN-M20-999044x; Mouser 855-M20-999044
K310: Wheel Left; MOLEX-532530370; Mouser 538-53253-0370
LED301: Debug; LED-SMD-1206; Mouser 604-APTR3216-VFX
LED302: URX; LED-SMD-1206; Mouser 604-APTR3216-VFX
LED303: UTX; LED-SMD-1206; Mouser 604-APTR3216-VFX
Q301, Q302: DMP2305U; SOT-23-3; Mouser 621-DMP2305U-7
R301, R305, R308: 220Ω; RESISTOR-SMD-1206; Tolerance 5%; Mouser 660-RK73B2BTTDD221J
R302: 150Ω; RESISTOR-SMD-1206; Tolerance 5%; Mouser 660-RK73B2BTTDD151J
R303: 330Ω; RESISTOR-SMD-1206; Tolerance 5%; Mouser 660-RK73B2BTTDD331J
R304, R307, R309: 4k7; RESISTOR-SMD-1206; Tolerance 5%; Mouser 660-RK73B2BTTDD472J
R306: 10k; RESISTOR-SMD-1206; Tolerance 5%; Mouser 660-RK73B2BTTDD103J
R310, R311, R312, R313: 100Ω; RESISTOR-SMD-1206; Tolerance 5%; Mouser 660-RK73B2BTTDD101J
S301: Stop; OMRON-B3W9000-X1; Mouser 653-B3W-9000-R1R
U301: MCP2221A; SOIC-14; Mouser 579-MCP2221A-I/SL

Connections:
+5V: C302.1, K302.1, K304.1, K304.2, K304.3, K304.4, LED302.2 (A), LED303.2 (A), Q301.2 (S), Q302.2 (S), R301.2, R306.2, U301.1 (VDD); also elsewhere on the board
+VIN: C301.1, C304.1, K301.1, K303.1, K303.2, K303.3, K303.4, K305.1, K306.2, K309.2; also elsewhere on the board
/HID/D+: K308.3 (D+), U301.13 (D+)
/HID/D-: K308.2 (D-), U301.12 (D-)
/HID/RA0: K301.4; also elsewhere on the board
/HID/RA1: K301.3; also elsewhere on the board
/HID/RA2: K301.2; also elsewhere on the board
/HID/RA3: K302.4; also elsewhere on the board
/HID/RA4: K302.3; also elsewhere on the board
/HID/RA5: K302.2; also elsewhere on the board
/HID/RA6/LED_DEBUG: R304.2; also elsewhere on the board
/HID/RB0/STOP: R303.2, S301.5 (C); also elsewhere on the board
/HID/RB3/WHEEL_EN_R: R310.1; also elsewhere on the board
/HID/RB5/SERVO_R: R305.1
/HID/RC0: K305.4; also elsewhere on the board
/HID/RC1: K305.3; also elsewhere on the board
/HID/RC2: K305.2; also elsewhere on the board
/HID/RC4/SERVO_L: K309.4, K310.2; also elsewhere on the board
/HID/RC5/WHEEL_L: R308.1; also elsewhere on the board
/HID/RC6/WHEEL_R: K306.4, K307.2; also elsewhere on the board
/HID/RC7/WHEEL_EN_L: R311.1; also elsewhere on the board
GND: C301.2, C302.2, C303.2, C304.2, K301.5, K302.5, K303.5, K303.6, K303.7, K303.8, K304.5, K304.6, K304.7, K304.8, K305.5, K306.1, K307.3, K308.5 (GND), K308.SH (SHIELD), K309.1, K310.3, LED301.1 (C), S301.3, S301.4, U301.14 (VSS); also elsewhere on the board
unnamed: K306.3, R305.2
unnamed: K309.3, R308.2
unnamed: LED301.2 (A), R304.1
unnamed: LED302.1 (C), R307.2
unnamed: LED303.1 (C), R309.2
unnamed: K307.1, Q301.3 (D)
unnamed: Q301.1 (G), R310.2
unnamed: K310.1, Q302.3 (D)
unnamed: Q302.1 (G), R311.2
unnamed: R302.1, R303.1, S301.1, S301.2
unnamed: R301.1, R302.2, S301.6 (A)
unnamed: R309.1, U301.2 (GP0)
unnamed: R307.1, U301.3 (GP1)
unnamed: R312.2, U301.5 (URx)
unnamed: R313.2, U301.6 (UTx)
unnamed: C303.1, U301.11 (VUSB)
unnamed: R306.1, U301.4 (~RESET)
RB6/PGC/UTX: R312.1; also elsewhere on the board
RB7/PGD/URX: R313.1; also elsewhere on the board

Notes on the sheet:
GND
RC0
IR WHEEL RIGHT
VIN
IR WHEEL LEFT
+5V
RA2
RA5
RC1
WHEEL 360
RA3
RC SERVO
RA4
DRAFT
RA0
RC2
RA1

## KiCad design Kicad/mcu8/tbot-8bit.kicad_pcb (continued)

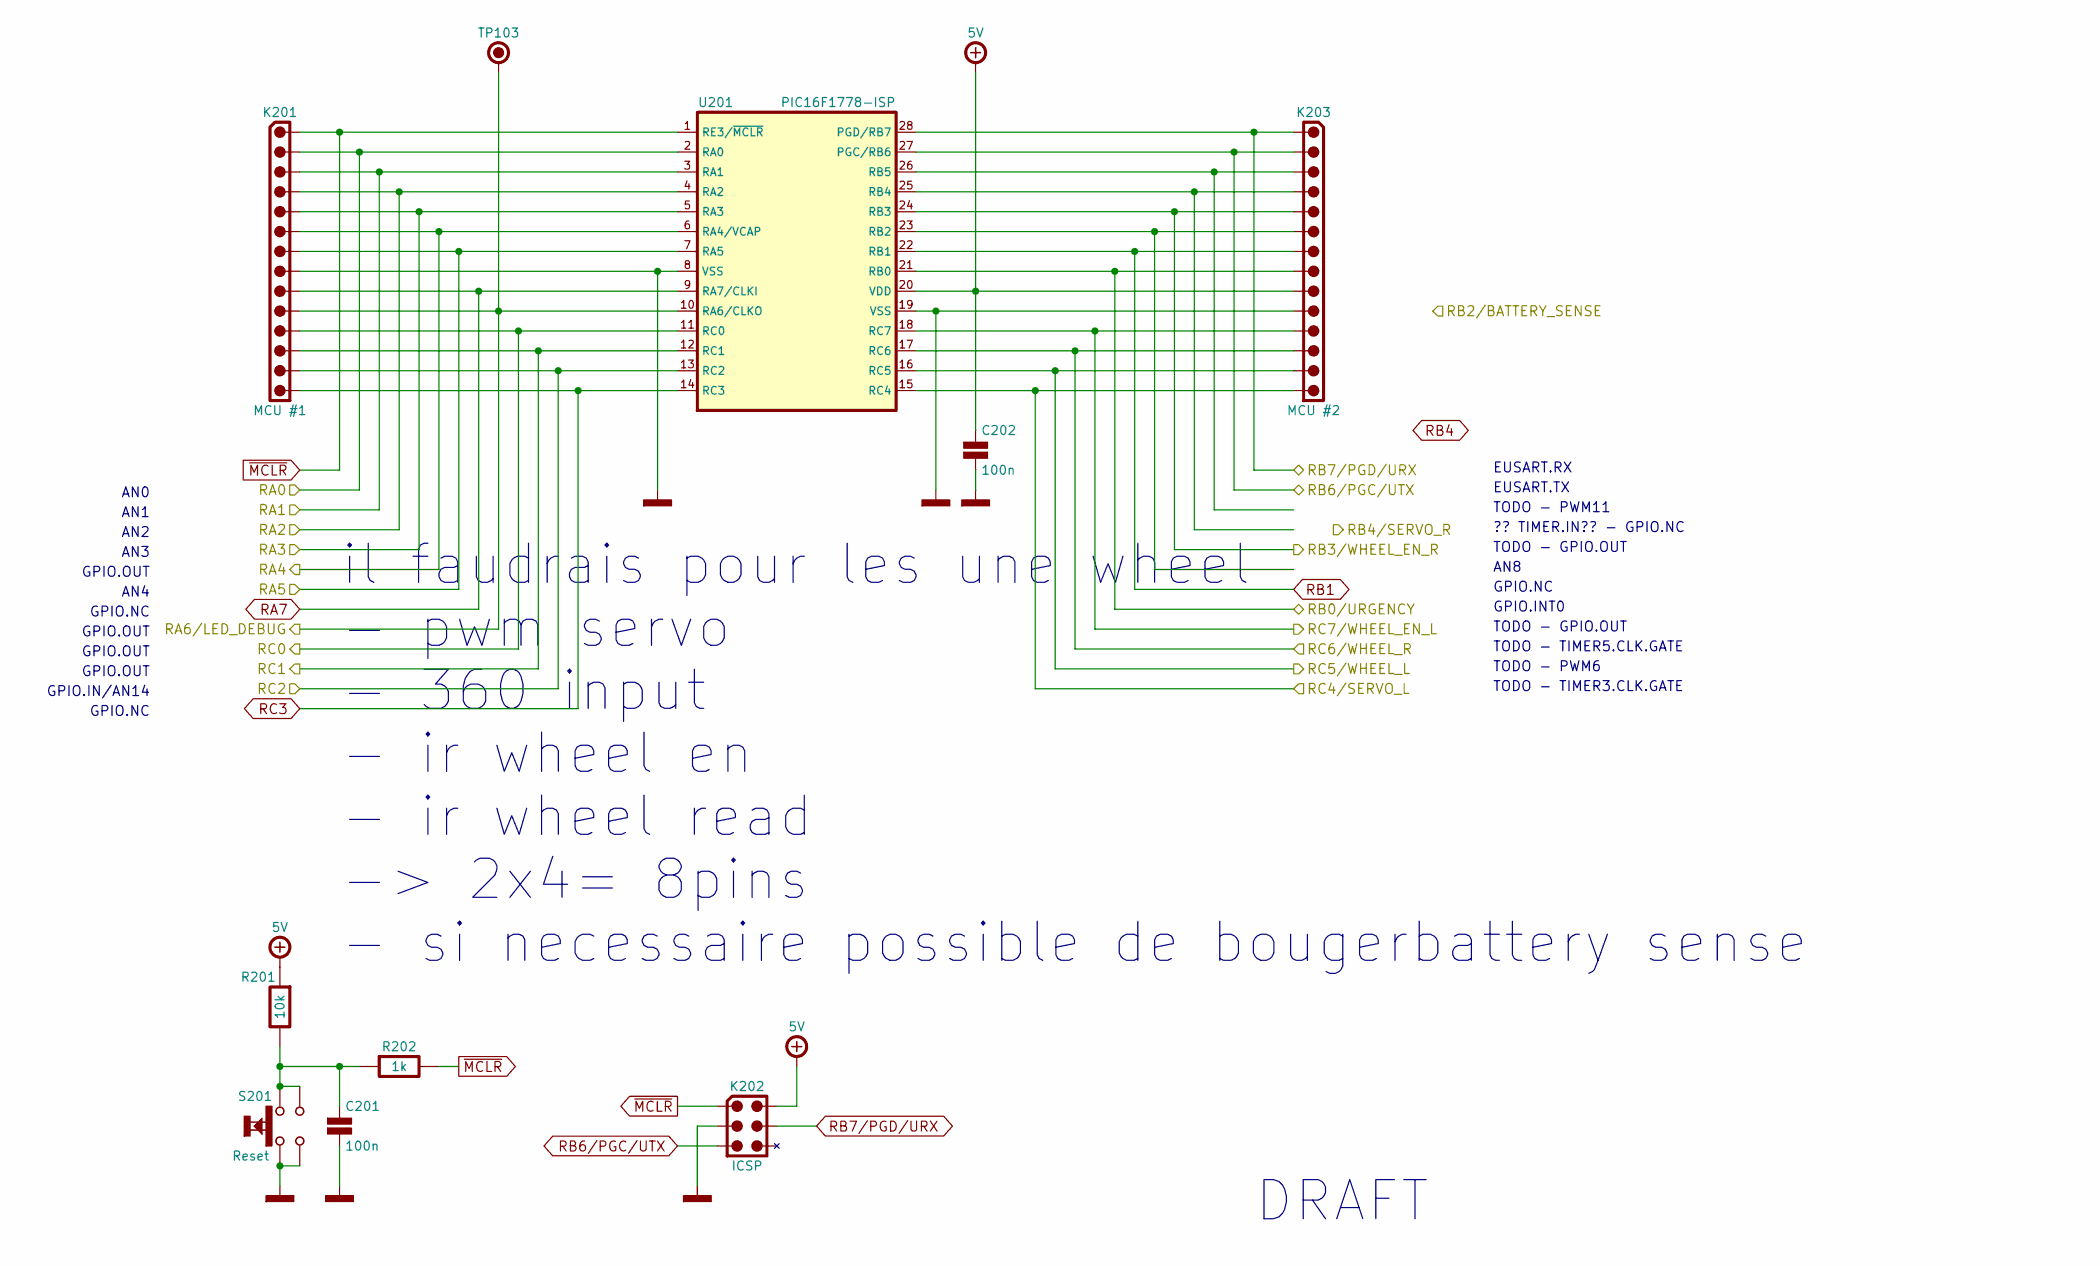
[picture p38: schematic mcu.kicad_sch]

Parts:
C201, C202: 100n; CAPACITOR-SMD-1206; Voltage 50V; Tolerance 5%; Mouser 80-C1206C104J5R
K201: MCU #1; HARWIN-M20-999144x; Mouser 855-M20-999144
K202: ICSP; HARWIN-M20-998034x; Mouser 855-M20-998034
K203: MCU #2; HARWIN-M20-999144x; Mouser 855-M20-999144
R201: 10k; RESISTOR-SMD-1206; Tolerance 5%; Mouser 660-RK73B2BTTDD103J
R202: 1k; RESISTOR-SMD-1206; Tolerance 5%; Mouser 660-RK73B2BTTDD102J
S201: Reset; ALPS-SKRPAC; Mouser 688-SKRPACE010
TP103: Debug; KEYSTONE-2000-3; Mouser 534-2000-3
U201: PIC16F1778-ISP; DIP-28-W762; Mouser 579-PIC16F1778-I/SP

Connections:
+5V: C202.1, K202.2, K203.9, R201.2, U201.20 (VDD); also elsewhere on the board
/HID/RA0: K201.2, U201.2 (RA0); also elsewhere on the board
/HID/RA1: K201.3, U201.3 (RA1); also elsewhere on the board
/HID/RA2: K201.4, U201.4 (RA2); also elsewhere on the board
/HID/RA3: K201.5, U201.5 (RA3); also elsewhere on the board
/HID/RA4: K201.6, U201.6 (RA4/VCAP); also elsewhere on the board
/HID/RA5: K201.7, U201.7 (RA5); also elsewhere on the board
/HID/RA6/LED_DEBUG: K201.10, U201.10 (RA6/CLKO); also elsewhere on the board
/HID/RB0/STOP: K203.8, U201.21 (RB0); also elsewhere on the board
/HID/RB3/WHEEL_EN_R: K203.5, U201.24 (RB3); also elsewhere on the board
/HID/RC0: K201.11, U201.11 (RC0); also elsewhere on the board
/HID/RC1: K201.12, U201.12 (RC1); also elsewhere on the board
/HID/RC2: K201.13, U201.13 (RC2); also elsewhere on the board
/HID/RC4/SERVO_L: K203.14, U201.15 (RC4); also elsewhere on the board
/HID/RC5/WHEEL_L: K203.13, U201.16 (RC5); also elsewhere on the board
/HID/RC6/WHEEL_R: K203.12, U201.17 (RC6); also elsewhere on the board
/HID/RC7/WHEEL_EN_L: K203.11, U201.18 (RC7); also elsewhere on the board
GND: C201.2, C202.2, K201.8, K202.3, K203.10, S201.1, S201.2, U201.8 (VSS), U201.19 (VSS); also elsewhere on the board
unnamed: C201.1, R201.1, R202.2, S201.3, S201.4
unnamed: K203.3, U201.26 (RB5)
unnamed: K203.4, U201.25 (RB4)
unnamed: K203.6, U201.23 (RB2)
RA7: K201.9, U201.9 (RA7/CLKI)
RB1: K203.7, U201.22 (RB1)
RB6/PGC/UTX: K202.5, K203.2, U201.27 (PGC/RB6); also elsewhere on the board
RB7/PGD/URX: K202.4, K203.1, U201.28 (PGD/RB7); also elsewhere on the board
RC3: K201.14, U201.14 (RC3)
~MCLR: K201.1, K202.1, R202.1, U201.1 (RE3/~MCLR)

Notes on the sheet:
AN2
AN8
AN1
GPIO.OUT
GPIO.NC
?? TIMER.IN?? - GPIO.NC
AN3
il faudrais pour les une wheel - pwm servo - 360 input - ir wheel en - ir wheel read -> 2x4= 8pins - si necessaire possible de bougerbattery sense
TODO - GPIO.OUT
AN4
TODO - PWM6
GPIO.IN/AN14
EUSART.TX
DRAFT
GPIO.INT0
TODO - TIMER3.CLK.GATE
TODO - TIMER5.CLK.GATE
TODO - PWM11
EUSART.RX
AN0


Board: 2 copper layers, 80.0 x 100.0 mm, 90 parts (0 on the bottom side), 53 nets.

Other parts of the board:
TP201: Debug; KEYSTONE-2000-3
kibuzzard-627FC8D5: G***; kibuzzard-627FC8D5
kibuzzard-627FC68B: G***; kibuzzard-627FC68B
kibuzzard-627FC69F: G***; kibuzzard-627FC69F
kibuzzard-627FC691: G***; kibuzzard-627FC691
kibuzzard-627FC699: G***; kibuzzard-627FC699
kibuzzard-627FC905: G***; kibuzzard-627FC905
kibuzzard-627FC965: G***; kibuzzard-627FC965
kibuzzard-627FC987: G***; kibuzzard-627FC987
kibuzzard-6277F9C5: G001; kibuzzard-6277F9C5
kibuzzard-6567BC68, kibuzzard-6567BC68#2, kibuzzard-6567BC68#3: G***; kibuzzard-6567BC68
kibuzzard-62763CDA, kibuzzard-62763CDA#2, kibuzzard-62763CDA#4: G003; kibuzzard-62763CDA
kibuzzard-62763CDA#3: G005; kibuzzard-62763CDA
kibuzzard-62763D9F, kibuzzard-62763D9F#2: G004; kibuzzard-62763D9F
kibuzzard-62763D72: G002; kibuzzard-62763D72
kibuzzard-62763E7E: G010; kibuzzard-62763E7E
kibuzzard-62763E7E#2: G007; kibuzzard-62763E7E
kibuzzard-6294682B: G***; kibuzzard-6294682B
kibuzzard-62946869: G***; kibuzzard-62946869

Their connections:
/HID/RA6/LED_DEBUG: TP201.1; also elsewhere on the board

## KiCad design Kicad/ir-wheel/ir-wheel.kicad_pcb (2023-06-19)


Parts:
C1: 100n; CAPACITOR-SMD-1206; Voltage 50V; Tolerance 10%; Mouser 187-CL31B106KAHNFNE
C2: 1µ; CAPACITOR-SMD-1206; Voltage 16V; Tolerance 10%; Mouser 80-C1206C105K4R
C3: 1n; CAPACITOR-SMD-1206; Voltage 50V; Tolerance 10%; Mouser 80-C1206C102K5R
H1, H2, H3, H4: MOUNTING-HOLE-3MM-MASK
IC1, IC2: OPB606; OPB-606; Mouser 828-OPB606
K1: Right; MOLEX-532540370; Mouser 538-53254-0370
K2: Left; MOLEX-532540370; Mouser 538-53254-0370
P1: 200k; TC33X; Mouser 652-TC33X-1-204E
R1: 220Ω; RESISTOR-SMD-1206; Tolerance 5%; Mouser 660-RK73B2BTTDD221J
R2: 100k; RESISTOR-SMD-1206; Tolerance 5%; Mouser 660-RK73B2BTTDD104J
R3: 10k; RESISTOR-SMD-1206; Tolerance 5%; Mouser 660-RK73B2BTTDD103J
U1: MCP6541; SOT-23-5; Mouser 579-MCP6541UT-E/OT

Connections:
+5V: C1.1, C2.1, IC1.3 (COLLECTOR), IC2.3 (COLLECTOR), K1.1, K2.1, P1.1, R1.2, R3.2, U1.5 (VDD)
GND: C1.2, C2.2, C3.2, IC1.2 (CATHODE), IC2.2 (CATHODE), K1.3, K2.3, P1.3, R2.1, U1.2 (VSS)
unnamed: C3.1, K1.2, K2.2, R3.1, U1.4
unnamed: IC1.1 (ANODE), IC2.1 (ANODE), R1.1
unnamed: IC1.4 (EMITTER), IC2.4 (EMITTER), R2.2, U1.3 (-)
unnamed: P1.2, U1.1 (+)

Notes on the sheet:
* For Open-Drain Output Comparator (eg: MCP6566U).
DRAFT

Board: 2 copper layers, 22 parts (5 on the bottom side), 6 nets, no tracks yet.

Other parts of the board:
GB: LOGO; OSHW-5MM
GT: LOGO; OSHW-5MM
kibuzzard-629B895E: G***; kibuzzard-629B895E
kibuzzard-629B896F: G***; kibuzzard-629B896F
kibuzzard-629B8952: G***; kibuzzard-629B8952
kibuzzard-629B8965: G***; kibuzzard-629B8965

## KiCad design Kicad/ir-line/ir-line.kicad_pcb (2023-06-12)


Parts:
C1, C2, C3, C4, C5: 2n2; CAPACITOR-SMD-1206; Voltage 50V; Tolerance 10%; Mouser 80-C1206C222K5R
C6, C7: 1µ; CAPACITOR-SMD-1206; Voltage 16V; Tolerance 10%; Mouser 80-C1206C105K4R
C8, C9: 10n; CAPACITOR-SMD-1206; Voltage 50V; Tolerance 20%; Mouser 80-C1206C103M5R
H1, H2: MOUNTING-HOLE-3MM-MASK
IC1, IC2, IC3, IC4, IC5: CNY70; VISHAY-CNY70; Mouser 782-CNY70
IC6, IC7: TPS92612; SOT-23-5; Mouser 595-TPS92612DBVR
K1: FRONT #1; MOLEX-532530570; Mouser 538-53253-0570
K2: FRONT #2; MOLEX-532530570; Mouser 538-53253-0570
R1: 100k; RESISTOR-SMD-1206; Tolerance 5%; Mouser 660-RK73B2BTTDD104J
R2, R3, R4, R5, R6, R7, R8: 220Ω; RESISTOR-SMD-1206; Tolerance 5%; Mouser 660-RK73B2BTTDD221J

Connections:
+5V: C1.1, C2.1, C3.1, C4.1, C5.1, K2.1
GND: C6.2, C7.2, C8.2, C9.2, IC1.4 (EMITTER), IC2.2 (CATHODE), IC2.4 (EMITTER), IC3.4 (EMITTER), IC4.4 (EMITTER), IC5.2 (CATHODE), IC5.4 (EMITTER), IC6.1 (GND), IC7.1 (GND), K1.5, K2.5, R1.1
IR 1: K1.4, R2.2
IR 2: K1.3, R6.2
IR 3: K1.2, R5.2
IR 4: K2.4, R4.2
IR 5: K2.2, R3.2
IR ENABLE: IC6.2 (PWM), IC7.2 (PWM), K2.3, R1.2
LED 15: C8.1, IC1.1 (ANODE), IC6.5 (OUT)
LED 234: C9.1, IC3.1 (ANODE), IC7.5 (OUT)
unnamed: IC1.2 (CATHODE), IC2.1 (ANODE)
unnamed: C1.2, IC1.3 (COLLECTOR), R2.1
unnamed: C2.2, IC2.3 (COLLECTOR), R3.1
unnamed: IC3.2 (CATHODE), IC4.1 (ANODE)
unnamed: C3.2, IC3.3 (COLLECTOR), R4.1
unnamed: IC4.2 (CATHODE), IC5.1 (ANODE)
unnamed: C4.2, IC4.3 (COLLECTOR), R5.1
unnamed: C5.2, IC5.3 (COLLECTOR), R6.1
unnamed: IC6.4 (IN), R7.1
unnamed: IC7.4 (IN), R8.1
VIN: C6.1, C7.1, IC6.3 (SUPPLY), IC7.3 (SUPPLY), K1.1, R7.2, R8.2

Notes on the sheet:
(10n)
VDD: 3V3 or 5V.
DRAFT
Iled = 0.098 / 4.7 = 20mA



Board: 2 copper layers, 74.0 x 20.0 mm, 30 parts (17 on the bottom side), 21 nets.

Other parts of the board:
GB: LOGO; OSHW-5MM
GT: LOGO; OSHW-5MM

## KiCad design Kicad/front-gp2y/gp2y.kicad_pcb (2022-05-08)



Board: 2 copper layers, 48.0 x 35.0 mm, 18 parts (12 on the bottom side), 6 nets.

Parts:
C1, C2: 1µ; CAPACITOR-1206
GB: LOGO; OSHW-5MM
GT: LOGO; OSHW-5MM
H1, H2: MOUNTING-HOLE-MASK-3MM; M3-MASK
IC1: MCP1755-50; SOT-23-5
IR1: SHARP-GP2Y0xx1; SHARP-GP2Y0A
K1: GP2Y; MOLEX-532540370
K2: MCU; MOLEX-532540470
LED1: Power; LED-1206
R1: 100K; RESISTOR-1206
R2: 4K7; RESISTOR-1206
R3: 10K; RESISTOR-1206
kibuzzard-6277EDE4: G002; kibuzzard-6277EDE4
kibuzzard-6277EDE4#2: G004; kibuzzard-6277EDE4
kibuzzard-6277EE2E: G003; kibuzzard-6277EE2E
kibuzzard-6277EE50: G001; kibuzzard-6277EE50

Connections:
+5V: C2.1, IC1.5 (VOUT), K1.3, R2.1, R3.1
GND: C1.2, C2.2, IC1.2 (GND), K1.2, K2.1, LED1.1 (K), R1.2
GP2Y_OUT: K1.1, K2.3, R3.2
MCU_ENABLE: IC1.3 (~SHDN), K2.2, R1.1
unnamed: LED1.2 (A), R2.2
VIN: C1.1, IC1.1 (VIN), K2.4

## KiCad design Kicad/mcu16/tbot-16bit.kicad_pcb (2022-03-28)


Board: 2 copper layers, 80.0 x 100.0 mm, 61 parts (0 on the bottom side), 43 nets.

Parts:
BB401: BREADBOARD-170
C101, C103, C301, C302, C303, C402: 100n; CAPACITOR-1206
C102, C104, C304: 10µ; CAPACITOR-1206
C401, C404: 220µ/25V; CAPACITOR-ELECTROLYTIC-RADIAL-080-115-035
H101, H102, H103, H104, H105, H106: MOUNTING-HOLE-MASK-3MM; M3-MASK
H107, H108: MOUNTING-HOLE-3MM; M3
IC101: TLV1117-33-SOT; SOT-223-3
IC301: PIC24FJxxGA002-ISP; DIP-28-W762
IC401: MCP2221A; SOIC-SL-14
K101: Battery; MOLEX-22057025
K301: MCU 1; HARWIN-M20-999144x
K302: ICSP; HARWIN-M20-998034x
K303: MCU 2; HARWIN-M20-999144x
K401: FRONT #1; MOLEX-532530570
K402: FRONT #2; MOLEX-532530570
K403: VIN; HARWIN-M20-782084x
K404: +5V; HARWIN-M20-782084x
K405: FRONT #3; MOLEX-532530570
K406: SERVO LEFT; HARWIN-M20-999044x
K407: USB/UART; FCI-USB-TYPE-B-MICRO-THT
K408: SERVO RIGHT; HARWIN-M20-999044x
LED101: Power; LED-1206
LED401: Debug; LED-1206
LED402: URX; LED-1206
LED403: UTX; LED-1206
R101: 16K; RESISTOR-1206
R102: 1M; RESISTOR-1206
R103, R301, R407: 10K; RESISTOR-1206
R104, R404, R408, R410: 1K2; RESISTOR-1206
R302: 1K; RESISTOR-1206
R401, R406, R411: 220Ω; RESISTOR-1206
R402: 150Ω; RESISTOR-1206
R403: 330Ω; RESISTOR-1206
S101: Power; E-SWITCH-200USPXT1A1M2RE
S301: Reset; ALPS-SKRPAC
S401: EMERGENCY; E-SWITCH-TL1240XQ1JXXX
T101, T102: DMP2305U; SOT-23-3
TP101, TP102: GND; KEYSTONE-5006

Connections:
+3V3: C103.1, C104.1, C302.1, C303.1, C402.1, IC101.2 (VO), IC301.13 (VDD), IC301.28 (VDD), IC401.1 (VDD), IC401.11 (VUSB), K301.13, K302.2 (VDD), K303.1, K402.1, K404.1, K404.2, K404.3, K404.4, LED402.2 (A), LED403.2 (A), R104.2, R301.2, R401.2, R407.2
/HID/D+: IC401.13 (D+), K407.3 (D+)
/HID/D-: IC401.12 (D-), K407.2 (D-)
/HID/RA1: IC301.3 (RA1), K301.3, K401.4
/HID/RA3/LED: IC301.10 (RA3/CLKO), K301.10, R404.2
/HID/RB0: IC301.4 (RB0/PGD1), K301.4, K401.3
/HID/RB1: IC301.5 (RB1/PGC1), K301.5, K401.2
/HID/RB2: IC301.6 (RB2), K301.6, K402.2
/HID/RB3: IC301.7 (RB3), K301.7, K402.4
/HID/RB4: IC301.11 (RB4), K301.11, K402.3
/HID/RB6/SERVO_R: IC301.15 (RB6), K303.14, R411.1
/HID/RB7/EMERGENCY: IC301.16 (RB7), K303.13, R403.2, S401.5 (C)
/HID/RB8/WHEEL_R: IC301.17 (RB8), K303.12, K408.4
/HID/RB9: IC301.18 (RB9), K303.11, K405.4
/HID/RB10/PGD/URX: IC301.21 (RB10), IC401.6 (UTx), K302.4 (PGD), K303.8
/HID/RB11/PGC/UTX: IC301.22 (RB11), IC401.5 (URx), K302.5 (PGC), K303.7
/HID/RB12: IC301.23 (RB12), K303.6, K405.3
/HID/RB13: IC301.24 (RB13), K303.5, K405.2
/HID/RB14/WHEEL_L: IC301.25 (RB14), K303.4, K406.4
/HID/RB15/SERVO_L: IC301.26 (RB15), K303.3, R406.1
GND: C101.2, C102.2, C103.2, C104.2, C301.2, C302.2, C303.2, C304.2, C401.2, C402.2, C404.2, IC101.1 (GND), IC301.8 (VSS), IC301.19 (DISVREG), IC301.27 (VSS), IC401.14 (VSS), K101.1, K301.8, K302.3 (GND), K303.2, K303.10, K401.5, K402.5, K403.5, K403.6, K403.7, K403.8, K404.5, K404.6, K404.7, K404.8, K405.5, K406.1, K407.5 (GND), K407.6 (SHIELD), K408.1, LED101.1 (K), LED401.1 (K), R103.1, S101.2, S301.1, S301.2, S401.1, S401.2, T101.1 (G), TP101.1, TP102.1
unnamed: C301.1, R301.1, R302.2, S301.3, S301.4
unnamed: C304.1, IC301.20 (VCAP/VDDCORE), K303.9
unnamed: IC401.2 (GP0), R410.1
unnamed: IC401.3 (GP1), R408.1
unnamed: IC401.4 (~RESET), R407.1
unnamed: K406.3, R406.2
unnamed: K408.3, R411.2
unnamed: LED101.2 (A), R104.1
unnamed: LED401.2 (A), R404.1
unnamed: LED402.1 (K), R408.2
unnamed: LED403.1 (K), R410.2
unnamed: R102.1, S101.3, T102.1 (G)
unnamed: R102.2, T101.2 (S), T102.2 (S)
unnamed: R401.1, R402.2, S401.6 (A)
unnamed: R402.1, R403.1, S401.3, S401.4
RA0/BATTERY_SENSE: C101.1, IC301.2 (RA0), K301.2, R101.1, R103.2
RA2: IC301.9 (RA2/CLKI), K301.9
RA4: IC301.12 (RA4), K301.12
RB5: IC301.14 (RB5), K301.14
VBAT: K101.2, T101.3 (D)
VIN: C102.1, C401.1, C404.1, IC101.3 (VI), K401.1, K403.1, K403.2, K403.3, K403.4, K405.1, K406.2, K408.2, R101.2, T102.3 (D)
~MCLR: IC301.1 (~MCLR), K301.1, K302.1 (~MCLR), R302.1

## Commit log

2022-01-04 TBOT Charger
    [tbot-charger.kicad_pcb, tbot-charger.kicad_sch]
2022-01-04 TBOT GP2Y
    [gp2y.kicad_pcb, gp2y.kicad_sch]
2022-01-04 TBOT HC-SR04
    [hc-sr04.kicad_pcb, hc-sr04.kicad_sch]
2022-01-04 TBOT IR Line
    [ir-line.kicad_pcb, ir-line.kicad_sch]
2022-01-04 TBOT MCU 8Bit
    [hid.kicad_sch, mcu.kicad_sch, power.kicad_sch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]
2022-01-04 TBOT MCU
    [hid.kicad_sch]
2022-01-15 Update GP2Y
    [gp2y.kicad_pcb, gp2y.kicad_sch]
2022-01-15 Update HC-SR04
    [hc-sr04.kicad_pcb, hc-sr04.kicad_sch]
2022-01-15 Update Charger
2022-01-15 Update IR-LINE
    [ir-line.kicad_pcb, ir-line.kicad_sch]
2022-01-15 Update MCU 8Bit
    [hid.kicad_sch, mcu.kicad_sch, power.kicad_sch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]
2022-01-16 Update MCU
    [hid.kicad_sch, mcu.kicad_sch, power.kicad_sch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]
2022-01-18 Update MCU8
    [hid.kicad_sch, mcu.kicad_sch, power.kicad_sch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]
2022-03-06 Create MCU 16Bits
    [hid.kicad_sch, mcu.kicad_sch, power.kicad_sch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]
2022-03-20 Create IR Wheel
    [ir-wheel.kicad_pcb, ir-wheel.kicad_sch]
2022-03-27 Update IR Line
    [ir-line.kicad_pcb, ir-line.kicad_sch]
2022-03-27 Update IR Wheel
    [ir-wheel.kicad_pcb, ir-wheel.kicad_sch]
2022-05-08 Add IR Wheel
    [ir-wheel.kicad_pcb, ir-wheel.kicad_sch]
2022-05-08 Update ADC
2022-05-08 Update Code PWM
2023-10-17 Up charger
    [main.kicad_pcb, main.kicad_sch]
2023-10-17 Up gp2y
    [gp2y-new.kicad_pcb, main.kicad_pcb, main.kicad_sch]
2023-10-17 Up hc-sr04
    [main-new.kicad_pcb, main.kicad_pcb, main.kicad_sch]
